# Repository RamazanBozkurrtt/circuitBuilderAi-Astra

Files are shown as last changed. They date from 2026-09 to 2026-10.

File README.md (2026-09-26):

# circuitBuilderAi-Astra

Product V1 is a two-board B2B ANC system: Board A (Controller + Audio AFE)
and Board B (Power + Stereo Class-D), with four microphone inputs and two
secondary speaker outputs.

The [Product V1 architecture](docs/product/ANC_B2B_Custom_PCB_2_Kart_Mimari_Tasarim_Dokumani_v1.0.docx)
is the product-level source. The [Phase R0 rebaseline](docs/rebaseline/phase_r0_b2b_two_board_rebaseline.md)
records its open decisions and the proposed repository migration.

The existing [KiCad project](hardware/kicad/) and earlier phase records are
**legacy four-output design history**, not Product V1 production files. Product
V1 KiCad projects have not been started.

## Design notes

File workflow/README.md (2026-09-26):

# Product V1 workflow

This directory holds process contracts, not electrical design. The controlled
checkpoint is `state/project_state.json`; the shared Board A/B signal-class
contract is `state/board_to_board_interface.json`. Actual findings go under
`validation/findings/`. Phase outputs remain in the normal `docs/`,
`hardware/` and `validation/` trees.

Install once: `python -m pip install -r workflow/requirements.txt`.

Run the current phase's machine checks:

```text
python workflow/gates/run.py
```

Preview a specific phase or a permitted transition without changing state:

```text
python workflow/gates/run.py --phase R6
python workflow/gates/run.py --next-phase R1
```

Exit code 0 means machine `PASS`, 2 means `BLOCKED`, and 1 means `FAIL`.
`PASS` means only that configured machine checks passed; the human/engineering
gate remains `NOT_EVALUATED`. A phase changes only after its human gate is
recorded and `state/project_state.json` is deliberately updated. The runner
does not advance phases or edit files.

The ERC, DRC, interface, pin and BOM hooks currently return
`NOT_AVAILABLE`. When one is required by a phase, the machine result is
`BLOCKED` until a real adapter and scoped verification artifact exist. Do not
replace `NOT_AVAILABLE` with a synthetic PASS.

The finding schema allows `accepted` and `deferred` statuses for review
history. A finding with `blocking: true` stops progression from its
`blocks_from_phase` onward until its status is `resolved`; acceptance or
deferral alone does not clear it. Each unresolved blocker must also appear in
the `open_blockers` state checkpoint with the same phase. This keeps later
blockers visible without blocking earlier verification work. The seven
product OPEN decisions are tracked separately from findings.

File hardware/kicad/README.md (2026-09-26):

# Legacy KiCad project

All KiCad files in this directory belong to the former single-board,
ADAU1978 / ADSP-21569 / TAS6424E-Q1, four-speaker architecture. Preserve
them as engineering history. They are **not** Product V1 production files or
schematic-entry authority.

Product V1 is the two-board design in
[`docs/product/`](../../docs/product/ANC_B2B_Custom_PCB_2_Kart_Mimari_Tasarim_Dokumani_v1.0.docx).
Its future Board A and Board B KiCad projects belong in separate directories
under `hardware/product_v1/` after a separately authorized schematic gate.

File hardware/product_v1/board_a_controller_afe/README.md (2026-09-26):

# Product V1 Board A

Controller + Audio AFE. Reserved for a separately authorized Board A KiCad
project. No Product V1 schematic or PCB exists here at R0.5.

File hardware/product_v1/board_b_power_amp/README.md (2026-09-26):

# Product V1 Board B

Power + Stereo Class-D. Reserved for a separately authorized Board B KiCad
project. No Product V1 schematic or PCB exists here at R0.5.

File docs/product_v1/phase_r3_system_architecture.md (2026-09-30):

# Product V1 Phase R3 system architecture and interface freeze

**Date:** 2026-09-28. **Authority:** the complete [two-board product architecture](../product/ANC_B2B_Custom_PCB_2_Kart_Mimari_Tasarim_Dokumani_v1.0.docx), [R1 requirements](phase_r1_product_requirements.md), [R2 manufacturer verification](phase_r2_component_verification.md), and its [evidence index](component_evidence_index.md). The project owner approved the R2 human gate before R3. This is a **system architecture contract**, not circuit, pin, connector, PCB or final acoustic approval. `CONFIRMED` means manufacturer/product evidence establishes the stated fact; `PROVISIONAL` means the selected architecture awaits R4 implementation proof; `OPEN` and `BLOCKED` identify missing evidence or a gate constraint. All four named ICs retain their R2 **PROVISIONALLY APPROVED** architecture status. Legacy devices and circuits are excluded.

## 1. Functional architecture and board ownership

```text
four external IM73A135V01 analog differential microphones
  -> Board A: four equivalent protected/filterable microphone entries
  -> Board A: four-channel analog AFE (network OPEN, no direct ADC connection assumed)
  -> Board A: TLV320ADC5140 ADC, four analog channels
  -> Board A: 96 kHz / four-slot TDM -> RT1062 SAI1 RX / DMA
  -> Board A: RT1062 ANC/FxLMS prototype, control and safety state machine
  -> Board A: SAI2 TX / DMA, stereo 96 kHz I2S
  -> controlled Board A-to-B interface
  -> Board B: TAS5825M, two BTL channels -> two secondary speakers
```

| Block | Owner | R3 classification and boundary |
| --- | --- | --- |
| Four electrically equivalent microphone channels | A | **CONFIRMED** product count/equality; IM73A135V01 **PROVISIONAL**. No reference/error/monitor role or placement assigned. |
| Differential entries, ESD/EMI/filter provisions and low-noise AFE | A | Provisions **CONFIRMED**; topology **OPEN**. R2 finds a direct mic-to-ADC loading conflict (mic ≥25 kΩ/leg; ADC ≤20 kΩ typical/leg). R4 must solve it without unequal channels. |
| TLV320ADC5140 and four-channel digitization | A | **PROVISIONAL** 96-kHz fixed-gain, AGC/DRE-off configuration supported by E-ADC-RATE Fig. 3-3. HPF, gain, phase and network **OPEN**. |
| RT1062 processing and DMA | A | **PROVISIONAL** resource architecture: separate SAI RX/TX with eDMA, no claimed final FxLMS capacity. Algorithm size and measured latency **OPEN**. |
| Stereo TAS5825M / BTL outputs | B | **PROVISIONAL** 96-kHz I2S architecture capable of a nominal 4-Ω load under the verified device limits. Final speaker impedance/choice and 12-V acoustic power **OPEN**. Speaker negatives never become signal or ground returns. |
| Protected input, 5-V buck, PVDD and local amp logic | B | Ownership **CONFIRMED**. Exact input range, protection/buck devices, current and thermal values **OPEN for R4/EVT**. |
| Bootable NOR, clock reference, USB and debug/programming | A | Ownership **CONFIRMED**; native NXP production route **PROVISIONAL**. Detailed pins/fuses/fixtures **OPEN for R4**. |
| Independent watchdog and cross-board safe request | A | Functional responsibility **CONFIRMED**. Independent monitor gates the enable line; Board B supplies fail-safe pull and local power/fault gating. Device and response timing **OPEN for R4**. |

Board A owns microphone entry and analog protection, ADC control, RT1062, external NOR, 24-MHz reference, both serial-audio masters, system I²C master, USB service, SWD/JTAG/pogo access, watchdog heartbeat/independent monitor and generation of its low-noise rails from Board B's 5 V. Board B owns external low-voltage DC entry, reverse polarity/OVP/OCP/eFuse functions, high-current protection, protected PVDD, 12-to-5-V buck, local 3.3-V amp logic, TAS5825M, output network/decoupling/thermal path, both BTL speaker connections, local hardware inhibit, and protected-power PGOOD/fault reporting. No functional ownership remains ambiguous; physical implementation details remain R4/R7 work.

## 2. Selected digital-audio and clock architecture

| Link | Transmitter / receiver | R3 baseline | Explicit clocks and voltage | Selection limit |
| --- | --- | --- | --- | --- |
| ADC to MCU | TLV320ADC5140 SDOUT slave transmitter → RT1062 **SAI1 RX clock master** | Four analog channels, 96,000 samples/s, 32-bit words in four 32-bit TDM slots; fixed gain, AGC/DRE off | `96,000 × 4 × 32 = 12,288,000 Hz` BCLK; 96,000-Hz FSYNC. ADC slave uses BCLK/FSYNC internal PLL, no ADC MCLK pin required. Both IOVDD/RT1062 SAI bank nominal 3.3 V. | E-ADC p.26 Table 6, E-ADC-RATE p.6 Fig.3-3 and E-MCU p.61 Table 50 establish endpoint rates. Exact SAI1 pin mux, edge polarity, divider, setup/hold, DMA and filter/HPF delay must be proven in R4. |
| MCU to amp | RT1062 **SAI2 TX clock master** → TAS5825M slave SDIN | Two channels, 96,000 samples/s, 32-bit words in two 32-bit I²S slots; amp process flow constrained to an R4 latency-measured profile | `96,000 × 2 × 32 = 6,144,000 Hz` BCLK; 96,000-Hz LRCLK. TAS5825M derives clocks from SCLK; **no Board B MCLK**. Both SAI bank/amp DVDD nominal 3.3 V. | E-AMP p.29 Table 9-1 and E-MCU p.61 Table 50 support rates. Exact SAI2 pin mux, output-clock common-root setup, connector loaded timing and amp DSP delay remain R4 proofs. |

This selects distinct TDM input and stereo I²S output framing; no frame-conversion wire crosses the boards. SAI1 and SAI2 use one RT1062 24-MHz XTALI reference and an audio PLL/common frequency family (PLL4 candidate), then separate integer-related BCLK/frame dividers. The 24-MHz reference is the NXP datasheet's typical XTALI clock for SDK/USB timing (E-MCU p.26 Table 11; [NXP official datasheet](https://www.nxp.com/docs/en/nxp/data-sheets/IMXRT1060CEC.pdf)); oscillator/crystal component values, actual PLL settings and root selection await the accessible reference manual/hardware guide in R4. NXP identifies PLL4 as its audio PLL in [manufacturer clock guidance](https://community.nxp.com/t5/i-MX-RT-Crossover-MCUs-Knowledge/RT-s-System-Clocks/ta-p/1151118). There is **one reference clock owner, Board A**. The ADC and amplifier are clock slaves. No independent audio oscillator or forwarded MCLK is in the baseline. MCLK is **excluded from the required board-to-board inventory** (`required_count: 0`).

Both links operate at the same **frequency**, but precise SAI frame phase/synchronization is **PROVISIONAL**. R4 must show that asynchronous start of two SAI blocks cannot cause sample-slip or unstable buffering, and must measure total microphone-to-speaker delay. Clock edges may toggle only after their receiver rails are valid; amp clock loss sends its output Hi-Z but automatically recovers (E-AMP pp.28–29), so **hardware enable must remain independent of clock presence**. The 48-kHz alternate remains a fallback requiring a formal architecture revision and ANC latency review.

## 3. Controlled Board A ↔ Board B electrical inventory

The [interface JSON](../../state/board_to_board_interface.json) is the normative, versioned R3 signal contract. **Ten active logical signal/return classes** require at least **14 provisional contacts**: two 5-V, four GND returns, three serial-audio, two I²C and three safety/status. The contact minima are architecture allocations, **not** proven current capacity; R4 calculates peak/continuous current, resistance/drop, temperature rise and connector derating and increases counts if needed. No connector series, shell or pin order is frozen. MCLK and spare/revision signals have zero required contacts. A keyed, retained, serviceable paired-board stack is required; the product's 10–15-mm stack is a planning class pending mechanics.

| Net | Source → sink; count | Nominal electrical/safe state | R4 circuit condition |
| --- | --- | --- | --- |
| 5V | B→A; ≥2 parallel contacts | Regulated nominal 5 V after B protection/buck; off/disconnected means no A supply. | Verify tolerance, inrush, current sharing, dropout and no USB/debug backfeed to B. |
| GND_RETURN | common A↔B; ≥4 contacts | Continuous low-impedance reference and power return. | At least one paired return near each power group and digital-audio group; allocate by measured current and connector geometry. |
| BCLK, LRCLK, AUDIO_DATA | A→B; one each | 3.3-V nominal CMOS, 6.144 MHz / 96 kHz / 32-bit stereo I²S. Inactive/undefined during boot is safe because B hardware inhibit is low. | Verify VOH/VIL, edge/termination, connector skew, powered-off injection; buffer only if those tests require it. Place nearby return contacts. |
| I2C_SDA, I2C_SCL | A master ↔ B slave data; A→B clock; one each | Nominal 3.3-V open-drain bus, idle high only while both domains valid; no transaction during B power-off. | Board A owns system pull-up/control; powered-off isolation on B side is **required** unless R4 proves a direct connection has no injection/backfeed. Address resistor, capacitance and speed to be fixed; B clock stretching is not assumed. |
| AMP_MUTE (`AMP_ENABLE` function) | A→B; one | **High = permission to release PDN for configuration/operation; low/open = hardware safe PDN low**. Board B pulls low by default and locally gates with B power-good. | A independent watchdog must remove permission on heartbeat failure; B cannot depend on MCU software to assert safe. Prove off-domain behavior and PDN threshold/response. This line is not synonymous with the amp's I²C soft-mute bit. |
| AMP_FAULT | B→A; one | Configured TAS5825M GPIO FAULTZ, active low; before GPIO configuration it is **invalid**. | Board A treats unavailable status during boot as no permission to Play. Choose open-drain pull-up on powered A side with off-domain protection; B local fault reaction cannot rely on A seeing this GPIO. |
| PGOOD | B→A; one | **High only while B protected PVDD path, B logic and 5-V delivery are valid**; low/open = unsafe. B local power-good also gates PDN. | Board B owns supervisor output; A input has fail-low default and powered-off isolation. Exact UV/OV thresholds and timing are R4 values. |

No level translation is needed **if** the two isolated logic sides meet a common 3.3-V logic specification at all loads and corners (E-MCU pp.25–26; E-AMP pp.6–7). That is an R4 measured/calculated condition, not an approval for bare direct interconnect. All signals must tolerate either board being unpowered without backfeeding or false enable. I²C isolation is required by contract; other buffering is conditional on R4 Ioff/drive/timing proof. `AMP_FAULT` is not a fixed-function hardware pin until the amp GPIO is configured, and PGOOD is external to the amp (E-AMP pp.4–5). No service or spare conductor is included by habit.

**Return/placement intent for R7/R8:** both boards have one coherent ground reference with low-impedance multiple contacts. Do not arbitrarily split AGND/DGND; partition by placement and current paths. Board B Class-D output/PVDD switching loops and speaker returns close on B, never through A or microphone shields. The 5-V feed has adjacent return contacts, and each fast audio group has nearby ground continuity. Board A AFE, mic entry and low-noise analog rails sit away from B's high-current converter and amplifier loops. Shield termination and exact trace/plane geometry await mechanical/EMI work.

## 4. Boot, NOR, power and safety responsibilities

**Boot direction (PROVISIONAL Product V1 selection): native NXP RT1062 Boot ROM → external boot-capable FlexSPI NOR XIP image.** R1's preference and R2's NXP ROM/manufacturing evidence support this without a stated Teensy compatibility requirement. PJRC compatibility would add its preprogrammed MKL02 and version-specific flash/tool dependency; no such requirement has been approved. Board A reserves ROM USB/UART recovery/boot-mode access and SWD/JTAG pogo; factory programming uses a controlled NXP ROM/flashloader image/fixture, and a wired USB service route is reserved for authenticated/controlled field maintenance. No OTA. Exact fuses/security policy, field-update rollback and factory fixture details remain R4/R14 decisions; no irreversible fuse is authorized here. This provisional architecture direction closes the R3 comparison only and needs owner sign-off before detailed boot-circuit release.

External NOR is mandatory. Use RT1062 boot-capable FlexSPI (the EVK boot pad group is the R4 starting route), quad IO0–IO3, CS#, SCK, VCC/GND, and XIP-compatible ROM configuration. A **1.8-V, 64-Mbit/8-MiB ISSI IS25WP064AJBLE-class** flash is the provisional manufacturer EVK baseline (E-EVK/E-FLASH), matched to a 1.8-V NVCC_SD bank; it is **not** a verified final MPN or minimum silicon capacity. R4 must check exact boot pad mux, flash command/SFDP/reset, package and supply/current, oscillator/PLL startup, NXP FlexSPI errata, image size and headroom. Reserve versioned, checksummed and redundant calibration/configuration sectors separate from executable image; factory pair identity belongs in controlled metadata. Final partition sizes and update rollback need firmware image budgeting, not a guessed flash size.

**Power ownership:** external nominal 12-V-class low-voltage DC enters B protection, then feeds TAS5825M PVDD and B's 5-V buck. B produces local nominal 3.3-V DVDD/control and hardware PGOOD. Product V1 keeps **12 V provisional**: protect/regulate against the eventual approved input range, and do not lock a regulator/protection topology to an unverified speaker-power conclusion. A receives 5 V and generates its own 3.3-V digital/IO, quiet 3.3-V ADC analog, ~2.75-V microphone/AFE, and 1.8-V flash/SD-bank domains. RT1062 SNVS/HIGH_IN/DCDC_IN/POR/DCDC_PSWITCH ordering and all powered NVCC banks follow E-MCU pp.25–31; ADC SHDNZ remains low through its rail settle and microphone channels receive their specified settle time. No nominal 3.3 V goes to IM73A135 VDD. B's TAS PVDD is 4.5–26.4 V and DVDD 1.62–3.63 V (E-AMP p.6); the 5-V rail does not directly power its logic. R4 must calculate worst-case startup/inrush, Board A digital/analog loads, simultaneous stereo power, protected-input and converter current, rail ripple/noise and thermal margins. The connector's 5-V path must carry `I_A,peak = Σ(rail output power / rail efficiency) / V_5V,min + service/debug and startup allowance`; return contacts must carry the matching worst-case current. The input/protection path must include simultaneous stereo PVDD input power plus 5-V-buck input power and faults. R3 has no reliable maximum for these terms, so **the 2-power/4-return contact floor is not current approval**.

**Independent safe-state contract:** Board B holds TAS PDN low by a local hardware default when enable wire is open, A or B is off, B PGOOD is false, or local hard fault requires shutdown. Board A's independent hardware watchdog/supervisor gates the enable permission, independently of normal ANC firmware execution. RT1062 internal WDOG/EWM is supplementary. During controlled configuration, the watchdog may permit PDN high while TAS remains in its reset **Deep Sleep**/commanded Hi-Z state: E-AMP p.48 §9.6.1.3 gives DEVICE_CTRL2 reset `00x10` (CTRL_STATE `00`, Deep Sleep); pp.42–43 specify PDN, clocks, Hi-Z/configuration, then Play ordering. A firmware crash after PDN release must time out the independent monitor and pull PDN low; an unconfigured FAULTZ is not the primary safety layer. Release to Play requires B PGOOD, A valid rails/clocks, watchdog heartbeat, ADC/audio initialized, link checks, amp configured in Hi-Z, self-test and READY. Hardware default **wins** over software Play. Normal shutdown commands Hi-Z/soft ramp, then PDN low before PVDD/DVDD removal. Emergency fault asserts PDN low without waiting for I²C. Exact timeouts, local fault latch/rearm, analog gating, and acoustic safe-response target are R4 evidence work.

## 5. Startup, shutdown and dependency audit

```text
external DC -> B protection -> B PVDD/5V/DVDD valid -> B local PGOOD
                                  |
                                  +-> A 5V -> A rails -> 24MHz XTALI -> RT1062 ROM/FlexSPI boot
                                                                      -> watchdog heartbeat
                                                                      -> ADC rail/SHDNZ/init
                                                                      -> SAI1/SAI2 clocks and DMA
                                                                      -> B I2C/amp configuration in Deep Sleep/Hi-Z
                                                                      -> audio/link/self-test -> READY
B local PGOOD AND A watchdog-gated AMP_ENABLE -> TAS PDN permission
READY AND configured Hi-Z AND healthy watchdog -> I2C Play -> ANC_ACTIVE
```

The dependency edges all move from supply and reference clock toward boot, audio configuration and output enable. **ACYCLIC = true.** B power-good does not wait for A, A boot does not wait for B I²C, and the watchdog can be serviced before amplifier configuration. PDN is temporarily released under watchdog supervision for I²C configuration while the TAS reset state is Deep Sleep; Play is a later explicit step. No clock or control is generated by B for A to boot.

| Event | Owner and deterministic reaction |
| --- | --- |
| Normal shutdown | A exits ANC, commands amp Hi-Z/soft mute, lowers enable/PDN, then B may remove rails after device timing. |
| MCU reset, stalled firmware, A power loss or B2B unplug | A independent monitor ceases permission or wire opens; B default pull drives PDN low. B PGOOD does not require A. |
| B PGOOD loss / brownout | B locally forces PDN low before relying on A notification; A stops audio and records fault if powered. |
| Amplifier FAULTZ or critical protection fault | B local amp hardware protection and PDN policy make output safe; A records fault and withholds Play/recovery. FAULTZ alone is not trusted before GPIO configuration. |
| I²C or audio-clock loss | A withholds/withdraws Play permission under a defined timeout; independent monitor covers firmware failure. Amp clock fault auto Hi-Z/recovery is not a latching safety policy. |
| Recovery | Re-enter BOOT_SAFE/SELF_TEST, require stable B PGOOD, fresh watchdog health, reinitialized ADC/amp and explicit READY; latch/rearm timing is R4. |

Dependency audit: power B→A; 24-MHz reference/SAI clocks A→ADC and A→B; ADC data→A; B amp I²C control A→B with slave acknowledgment B→A; amp audio A→B; enable A→B gated independently and locally; fault/PGOOD B→A; native boot A flash/ROM; watchdog A→B enable gate. Every active interface has defined direction and ground return. Powered-off-domain injection and loaded timing are explicit R4 proof obligations. No software-only safety edge or circular startup edge is accepted.

## 6. External decision boundaries and R4 handoff

- **ANC envelope:** 96 kHz, four capture channels and two output channels are the provisional processing schedule. The product's 80–800-Hz sweep is only a prototype investigation band, **not** an attenuation or latency acceptance mask. Controls/acoustic lead and owner must supply a measurable band, attenuation, latency and test method before performance qualification; R4 may design to this bounded prototype schedule while preserving margin. No final FxLMS capacity is claimed.
- **Speakers and 12 V:** retain both candidates and a Board B output path that can be evaluated with nominal 4-Ω loads; no speaker impedance or model is frozen. EVT in the actual crib must measure impedance versus frequency, Vrms/Irms at the minimum protected PVDD, attenuation across the approved band, THD, excursion, thermal behavior, simultaneous stereo loading, supply sag, protection trips and ANC reserve. D3/D4 stay open. If 12 V fails, reopen the B protection/buck/PVDD envelope and R3 interface assumptions; do not silently move to 24 V.
- **Mechanics:** dimensions, connector family, exact pin order and mounting remain open for R7. R4 has a 14-contact minimum planning floor, electrical classes, keying/retention and separation objective; current/EMI calculations can raise contact count. No physical shell is implied.
- **R4 electrical work:** read current RT1060 reference manual and hardware guide, choose exact silicon/flash/package, prove SAI pin mux/PLL/dividers/edges and connector loaded timing, finish mic AFE and four-channel equality, rail/current/protection budget, I²C/off-domain isolation, B PGOOD/local gate/watchdog timing and independent fault behavior. Schematic entry remains gated separately.

**Finding disposition:** All 13 R1 records were reviewed. R3 records provisional native boot and transfers its final production decision to R4; the cross-board electrical and serial-audio records carry the R3 baseline and R4 loaded/implementation proof; the quantitative ANC acceptance record moves to physical-performance qualification because no owner-approved mask exists. Their history remains in structured findings. Analog network, provisional power bound, hardware safe response and all speaker, mechanical and acoustic tests remain open. No blocker due by R3 is silently treated as resolved; the phase changes and reasons are explicit in the finding evidence/resolutions. The [R3 validation](../../validation/r3_system_architecture_validation.md) reports the machine gate and its limits.

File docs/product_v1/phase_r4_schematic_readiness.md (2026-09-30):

# Product V1 R4 schematic readiness and electrical preflight

**Disposition: BLOCKED (2026-09-28).** Board A and Board B remain the controlled two-board product. The owner accepted R3; the R3→R4 machine entry gate passed. This report is an R4 engineering audit, **not** authority to draw schematics. No Product V1 KiCad artifacts were created. R5 must not begin while the seven R4 blockers remain. `validation/r4_schematic_readiness_validation.md` records the reproducible machine result.

Evidence identifiers refer to [the Product V1 evidence index](component_evidence_index.md). `CONFIRMED` below means a manufacturer document supports the stated condition. `PROVISIONAL` identifies an engineering candidate needing the stated proof. `UNKNOWN` is an unfilled schematic value. The current NXP RT1060 reference manual (listed Rev 4, January 2026) and hardware guide Rev 7 (September 2025) are account-restricted from this environment. NXP datasheet Rev 4 and the older, NXP-hosted guide Rev 3 were read. Rev 3 is useful as a checklist but cannot silently replace Rev 7. This is a material limit for boot, supply, pad-default and decoupling freeze.

## 1. Device and package disposition

| Function | R4 production ordering candidate | Package/pin authority | Lifecycle / schematic disposition |
| --- | --- | --- | --- |
| 4× microphone | Infineon `IM73A135V01XTSA1` | PG-LLGA-5-2, five pads; E-MIC p.11 Table 8 and package pp.12–14 | Manufacturer product page active/preferred; exact OPN is **PROVISIONAL** until port/harness and AFE circuit close. |
| ADC | TI `TLV320ADC5140IRTWT` | RTW24 4×4-mm WQFN, exposed pad to AVSS; E-ADC pp.4–5, package pp.115–116 | TI part page active; exact OPN **PROVISIONAL**. |
| MCU | NXP `MIMXRT1062DVJ6B` | 12×12-mm, 196-ball MAPBGA, SOT1968-1; E-MCU-R4 pp.6–7, 103–111 | NXP's orderable table lists DVJ6B **Active** and DVJ6A **NRND** (E-MCU-LIFE). Freeze **B silicon candidate**; full symbol/rail/boot audit pending. |
| amplifier | TI `TAS5825MRHBR` | RHB32 5×5-mm VQFN, exposed PowerPAD to system ground; E-AMP pp.4–5, 92–94 | TI product page active; exact OPN **PROVISIONAL**. |

Each core device is single-source at the architectural level. Component status remains the R2 **PROVISIONALLY APPROVED** category; an exact order code is not schematic approval. The RT1062 B errata (E-MCU-ERR-B) apply: SAI transmit `ERR050144`, FlexSPI DLL wait `ERR011377`, system-reset/HAB condition `ERR050538`, cache/MPU errata and USB VBUS interactions remain implementation checks. Recheck the marking on purchased parts.

## 2. Board A microphone and AFE preflight

**Confirmed endpoint:** E-MIC pp.6–10 specifies normal-mode VDD 2.3–3.0 V, 2.75 V typical, 230 µA maximum per microphone under its stated ≤94-dB-SPL condition, 1.35-V nominal output common mode, 250-Ω typical output impedance, **at least 25 kΩ load on each output** and at most 100 pF load capacitance. Normal-mode start is 30 ms maximum after VDD reaches minimum. E-ADC p.28 Table 9 provides at most **20-kΩ typical** input impedance per leg. Direct mic→ADC loading is therefore contradictory; four identical isolation channels are required. The microphone 20-Hz low-frequency limit and measured acoustic phase must be respected; no reference/error role is assigned.

**Candidate only:** four dual OPA2320 unity-gain buffer packages, one buffer per differential leg, on a quiet 3.3-V analog rail. E-OPA documents rail-to-rail operation and 8.5 nV/√Hz typical voltage-noise density at 1 kHz. This can isolate each microphone from the ADC's input impedance. It is **not yet an approved network**: the exact OPA2320 order code, package, load, input/output swing at the selected temperature, output drive into coupling/ADC capacitance, rail transient, stability, cable/ESD capacitance, ESD clamp leakage, common-mode behavior and shutdown behavior are unverified as a whole. Mic port protection must preserve the ≤100-pF output load and ≥25-kΩ resistance. The manufacturer does not give a universal cable/ESD value.

Sensitivity −38 dBV at 94 dB SPL is `10^(−38/20) = 12.59 mVrms` differential (E-MIC p.6). An *illustrative linear extrapolation* by 41 dB to the published 135-dB-SPL, 10%-THD AOP gives 1.413 Vrms; allowing +1 dB sensitivity gives 1.585 Vrms. This is **not** a guaranteed maximum mic output or product SPL criterion. At unity gain, TI's 2-Vrms differential ADC full scale (AVDD 3.3 V, VREF 2.75 V; E-ADC p.28 Table 10) leaves only `20 log10(2/1.585) = 2.02 dB` illustrative electrical margin before coupling tolerance and PGA. ADC PGA must default 0 dB for a high-level capture mode; any positive gain reduces that margin. With +1 dB sensitivity, a balanced leg's illustrative peak is `1.585 × √2 / 2 = 1.121 V` around mic common mode, but output common-mode limits, clipping at AOP, cable pickup and active-buffer swing still need a guaranteed worst-case audit. No final high-SPL or noise-floor claim follows from this extrapolation.

For an AC-coupled ADC leg, `f_c = 1/(2π R_in C_eff)`. The nominal 20-kΩ setting would give 7.96 Hz at 1 µF and 0.796 Hz at 10 µF; at 80 Hz their single-pole phase shifts are approximately 5.68° and 0.57°. **Neither is frozen** because 20 kΩ is typical rather than a warranted minimum, effective capacitor value versus DC bias and temperature is unknown, and source resistance/filter topology adds poles. The ADC default 12-Hz HPF (E-ADC p.8) would itself shift phase roughly 8.5° at 80 Hz if left enabled; its exact digital response/register setting must be selected. The four channels must use the same analog values and firmware profile. Required R5 values still absent: coupling type/value/voltage/dielectric/tolerance, input bias path, series/filter/ESD components, ADC input impedance setting, PGA and HPF setting, and anti-alias/EMI response. No reproducible full-path simulation exists because these values are not frozen.

Noise sanity check, **typical-only and condition-limited**: mic 73-dB(A) SNR at 94 dB SPL implies `12.59 mV / 10^(73/20) ≈ 2.82 µVrms` A-weighted self-noise. A white 8.5-nV/√Hz OPA320 estimate over an arbitrary 20-kHz rectangular band gives ~1.20 µVrms per leg, ~1.70 µVrms differential, before 1/f noise, resistor/cable noise and bandwidth shaping. TI ADC 107-dB typical SNR at its specified **48-kHz, 0-dB-gain, A-weighted** condition corresponds to ~8.93 µVrms referred to 2-Vrms full scale. These dissimilar conditions cannot form a 96-kHz guaranteed noise budget. For any proposed resistor, use `e_n = √(4kTRB)` and the actual transfer function; a 1-kΩ resistor over 20 kHz contributes ~0.58 µVrms at 300 K before topology gains. A 96-kHz, four-channel, complete-band noise and phase simulation/bench plan is required to close `PV1-R1-001`.

## 3. ADC implementation preflight

E-ADC pp.4–5 fixes pins: 1 AVDD, 2 AREG, 3 VREF, 4 AVSS, 5 MICBIAS, 6–13 IN1± through IN4±, 14 SHDNZ, 15–16 address/SPI selection, 17 SCL, 18 SDA, 19 IOVDD, 20 GPIO1, 21 SDOUT, 22 BCLK, 23 FSYNC, 24 DREG, plus exposed pad. Candidate AVDD/IOVDD is 3.3 V, differential AC-coupled 2-Vrms full-scale mode. VREF needs ≥1 µF to AVSS; AREG/DREG, AVDD/IOVDD and MICBIAS use TI's reference network, with exact values/unused-pin dispositions still to freeze. Address is one of 7-bit 0x4C–0x4F (E-ADC p.57 Table 50); a strap choice and resistor values remain open. SHDNZ stays low through rail settling, then wait ≥2 ms before control traffic (E-ADC p.115). Its 96-kHz four-channel profile must disable AGC/DRE (E-ADC-RATE p.6 Fig.3-3), use slave TDM, four 32-bit slots, 12.288-MHz BCLK and 96-kHz FSYNC; no ADC MCLK. Select TI's low-latency/ultra-low-latency filter and HPF only after an end-to-end phase budget. ADC pin-level passive and register contract is **BLOCKED**.

## 4. RT1062 resource, power, boot and clock preflight

The [machine pin map](../../state/rt1062_pin_resource_map.json) records 23 **provisional mux-verified** package-ball allocations from E-MCU-R4 Table 69 and E-MCU-MUX. SAI1 RX uses AD_B1_10/11/12 for FSYNC/BCLK/data. SAI2 TX uses EMC_05/06/04 for LRCLK/BCLK/data. LPI2C1 uses AD_B1_00/01 for ADC; LPI2C3 uses AD_B1_07/06 for amplifier. FlexSPIA boot candidate uses SD_B1_06–11 on NVCC_SD1 1.8 V; service UART1 uses AD_B0_12/13. Heartbeat, amplifier request, PGOOD sense, FAULT sense and ADC shutdown each have distinct provisional GPIOs. No duplicate pad/ball occurs among these. **This is a partial map**: USB, crystal, POR_B, ONOFF, DCDC_PSWITCH, all rail balls, debug fixture and unused GPIO policy are not fully allocated, and a mux macro does not prove boot-ROM defaults or powered-off safety.

E-MCU-R4 p.85 Table 71 makes AD_B0_04/05 BOOT_MODE0/1 and B0_04–15 BT_CFG0–11 while BT_FUSE_SEL is clear. These pads are reserved from Product V1 functional allocation. AD_B0_06/07 and associated JTAG pads are also reserved for debug. This avoids the pin overlap hidden by otherwise plausible SAI1 and I²C2 mux choices. Exact boot-mode resistor values, BT_FUSE_SEL policy, fuse/image configuration block, flash command compatibility, ROM recovery entry, security/rollback and factory programming sequence require the current RM and manufacturing guide plus a fixture plan. The owner approval of R3 accepts the **provisional native NXP ROM/FlexSPI direction**, not these unfinished details. The ISSI IS25WP064AJBLE, 1.8-V 64-Mbit EVK part (E-EVK/E-FLASH) remains a candidate, not a frozen Product V1 flash MPN/package. USB ROM recovery and SWD/JTAG pogo access must be independently serviceable from application firmware.

E-MCU-R4 pp.25–31 gives DCDC_IN and VDD_HIGH_IN 3.0–3.6 V, VDD_SNVS_IN 2.4–3.6 V, VDDA_ADC_3P3 3.0–3.6 V, and 600-MHz VDD_SOC_IN 1.25–1.30 V; NVCC_GPIO is 3.0–3.6 V and selectable SD/EMC banks require their chosen 1.8/3.3-V range. SNVS must precede or be tied to HIGH_IN; DCDC_PSWITCH follows stable DCDC_IN, POR_B stays asserted until the final rail, and no external pad may be driven when its bank is off. The internal DCDC requires an external inductor/capacitor network. E-MCU-HW-OLD pp.2–7 suggests 4.7–10 µH, >1-A saturation and <0.2-Ω ESR plus distinct pin-local capacitor groups, but the current Rev 7 guide and the exact DVJ6B power/ball map must be checked before a BOM freeze. Table 12 max-current entries are under NXP's stated maximum-power test, not a complete Product V1 rail peak including I/O, USB and flash. No worst-case 5-V→3.3/2.75/1.8-V rail current/thermal proof exists. All regulator MPNs, guaranteed load conditions, capacitor DC-bias derating, ramp and reset margins remain **UNKNOWN**.

R3 audio clock math remains valid: `96,000 × 4 × 32 = 12.288 MHz` SAI1 BCLK and `96,000 × 2 × 32 = 6.144 MHz` SAI2 BCLK; frame clocks are 96 kHz. E-MCU-R4 p.61 Table 50 permits a master-BCLK period ≥40 ns; the two candidate periods are 81.38 ns and 162.76 ns. A 24-MHz RT1062 reference and PLL4 shared family are **PROVISIONAL**. Exact crystal MPN/load, PLL multiplier/dividers, SAI root, phase, pad drive and clock loss state are not frozen. Required sequence is power→reference→PLL/SAI→ADC slave PLL→valid data→amp configuration/PLAY, with independent PDN hold low until valid. There is no known startup cycle, but the exact hardware graph cannot pass while the power/safety circuits are absent. `ACYCLIC = true` applies to the R3 conceptual graph only.

## 5. Board B input, 5 V and amplifier preflight

Board B owns protected external nominal 12-V-class input, amp PVDD, a buck-generated 5-V feed to Board A, local 3.3-V DVDD and local default-off amplifier gate. E-AMP p.6 allows PVDD 4.5–26.4 V and DVDD 1.62–3.63 V; actual speaker headroom remains EVT. `P_in ≈ (P_left + P_right)/η + P_quiescent`; use actual frequency-dependent speaker impedance, simultaneous output, amplifier efficiency, supply drop and protection trip tolerance to size input/protected PVDD. The ideal BTL sine ceiling `V_rms < PVDD/√2` is only an upper bound. **No adapter tolerance/transient envelope, peak Board A current, speaker electrical limit, eFuse trip point, TVS clamp, reverse-protection device, 5-V buck MPN, local 3.3-V regulator or thermal limit is frozen.** Selecting a nominal 12-V-only buck would risk the unresolved headroom adjustment; select only after the allowed future input range is bounded. E-AMP's 7.5-A typical overcurrent and 28-V typical PVDD overvoltage are device protections, not a Board B input protection specification.

The 5-V connector budget must use `V_A,min = V_B,min − I_A,max (R_out + R_contact_power + R_contact_return + R_trace)` and account for contact aging, inrush and ripple. R3's two 5-V and four GND contacts are a **minimum inventory**, not proven current sharing or voltage-drop approval. No maximum Board A current, allowable 5-V receiving range or resistance budget is known. Any selected buck must be checked using **guaranteed** VIN/VOUT/load/temperature conditions, feedback reference and divider tolerance, min/max regulation, inductor saturation, output capacitor effective value, thermal dissipation and PGOOD behavior. None can be calculated to a valid final margin with the absent input/load envelope. The same applies to every Board A regulator. The legacy regulator/supervisor circuits were not reused.

E-AMP pp.4–5 fixes pins 1/24/28/29 BST_A+/BST_B+/BST_B−/BST_A−; 2/30 OUT_A+/OUT_A−; 23/27 OUT_B+/OUT_B−; 3/4/21/22 PVDD; 25/26/31/32 PGND; 5 DGND; 20 AGND; 6 DVDD; 7 VR_DIG, 18 GVDD, 19 AVDD bypass-only; 8 ADR; 9–11 configurable GPIO; 12 LRCLK, 13 SCLK, 14 SDIN; 15/16 SDA/SCL; 17 PDN. Its exposed pad connects to system ground. Outputs are BTL; neither speaker negative returns to GND. TI's bootstrap, rail decoupling, output LC/EMI and thermal reference guidance (pp.82–94) must become exact values/MPNs for R5, with inductor saturation and speaker harness assumptions. `FAULTZ` requires configuring a GPIO, so it is unavailable as a fixed preboot safe input. PVDD/DVDD can rise in either order; keep PDN low until both valid, then respect TI's ≥5-ms supply/PDN/clock/configuration phases (pp.42–43). Final output power is not frozen.

## 6. Board-to-board DC/timing and hardware safety

The [interface contract](../../state/board_to_board_interface.json) retains ten required classes: 2× 5 V, 4× GND, BCLK, LRCLK, audio data, SDA, SCL, AMP_MUTE/ENABLE, AMP_FAULT and PGOOD; MCLK and optional service are excluded. Audio is A→B, I²C SDA bidirectional, SCL A→B, AMP_MUTE A→B, FAULT and PGOOD B→A. A shared low-impedance return with adjacent clock/power GND is required; no arbitrary split in cross-board ground. Board B PVDD and speaker switching loops stay local to B, away from A's mic AFE. Mechanical connector, pin order and current-rated contact family wait for R7, but that does not waive R4 electrical current and timing proof.

At 3.3-V nominal TAS DVDD, E-AMP p.7 requires `VIH ≥0.7×DVDD` and `VIL ≤0.3×DVDD`; across its 1.62–3.63-V allowed range the worst rising threshold can be 2.541 V at 3.63 V. A 3.3-V nominal output is **not** a worst-case VOH guarantee. For each output the required inequalities are `VOH_min(source, I_load) − VIH_max(receiver) > 0` and `VIL_min(receiver) − VOL_max(source, I_sink) > 0`, with receiver absolute maximum and unpowered clamp current checked separately. I²C additionally needs pull-up ownership, R/C rise time, bus capacitance, low-level current and isolation during unequal rail startup. For 6.144-MHz BCLK, period is 162.76 ns; frame is 10.417 µs. The sender's data-valid/clock edge, pad delay, connector flight/skew, receiver setup/hold and loaded rise/fall must fit the appropriate half-cycle. The R2 protocol match does **not** supply these loaded margins. Each active signal now has explicit `null` DC/timing margins in the JSON audit; no fabricated PASS is recorded. Board B MCLK is not required by TAS5825M's three-wire serial port (E-AMP pp.28–29).

Independent safe-state requirement is retained. Functional Boolean contract: `PDN_RELEASE = B_POWER_GOOD ∧ A_PRESENT ∧ WATCHDOG_VALID ∧ MCU_ENABLE_REQUEST ∧ NO_LOCAL_HARD_FAULT`; every unknown/open/low input inhibits PDN. The Board B pull/gate must hold PDN low with A disconnected or unpowered, B logic ramping, watchdog missing, and MCU reset; firmware alone cannot release it. A must send a heartbeat only after self-test, while B must obtain a power-good and fault decision locally. `AMP_FAULT` is advisory to A until TAS GPIO configuration; a B local fault path must inhibit independently. A communication failure policy must have a bounded timeout independent of indefinite I²C polling. **No exact independent watchdog/supervisor/gate MPN, polarity-level proof, timeout, latch/rearm policy, or PDN response time is selected.** Any supervisor must prove `V_valid_min > V_RISE,max` and `V_invalid_max < V_FALL,min`, including reference and divider tolerances, hysteresis, delay, ripple and load; neither margin exists yet. This keeps `PV1-R1-011` open.

The hardware dependency order is DC input→protection→5 V and B local logic→A rails→reference/MCU reset→flash ROM boot→ADC clock/config→B amplifier config in PDN released but DSP safe state→READY/watchdog qualification→controlled PLAY. A fault, PGOOD loss, disconnection or watchdog timeout drives B's local gate to PDN low without firmware execution; recovery returns through boot/self-test rather than automatic clock-fault replay. This is a proposed ordering, **not an implemented verified graph**. With no gate/supervisor components, powered-off clamp/driver behavior and all threshold values remain unproven.

## 7. Connectors, passives, hierarchy and sheet readiness

Mic ports: four identical differential pairs plus mic VDD and return, shield strategy and ESD/load/cable-capacitance budget; no role-specific wiring. Speaker ports: two separately keyed BTL pairs; neither negative lead touches chassis/GND. DC input: keyed power/return sized for simultaneous stereo and buck peak, with protected test access. USB service: USB OTG1 D+/D−/VBUS/GND and ESD/ID policy to freeze from current NXP guide. Debug fixture: SWD/JTAG, reset, power reference and boot/recovery access independent of application boot. B2B: at least 14 provisional contacts before current/ground/timing proof, keyed and separable, with high-current and Class-D fields separated from clock and mic paths. R7 freezes exact connector shells/geometry.

Passive BOM is **not deterministic**. Mic 100-nF local VDD bypass is confirmed (E-MIC p.10), ADC VREF ≥1 µF is confirmed, and NXP older guide provides pin-local/bulk groups; all rail capacitance must be rated at actual bias, temperature and voltage. TAS bootstrap and PVDD/logic decoupling follow E-AMP reference, but their values, dielectric, tolerance, ESR and placement class have not been transcribed into a verified R4 bill. Flash pull-ups/write-protect/reset, boot straps, I²C pull-ups, series clock damping, amplifier ADR resistor, external watchdog RC, DC TVS/eFuse current resistor, regulator divider/inductor and output EMI filter remain unfrozen. Layout placement and geometry belong to R7/R8, while schematic values belong to R4.

The [Board A contract](../../state/board_a_schematic_contract.json) names seven sheets A1–A7; the [Board B contract](../../state/board_b_schematic_contract.json) names five B1–B5. Each sheet lists its specific blocking reason and is **BLOCKED**. This is an explicit R5 hierarchy plan, not a claim of readiness. No sheet qualifies as READY or READY WITH DOCUMENTED PROVISION while its major circuit topology/value/part or pin map is missing.

## 8. Findings, closure work and R5 boundary

All 13 original R1 findings were reviewed; no history was deleted. Seven due by R4 remain blocking: `PV1-R1-001` AFE, `002` exact native boot, `004` provisional electrical/power envelope, `009` cross-board loaded contract, `011` hardware safe state, `012` power/protection, and `013` SAI/serial timing. They now carry this audit as additional evidence. The other six remain scheduled to their physical, acoustic or mechanical phases; datasheet analysis does not close them. The R3 owner approval is evidence for the *provisional* boot direction, not an assumed field-update/security decision.

Before R4 can be rerun for PASS, obtain the controlled NXP RM/Rev 7 guide and close the full RT1062 power/boot/debug pin map; freeze and calculate the complete mic buffer/coupling/filter/ESD network and 96-kHz ADC profile; bound the adapter, 5-V and audio power loads; choose and worst-case-verify every regulator/protection/supervisor/watchdog and critical passive; prove B2B DC/timing/off-domain behavior; and produce a hardware gate truth table and timed startup/fault recovery. Each sheet must then be promoted individually on evidence. These are R4 tasks, not choices delegated to R5. The current machine gate must remain **BLOCKED**. ERC/DRC are `NOT_AVAILABLE` until authorized KiCad work; neither has been simulated or claimed.
## 9. R4 closure pass (2026-09-28) - original BLOCKED history retained

The owner could not supply authorized copies of NXP `IMXRT1060RM` Rev 4 (January 2026) or `MIMXRT105060HDUG` Rev 7 (September 2025). Both are marked account-required on NXP's current RT1060 product page. Earlier public NXP documentation was used only for the limits it states. Exact boot, SAI clock configuration, and current hardware recommendations remain **MISSING_AUTHORITATIVE_EVIDENCE**. The required sections are identified below; exact page numbers cannot be supplied without the restricted copies. No finding was deleted or downgraded to make the gate pass.

### Exact seven R4 blockers and closure proof

| Finding | Board/block | Technical reason and exact closure | Authoritative evidence still required |
| --- | --- | --- | --- |
| `PV1-R1-001` | A, four mic/AFE/ADC channels | Direct mic loading contradicts the microphone's 25-kohm-per-leg minimum; exact buffer, coupling, filter, ESD, gain, phase and noise values are missing. Close with four identical, worst-case verified circuits and targeted reference/bench proof. | Infineon IM73A135 v1.20 pp.6-11; TI TLV320ADC5140 SBAS892A pp.7-9, 28-29, 108-116; TI OPA2320 SBOS513F pp.6-9; selected ESD and capacitor manufacturer curves. |
| `PV1-R1-002` | A, RT1062 native boot/flash | Boot strap and FCB/fuse values, exact flash order code and programming/recovery path are not proven; the pin map is partial. Close with a verified ROM boot and fixture contract without conflicts. | NXP `IMXRT1060RM` Rev 4 **System Boot**, **Fuse Map**, **FlexSPI**, **IOMUXC** and **CCM** sections; NXP `MIMXRT105060HDUG` Rev 7 **boot, reset, crystal, power, decoupling and debug** sections; ISSI exact flash datasheet. These two current NXP documents are access-restricted. |
| `PV1-R1-004` | B, input/PVDD/speakers | The 12-V-class adapter min/max/current and stereo load envelope are not product-bounded. Close a provisional electrical envelope and worst-case protection/thermal budget while leaving EVT headroom open. | TI TAS5825M SLASEH7H pp.6-10 and amplifier/output-filter sections; manufacturer's selected buck/eFuse/TVS/FET data; owner adapter envelope and speaker electrical range. |
| `PV1-R1-009` | Interface, power/audio/control | Contact current/drop, loaded serial timing, I2C/off-state and mute/fault/PGOOD margins are incomplete. Close every required cross-board signal with source/receiver, DC, timing, load and unpowered proof. | NXP RT1060 CEC Rev 4 Tables 22, 50; TI TAS5825M SLASEH7H pp.6-10; TI SN74LVC1G125 SCES223U pp.4-7; TI TCA9800 SCPS264B pp.4-7; exact selected rail/contact data. |
| `PV1-R1-011` | A/B, hardware safe state | Watchdog, supply supervision and fail-low gate have no exact circuit or approved response-time bound. Close with a threshold/hysteresis and fault truth-table proof independent of firmware. | TI TPS3431 SNVSB66A pp.3-7, TPS3760 SBVS420A pp.3-9 and selected logic datasheet; TI TAS5825M PDN requirements; owner safety response-time target. |
| `PV1-R1-012` | A/B, rails/protection | Peak current, regulator feedback/guarantee conditions, output caps, eFuse thresholds and B2B drop are not frozen. Close full guaranteed rail/protection budgets, including supervisor release margins. | NXP RT1060 CEC Rev 4 pp.25-31; current NXP HW Guide Rev 7 power/decoupling sections (**restricted**); TI TPS62135 SLVSBH3B pp.4-7; TPS54334 SLUSC26A pp.4-6; TPS2663 SLVSE94G; selected passives and owner adapter/current envelope. |
| `PV1-R1-013` | System, SAI/clock/audio | 96-kHz framing is feasible, but exact SAI divider/phase/DMA profile, loaded timing and full latency are not frozen. Close the programmed clock roots, synchrony, setup/hold, DMA and end-to-end latency envelope. | NXP `IMXRT1060RM` Rev 4 **CCM/Audio PLL**, **SAI**, **eDMA** and **IOMUXC** sections (**restricted**); NXP RT1060 CEC Rev 4 Table 50; TI ADC SBAS892A and amp SLASEH7H serial timing sections. |

### Public-evidence calculations that narrow, but do not close, the blockers

`validation/r4_closure_calculations.py` reproduces these **conditional** figures. NXP CEC Rev 4 Table 22 gives 3.0-V-bank GPIO `VOH >= 2.85 V` and `VOL <= 0.15 V` at the stated <=1-mA drive. A Board B `SN74LVC1G125` at 3.0-3.6 V needs `VIH >= 2.0 V`, `VIL <= 0.8 V`, yielding 0.85-V HIGH and 0.65-V LOW input margins. With its output loaded <=100 microA, `VOH >= VCC-0.1 V` and `VOL <=0.1 V`. The buffer and TAS must use the **same** local Board B 3.0-3.6-V rail: at the common 3.0-V lower corner, TAS `VIH =0.7 DVDD` and `VIL =0.3 DVDD` give 0.8-V HIGH and LOW margins. Separate 3.0-V buffer and 1.62-V TAS supplies could violate the TAS `DVDD+0.5-V` digital-input absolute maximum. **Caveat:** TI labels TAS electrical characteristics as 25-C free-air values, not a guaranteed full-temperature logic threshold. These are conditional operating-point calculations, not a temperature-corner proof. Direct A-to-unpowered-B connection is invalid. The LVC buffer has `Ioff <=10 microA` with VCC=0 and a 5.5-V input/output; use is a candidate isolation approach, with OE/power-ramp state and board-level clamp path still to prove.

For the amp link, `96,000 x 2 x 32 = 6.144 MHz`, period `162.760 ns`. NXP Table 50 permits a 40/60-percent master BCLK and 15-ns maximum clock-to-TXD-valid, with 0-ns minimum clock-to-TXD-invalid. TAS p.10 requires 8-ns data setup and hold and 8-ns LRCLK/SCLK separation. The 125-C `SN74LVC1G125` 30/50-pF propagation range is 1.0-4.7 ns. If total differential interconnect/receiver edge uncertainty is **bounded to 5 ns**, the shortest 40-percent phase is 65.104 ns, giving conditional data setup `65.104-15-(4.7-1)-5-8 = 33.404 ns` and hold `65.104-(4.7-1)-5-8 = 48.404 ns`. A complete proof still needs NXP's exact configured launch edge, LRCLK phase, source output timing at the real capacitive load, mechanical interconnect bound, buffer OE sequencing and TAS temperature characterization. The analogous ADC link is `96,000 x 4 x 32 = 12.288 MHz`; exact SAI1 framing/PLL remains open.

The TI `TCA9800` is a possible I2C isolation device, but its specified maximum SCL is **100 kHz** (SCPS264B p.7), so a future 400-kHz assumption would be false. Its B-side internal current source forbids external B-side pull-ups; A-side ownership, receiver leakage and full off-state proof remain unresolved. The TI `TPS54334` has a feedback reference of 0.788-0.812 V across the stated VIN 4.2-28 V and TJ -40..150 C (SLUSC26A p.5); this makes it a stronger 5-V buck *candidate* than a reference whose accuracy is specified only at VIN=12 V, but no divider, inductor or current/thermal proof was completed. `TPS7A2028PDQNR` is a possible 2.8-V microphone LDO: TI's +/-1.5-percent condition gives 2.758-2.842 V, within the mic's 2.3-3.0-V range, **only if** VIN remains at least the nominal 2.8 V plus 0.3 V (3.1 V), IOUT stays 1-300 mA, and TI's capacitor/temperature conditions hold. A generic 3.0-V-min 3V3 rail cannot meet that guaranteed VIN. This candidate is therefore not a frozen rail circuit.

No R5 sheet was promoted to READY. The boot/power/safety/clock choices above are candidates, not authority for Astra to fill unproven circuits. Product V1 KiCad artifacts remain NOT_AVAILABLE.

## 10. Owner-input and authorized-manual closure audit (2026-09-30)

**Result: BLOCKED; prior results in sections 1–9 are historical.** The owner supplied authorized NXP `IMXRT1060RM` Rev. 4 and `MIMXRT105060HDUG` Rev. 7 PDFs and clarified Product V1 input power and safety. The two NXP documents are indexed as E-MCU-RM4 and E-MCU-HW7. References below use physical PDF pages. Their previous access restriction is resolved; no R4 finding remains blocked *because those PDFs are unavailable*. This access change does not prove unfinished circuits.

### 10.1 Owner requirements and provisional engineering boundary

The PoC 12 V/10 A adapter is **not** a Product V1 requirement. Retain 12 V nominal only as an engineering baseline. The final adapter voltage and model remain TBD after protected rail, thermal, speaker and acoustic validation. Reverse polarity, OVP, OCP and short-circuit protection remain required. For screening the power design, use an **8–18 V candidate operating range at the external input**, subject to protection drop and regulation; this is a proposed engineering envelope, not a production rating. The endpoint limits themselves are TAS5825M PVDD 4.5–26.4 V and DVDD 1.62–3.63 V (E-AMP p.6); the chosen buck, eFuse, TVS and reverse-polarity circuit must keep their respective pins and PVDD inside guarantee and fault limits over input tolerances and transients. The candidate 8–18 V range is not yet validated by a complete selected power circuit.

For an **electrical sizing screen only**, two ideal full-scale BTL sine channels at 3.2-ohm minimum permitted load give `P_out,ideal <= V_PVDD^2 / 3.2`: 20 W at 8 V, 45 W at 12 V and 101.25 W at 18 V. This ignores amplifier loss, voltage drop, thermal limits, gain setting and output limiting; it is neither attainable production power nor an acoustic permission. With an *unverified conservative efficiency assumption* of 70%, an illustrative 10-W Board A budget, an assumed 85%-efficient 5-V buck and 25% current allowance, the screening formula is `I_adapter >= 1.25 × [V_PVDD/(3.2 × 0.70) + 10 W/(0.85 × V_input)]`; at 12 V it gives approximately **7.9 A**, at 18 V approximately **10.9 A**. The assumed Board A load and efficiencies are not guaranteed; neither figure approves an adapter or the eFuse rating. A valid R4 power budget requires per-device worst-case current, amplifier continuous/transient/limiter operating point, protection and buck losses, and thermal testing. The PoC 10-A label is not used as evidence.

The production safety document requires independent output limiting, watchdog, hardware mute, fault-default silence and controlled release. The owner supplied `<=10 ms` as a **provisional circuit-engineering mute target only**. It is not a certified response limit, acoustic acceptance limit, or compliance claim. The final production response criterion and numeric baby SPL acceptance remain open for later independent safety/acoustic evaluation (exposure duration, geometry, peak/transient, clinical input). E-AMP p.7 lists a 10-ms turn-off figure **excluding volume ramp** at its stated test condition; it cannot establish a worst-case fault-to-silence bound under all rails, temperatures, firmware states and speaker loads. The previously considered TPS3431 has a fastest *specified recommended-capacitor typical* timeout of 62.74 ms (E-WATCHDOG p.4), so it cannot itself detect a crashed heartbeat within 10 ms. A screened faster family, E-WATCHDOG-FAST-SCREEN p.3 Table 2, offers a W-option watchdog range of 4.3–9.3 ms, but its 9.3-ms maximum leaves at most 0.7 ms for logic and output decay and does not establish the whole response. A selected hardware gate, supervisor and watchdog need combined worst-case detection + propagation + amplifier/output decay below the provisional target, or a separately proven speaker disconnect strategy. Acoustic finding `PV1-R1-008` remains open for R14 and does not itself bar R5.

### 10.2 NXP ROM, resources and clocks now verified

E-MCU-RM4 pp.193–200 establishes BOOT_MODE[1:0] `00` Boot From Fuses, `01` Serial Downloader, `10` Internal Boot, `11` reserved; `00` with BT_FUSE_SEL=0 enters downloader, and `10` with BT_FUSE_SEL=0 uses GPIO boot configuration. Production fuse boot is recommended by NXP, but its one-time provisioning and security policy must be controlled. ROM boot from FlexSPI A uses SD_B1_06/07/08–11 for CS/CLK/IO[0:3]; FlexSPI B cannot directly supply the first ROM image. E-MCU-RM4 pp.210–214 gives a 512-byte FCB at flash offset zero and 30-MHz initial read. E-MCU-HW7 pp.9 and 14–15 requires valid BOOT_CFG[0:11] levels until fuses supersede them and documents USB1/LPUART1 downloader. The exact flash manufacturer order code, FCB command/LUT, strap resistor matrix, fuse provisioning and recovery test remain absent. These now are **implementation gaps**, not missing NXP-source gaps. The partial but collision-free pad map is in `state/rt1062_pin_resource_map.json`.

E-MCU-HW7 pp.2–6 supplies the current power/decoupling and DCDC requirements: SNVS power must precede or tie to VDD_HIGH_IN; DCDC_PSWITCH uses a 5–15-ms RC and must reach 1.5 V at least 1 ms after DCDC input stability; POR_B stays asserted until all rails are valid. The internal DCDC needs a 4.7–10-uH external inductor with saturation >1 A and ESR <0.2 ohm and 33 uF total output capacitance. Its Table 2 lists pin-domain capacitor quantities and values. E-MCU-HW7 p.7 requires a 24-MHz fundamental crystal (ESR <80 ohm, CL <=12 pF) for the SDK clock plan, with 2.2-Mohm XTALI-to-ground bias. Its pp.7–10 specify SWD default, JTAG_MOD/TRSTB 4.7-kohm low terminations, LPUART1 10-kohm pullups, boot-strap bias and POR_B supervision guidance. Exact production crystal, effective capacitors, reset circuit and the whole rail-load budget are still missing.

An exact *frequency* plan follows E-MCU-RM4 pp.1028, 1052, 1056–1058, 2000 and 2016: 24-MHz reference; PLL4 `DIV_SELECT=32, NUM=96, DENOM=125` gives 786.432-MHz VCO; post-divide 4 gives 196.608 MHz. SAI1/SAI2 root selection PLL4 with PRED=2, PODF=4 gives 24.576 MHz to each; SAI1 RX bit-clock DIV=0 yields 12.288 MHz for four 32-bit slots at 96 kHz; SAI2 TX DIV=1 yields 6.144 MHz for two 32-bit slots at 96 kHz. `validation/r4_closure_calculations.py` asserts this arithmetic. The RM p.1977 says synchronous mode across **different SAI peripherals is unsupported**. A shared PLL locks average rates but does not define relative frame phase; DMA buffering, start alignment, drift/fault handling and total latency must be specified and tested. The audio plan is frequency-coherent, not yet a complete registered/DMA implementation contract.

### 10.3 Seven-finding closure check

| Finding | New evidence or owner input applied | Remaining exact R5-blocking work |
| --- | --- | --- |
| `PV1-R1-001` mic/AFE | Four identical channels and Infineon/TI endpoint limits remain valid; new NXP documents do not determine the analog network. | Select and prove buffer supply/input-output swing, impedance, coupling, bias, protection capacitance/leakage, anti-alias/EMI values, worst-case low-frequency phase and ADC headroom/noise at 96 kHz. An illustrative AOP extrapolation is not a guaranteed maximum. |
| `PV1-R1-002` boot | E-MCU-RM4 and E-MCU-HW7 close the previous manual access gap, boot mode meanings and default FlexSPI A pads. | Freeze exact flash order code and voltage/package, boot resistor matrix, FCB, factory fuse/security policy, fixture/recovery and complete reset/crystal/debug circuits; verify at bench. |
| `PV1-R1-004` input/headroom | Owner explicitly permits engineering derivation and leaves adapter/model/headroom open; the 8–18-V candidate and sizing equation above bound component selection work. | Select protected input and 5-V circuitry, calculate guaranteed current/thermal/voltage range and budget from real Board A and amplifier limits; later EVT still decides production 12-V/headroom and speakers. |
| `PV1-R1-009` board interface | NXP pin and clock resources are now mapped; amp-link conditional 25-C DC and timing estimates in section 9 remain useful. | Freeze actual 5-V/return contact rating and drop, isolation/buffer/I2C/PGOOD circuits and prove every loaded DC, timing and off-domain corner. |
| `PV1-R1-011` safe state | Owner authorizes <=10-ms provisional design target and confirms default hardware mute requirement. | Select watchdog/supervisor/gate, calculate threshold/release hysteresis and total worst-case fault-to-mute response, verify amplifier PDN/output response without firmware, define recovery. |
| `PV1-R1-012` power | E-MCU-HW7 resolves NXP sequencing and DCDC network guidance; owner removes the arbitrary 10-A adapter assumption. | Select all Board A/B regulators and protection, calculate guaranteed rail ranges, current/thermal/cap derating, B2B drop, supervisor thresholds and cyclicity; no generic typical-current sizing. |
| `PV1-R1-013` audio timing | E-MCU-RM4 resolves PLL4/SAI divider frequencies and confirms no cross-SAI hardware synchrony. | Freeze exact SAI framing/control/DMA, full ADC and amplifier setup/hold over temperature and load, link skew bound, measured or bounded total latency. |

TI E-ADC p.12 specifies SDOUT delay up to 18 ns at **25 °C and 20-pF load**. E-MCU-R4 SAI receive setup is 15 ns. At 12.288 MHz, a nominal half-cycle is 40.69 ns, leaving `40.69−18−15=7.69 ns` **before** clock/data skew, or 2.69 ns with a proposed 5-ns skew. This is not a full-temperature or loaded guarantee. The ADC input timing, interconnect and any buffer propagation must be proven or the framing/edge plan amended explicitly before R5. The amplified link's conditional calculations in section 9 similarly do not prove every operating corner.

One concrete timing mitigation remains available without changing the 96-kHz sample rate: TI E-ADC pp.20–22 permits 24-bit output words and matching 24-bit TDM slots. Four slots would use 9.216-MHz BCLK. E-MCU-RM4's PLL/divider equations permit 24 MHz × (36 + 108/125) = 884.736 MHz PLL4 VCO, `/4 = 221.184 MHz`; SAI1 root `/3/4 = 18.432 MHz` and RX BCLK `/2 = 9.216 MHz`, while SAI2 root `/3/3 = 24.576 MHz` and TX BCLK `/4 = 6.144 MHz`. Under the same *25 °C, 20-pF and assumed 5-ns skew* conditions, ADC setup room would grow to `54.25−18−15−5 = 16.25 ns`. This is a **candidate R3 framing amendment, not a frozen R4 contract**: full-temperature timing, clock/data edge and DMA/word-packing tests remain necessary. It cannot be substituted silently for the present four-by-32-bit baseline.

The seven findings therefore remain OPEN and blocking. They were not downgraded to make the gate pass. The machine contracts retain `BLOCKED` / `r5_ready=false`; the newly verified NXP and owner facts are incorporated for the next closure work. No KiCad artifact was created or changed, and R5 is not authorized.

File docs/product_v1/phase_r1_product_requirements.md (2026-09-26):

# Product V1 — Phase R1 requirements and open-decision control

**Authority:** [Product two-board architecture v1.0](../product/ANC_B2B_Custom_PCB_2_Kart_Mimari_Tasarim_Dokumani_v1.0.docx), draft 26 September 2026, SHA-256 `df537a98c9bbfdef1dd5bf8447441946985fb8e6b438e1ae9e7990510d5c6f44`. [R0 rebaseline](../rebaseline/phase_r0_b2b_two_board_rebaseline.md) and [R0.5 workflow](../rebaseline/phase_r0_5_workflow_infrastructure.md) were reviewed. The unchanged product document was previously read in full and its relevant sections/tables were reinspected for R1. The source's other named PoC, speaker, certification and market documents were not available here. Legacy IC architecture supplies no Product V1 evidence.

**Classification:** `CONFIRMED` means an explicit product-level requirement in the architecture source, **not** verified electrical feasibility. `PROVISIONAL` means a stated target or starting choice requiring later verification/approval. `OPEN` means a missing decision or quantitative contract. `CONFLICTING` is reserved for real disagreement; none was established in the product source during R1. Requirements are not silently relaxed to retain a target component.

## 1. Product V1 acceptance matrix

The matrix is the controlled R1 baseline. “Due” is the earliest phase gate requiring closure or a formally bounded disposition; later physical/production proof can remain open as separately identified. Product owner, controls/acoustic lead, mechanical partner and safety lab are **resolution sources**, not assigned named people.

| ID | Requirement / decision | Status | Board | Owner / evidence source | Due | Closure criterion |
| --- | --- | --- | --- | --- | --- | --- |
| SYS-01 | One product, Board A Controller + Audio AFE and Board B Power + Stereo Class-D | **CONFIRMED** | System | Product doc §1.1 | R0 | Two-board boundary retained. |
| SYS-02 | Four simultaneous analog microphone inputs and two secondary speaker outputs | **CONFIRMED** | A+B | Product doc §§1.1, 2.2 | R0 | Preserve counts; no old four-output path. |
| SYS-03 | Real-time, low-latency ANC/FxLMS processing | **CONFIRMED** intent | System | Product doc §2.2 | R3/R12 | Define measurable target and later prove feasibility; see SYS-04. |
| SYS-04 | Quantitative ANC band, attenuation and latency acceptance | **OPEN** | System | Product owner + controls/acoustic lead; §2.2 and figure 1 | R3 | Approve measurable target or bounded prototype envelope; [finding 010](../../validation/findings/PV1-R1-010.json). |
| SYS-05 | External low-voltage DC; no mains routed into crib | **CONFIRMED** | B | Product doc §2.2 and figure 1 | R3 | Maintain protected external-DC architecture. |
| SYS-06 | No Wi-Fi/Bluetooth or OTA requirement in v1 | **CONFIRMED** | System | Product doc §§1.1, 7.2 | R1 | Do not add wireless as a default requirement. |
| SYS-07 | Hardware-safe mute during power-off, boot, reset and critical fault; software is not sole safety layer | **CONFIRMED** | A+B | Product doc §§2.2, 6, 7.1 | R4 | Define default states and response target; see SYS-08. |
| SYS-08 | Quantified mute/fault timing and cross-board safe-state contract | **OPEN** | Interface | Product/safety input + §9 EOL | R4 | Approved default/polarity/dependency/response contract; [finding 011](../../validation/findings/PV1-R1-011.json). |
| SYS-09 | B2B embedded integration, factory/service access and paired-board traceability/EOL | **CONFIRMED** | System | Product doc §§1, 8–9 | R14 | Production records link Board A/B pair, firmware and calibration. |
| SYS-10 | POWER_OFF, BOOT_SAFE, SELF_TEST, READY, ANC_ACTIVE and FAULT_MUTE behavior | **CONFIRMED** product behavior; timing **OPEN** | System | Product doc §7.1 | R4/R12 | Preserve silent boot/self-test/fault states; define timing and validate fault response. |
| SYS-11 | Remove PoC-only microSD, headphone, potentiometers, extra codec/DAC, primary and spare outputs | **CONFIRMED** | System | Product doc §§1–2, 11 | R1 | Do not reintroduce without a new product decision. |
| SYS-12 | EVT→DVT→PVT and fixture-based EOL with channel, boot, fault/mute and paired-board records | **CONFIRMED** process; sample counts **PROVISIONAL** | System | Product doc §§8–10 | R14 | Retain physical evidence and factory test limits before release. |
| SYS-13 | Cost reduction must retain protection, watchdog, mute, ESD/EMI and EOL test | **CONFIRMED** constraint | System | Product doc §11 | R13 | Cost-down review cannot remove these functions. |
| SYS-14 | 400 units/year and four 100-unit releases are planning assumptions, not supplier commitments | **PROVISIONAL** | System | Product doc §§8, 11 | R13 | Confirm demand, RFQ and manufacturing plan before commercial release. |
| A-01 | Four electrically equivalent IM73A135 microphone interface channels | **PROVISIONAL** target IC; **CONFIRMED** equality | A | Product doc §§1.1, 2.1, 3.1 | R2/R4 | Verify exact device/interface; do not preassign acoustic roles. |
| A-02 | TLV320ADC5140 for four-channel acquisition | **PROVISIONAL** | A | Product doc §§1.1, 3.1 | R2 | Verify exact variant, mode, latency and analog/digital limits. |
| A-03 | i.MX RT1062 as production ANC controller | **PROVISIONAL** | A | Product doc §§1.1, 3.1 | R2 | Verify capability, boot, memory/compute and interfaces. |
| A-04 | External QSPI NOR for boot/application; calibration storage as needed | **CONFIRMED** function; MPN/capacity **OPEN** | A | Product doc §3.1, Appendix A | R3 | Choose supported flash/partition strategy after boot decision. |
| A-05 | Clock, reset/boot straps and recovery path | **CONFIRMED** function; implementation **OPEN** | A | Product doc §3.1 | R3/R4 | Verify clock ownership, startup and recoverable boot. |
| A-06 | Independent hardware watchdog can force amplifier safe state | **CONFIRMED** | A | Product doc §§3.1, 6 | R4 | Demonstrate hardware path independent of normal ANC firmware. |
| A-07 | USB service/programming and SWD/JTAG/pogo production access | **CONFIRMED** access requirement; exact routing **OPEN** | A | Product doc §§2.2, 3.1, 7.2 | R3/R4 | Approve factory/recovery workflow and accessible test interface. |
| A-08 | Low-noise analog rails and separate digital regulation/filtering | **CONFIRMED** function; values **OPEN** | A | Product doc §3.1 | R4 | Verify full rail tree, noise/load and sequencing against device limits; [finding 012](../../validation/findings/PV1-R1-012.json). |
| A-09 | Differential mic cable entry, ESD/EMI provisions and exact ADC input network | **OPEN** circuit; provisions **CONFIRMED** | A | Product doc §3.1 and AFE note | R4 | Evidence-backed network and bench check; [finding 001](../../validation/findings/PV1-R1-001.json). |
| A-10 | ADC→RT1062 serial audio and Board A→B audio/control | **PROVISIONAL** formats | A/interface | Product doc §§2.1, 3.1, 5.1 | R3 | Validate end-to-end modes, timing and levels; [finding 013](../../validation/findings/PV1-R1-013.json). |
| A-11 | Quiet AFE placement/continuous returns, test access and an initial six-layer planning target | **CONFIRMED** placement/test intent; layer count **PROVISIONAL** | A | Product doc §3.2 | R7/R12 | Approve stackup/DFM/EMC constraints; four layers only after EVT evidence. |
| B-01 | Protected nominal 12 V input as initial product target | **PROVISIONAL** | B | Product doc §§4.1–4.2 | R4 | Bound electrical envelope; final adequacy stays open. |
| B-02 | Reverse-polarity, OVP, OCP/short and eFuse/electronic-fuse strategy | **CONFIRMED** functions; topology **OPEN** | B | Product doc §§4.1, 6 | R4 | Select/verify protected power path and fault behavior; [finding 012](../../validation/findings/PV1-R1-012.json). |
| B-03 | Efficient 12 V→5 V conversion feeding Board A | **CONFIRMED** product rail class; parts/limits **OPEN** | B/interface | Product doc §§4.1, 5.1 | R3/R4 | Contract source/load/current/returns and verify converter; [finding 012](../../validation/findings/PV1-R1-012.json). |
| B-04 | TAS5825M stereo digital-input Class-D target | **PROVISIONAL** | B | Product doc §§1.1, 4.1 | R2 | Verify exact mode, supplies, audio, load, protection and thermal limits. |
| B-05 | Two BTL speaker outputs; neither negative terminal is ground | **CONFIRMED** | B | Product doc §§2.2, 4.1 | R5 | Preserve BTL marking and connection contract. |
| B-06 | Hardware MUTE/ENABLE defaults to mute on MCU failure | **CONFIRMED** | B/interface | Product doc §§4.1, 6–7 | R4 | Close SYS-08 and verify unpowered/brownout behavior. |
| B-07 | AMP_FAULT/thermal and PGOOD feedback to Board A | **CONFIRMED** function; levels/polarity **OPEN** | B/interface | Product doc §§4.1, 5.1 | R3 | Close shared status contract. |
| B-08 | EMI/output network and bulk-decoupling provisions | **CONFIRMED** provisions; values **OPEN** | B | Product doc §§4.1–4.2 | R5/R12 | Device-backed design, then physical EMI/output validation. |
| B-09 | High-current loops, connector capacity and thermal path handled on Board B | **CONFIRMED** design constraint; limits **OPEN** | B | Product doc §§4.1–4.2, 6 | R7/R12 | Worst-case current/thermal/return analysis, then measurement. |
| B-10 | Initial four-layer planning target, compact switching loops and accessible power/fault test points | **CONFIRMED** layout/test intent; layer count **PROVISIONAL** | B | Product doc §4.2 | R7/R12 | Fabricator stackup, DRC and physical thermal/EMI checks. |
| IF-01/02 | Board B→A 5 V and multiple low-impedance GND/return contacts | **CONFIRMED** classes; counts/tolerance **OPEN** | Interface | Product doc §§5.1, 6 | R3 | Verified current, drop and return-contact allocation. |
| IF-03/05 | BCLK, LRCLK/FSYNC and audio data from A→B | **PROVISIONAL** serial contract | Interface | Product doc §5.1 | R3 | Exact mastership, format, levels, edges and timing. |
| IF-06 | Forwarded MCLK only if required | **OPEN/optional** | Interface | Product doc §5.1 | R3 | R2 endpoint/clock evidence establishes inclusion or omission. |
| IF-07 | I²C SDA/SCL for amplifier control/status | **PROVISIONAL** electrical bus | Interface | Product doc §5.1 | R3 | Voltage, pullups, addressing and unpowered behavior. |
| IF-08/10 | AMP_MUTE, AMP_FAULT and PGOOD cross-board safety/status | **CONFIRMED** classes; electrical behavior **OPEN** | Interface | Product doc §§4.1, 5.1 | R3/R4 | Direction, polarity, fault defaults and sequencing. |
| IF-11 | Revision detect/spare service contacts only if justified | **OPEN/optional** | Interface | Product doc §5.1 | R3 | Document need or omit; no reserved pinout by habit. |
| IF-12 | Keyed mezzanine and initial 10–15 mm stack class; exact connector/outline open | **PROVISIONAL** concept; mechanics **OPEN** | Interface | Product doc §5.2 | R7 | Obtain crib volume/routes and verify part, stack, mounting and contacts. |
| D1 | IM73A135→ADC analog network | **OPEN** | A | Engineering + bench; product doc §12.1 | R4 | See [finding 001](../../validation/findings/PV1-R1-001.json). |
| D2 | Native RT1062 versus Teensy-compatible boot/update | **OPEN** | A | Product owner + R2 engineering; §12.2 | R3 | See [finding 002](../../validation/findings/PV1-R1-002.json). |
| D3 | CE70PR-4 versus SLS-65 final speaker | **OPEN** | B/external | Real-crib A/B; §12.3 | R13 | See [finding 003](../../validation/findings/PV1-R1-003.json). |
| D4 | Final 12 V amplifier headroom | **OPEN**; 12 V starting target **PROVISIONAL** | B | Electrical bound + EVT; §12.4 | R4 bound; R13 final | See [provisional bound](../../validation/findings/PV1-R1-004.json) and [physical proof](../../validation/findings/PV1-R1-005.json). |
| D5 | Board dimensions and connector mechanics | **OPEN** | Interface | Crib maker + engineering; §12.5 | R7 | See [finding 006](../../validation/findings/PV1-R1-006.json). |
| D6 | Microphone roles/placement | **OPEN** | A/external | Acoustic geometry/testing; §12.6 | R13 | See [finding 007](../../validation/findings/PV1-R1-007.json). |
| D7 | Acoustic safety/SPL acceptance criteria | **OPEN** | System | Independent expert/lab; §12.7 | R14 | See [finding 008](../../validation/findings/PV1-R1-008.json). |

The table’s mixed-status rows distinguish a confirmed **function** from an unverified **implementation**; no target IC, frequency, tolerance, connector series or SPL number is approved here. The product document's preliminary cost and board-layer figures are planning targets, not supplier quotations or frozen stackups.

## 2. Seven open decisions — controlled disposition

| Decision | R1 disposition | What the next evidence must establish |
| --- | --- | --- |
| D1 analog network | **REQUIRES R2 ENGINEERING VERIFICATION**, then targeted bench/reference-circuit check by R4; stays OPEN. | Source/output and ADC input topology, differential/single-ended mode, coupling, common mode, bias, gain, clipping/headroom, anti-alias filtering, noise and low-frequency amplitude/phase for the approved ANC band. R1 defines no component values or circuit. |
| D2 boot/programming | **Product decision + R2 engineering verification**; stays OPEN. | Product owner chooses native RT1062 production flow or an explicit Teensy-compatibility requirement by R3, with flash, recovery, factory programming, field service, licensing/dependency and BOM consequences documented. |
| D3 speakers | **REQUIRES BENCH / ACOUSTIC TEST**; stays OPEN. | In the real crib, compare CE70PR-4 and SLS-65 under recorded mounting/microphone geometry and controlled stereo stimuli at **80/100/125/160/250/500/800 Hz**; record impedance versus frequency, attenuation, Vrms/Irms, THD, excursion, thermal/fault observations and repeatability. Selection needs a separately approved acoustic target, not a new number from R1. |
| D4 headroom | **PROVISIONALLY BOUNDED** as a 12 V starting architecture, with final adequacy **REQUIRING BENCH / ACOUSTIC TEST**. | Before R4, establish a worst-case provisional electrical envelope. In EVT-1 with chosen speakers, measure required Vrms and Irms, attenuation, impedance, THD, excursion, simultaneous stereo loading and ANC reserve at minimum supply. If 12 V fails, formally reopen R3/R4 and affected hardware; do not silently adopt 24 V. |
| D5 dimensions/connector | **REQUIRES MECHANICAL INPUT**; stays OPEN. | Crib maker supplies allowable volume, mounting datum, stack height, cable routes, access and retention constraints before R7. Independently, R3 can freeze signal classes, levels, current/return needs and fault defaults without choosing a connector series or pin numbers. |
| D6 mic roles/placement | **REQUIRES BENCH / ACOUSTIC TEST**; stays OPEN. | Keep **four electrically equivalent input channels**. Assign reference/error/monitoring only after real geometry, harness and algorithm tests; record channel map before final validation. |
| D7 safety SPL | **REQUIRES EXTERNAL SAFETY / COMPLIANCE INPUT**; stays OPEN. | Independent acoustic expert/lab supplies written limit, peak/duration and fault/instability test method before sales release (R14). No SPL limit is inferred from the diagram’s preliminary 100–500 Hz label. Safe mute/fault handling must be defined earlier at R4. |

No D1–D7 final decision is **CLOSED NOW**. The product document already closes the two-board architecture, I/O counts and exclusion of v1 wireless; those confirmed requirements do not close the seven listed decisions.

### D2 product-level boot comparison

This is a direction-setting comparison, **not RT1062 pin/boot-circuit verification**. NXP documents a BootROM plus factory flashloader route for external flash programming; PJRC documents a preprogrammed MKL02 bootloader chip for a DIY Teensy 4.x-compatible RT1062 board. [NXP manufacturing guide](https://docs.mcuxpresso.nxp.com/mcuxsdk/latest/html/middleware/mcu_bootloader/docs/iMXRT1060_Manufacturing_User_Guide/topics/introduction.html), [NXP programming flow](https://docs.mcuxpresso.nxp.com/mcuxsdk/latest/html/middleware/mcu_bootloader/docs/iMXRT1060_Manufacturing_User_Guide/topics/program_bootable_image.html), [PJRC bootloader-chip documentation](https://www.pjrc.com/store/ic_mkl02_t4.html).

| Consequence | A. Native production RT1062 flow | B. Preserve Teensy compatibility |
| --- | --- | --- |
| Hardware / flash | Custom RT1062/QSPI design and validated recovery access; flash choice follows NXP boot support. | Additional PJRC bootloader-chip dependency and its supported RT1062/flash combinations; verify exact board compatibility. |
| Bootloader / programming | Project owns image, factory flashing, recovery and any field-update procedure; NXP provides documented ROM/manufacturing path. | Teensy loader behavior is tied to PJRC bootloader ecosystem; verify production fixture and image workflow. |
| Licensing / dependency | Review NXP tools/SDK and project firmware terms; project maintains its own flow. | Obtain written commercial-use/support/licensing terms for the PJRC path and any reused firmware/libraries; R1 makes no legal claim. |
| BOM / maintainability | Avoids a Teensy-specific bootloader IC **if** native flow is approved, but adds project-owned software/test maintenance. | Adds a sourced preprogrammed IC and vendor dependency; may reduce migration work if exact Teensy behavior is a product requirement. |
| Field service | Define authorized USB/pogo recovery and rollback policy; exact implementation remains open. | Define how the PJRC loader fits B2B service, firmware versioning and recovery; compatibility alone does not define the policy. |

**Recommendation, not approval:** prefer **A, a native RT1062 production flow**, because the product document already prefers its own flow and removes PoC-specific hardware; this reduces dependence on Teensy compatibility while retaining a documented NXP manufacturing route. That benefit is an inference from the two primary sources. The product owner must approve this direction before R3; R2 must verify the exact RT1062/flash/boot/recovery implementation and software/licensing implications. If Teensy tool or binary compatibility is a real product requirement, reopen the comparison explicitly.

## 3. Board-to-board requirement contract

The updated [machine-readable interface](../../state/board_to_board_interface.json) carries stable IDs `IF-01`–`IF-11` for 5 V, multiple GND returns, BCLK, LRCLK/FSYNC, A→B audio data, optional MCLK, I²C SDA/SCL, AMP_MUTE, AMP_FAULT, PGOOD and optional revision/service. `SDOUT` is retained only as the product document's alias; the actual endpoint pin naming is unverified. Board B is the intended 5 V source and status source; Board A is the intended audio/mute controller. I²C is shared. These are product-level roles, not verified pin mappings.

Exact connector pin numbers, part/stack, contact allocation, rail tolerances, logic levels, pullups, audio format/mastership, MCLK need, fault polarity, startup/shutdown and unplugged-board behavior remain explicitly open. `required_count` and `voltage_domain` remain `null` in the JSON; multiple return contacts are nonetheless an explicit requirement. The electrical contract can close at R3 before the mechanical connector choice at R7, provided current/contact/return constraints are defined so a later connector can be checked against them. [Finding 009](../../validation/findings/PV1-R1-009.json) blocks R3 until that contract is evidenced.

## 4. Human decision register

| Decision class | Who/what closes it | Examples and boundary |
| --- | --- | --- |
| Engineering-verifiable | R2/R3/R4 manufacturer evidence, calculations and reference circuits; bench where source-only proof is insufficient | D1 electrical compatibility; clock/audio, flash/boot feasibility, cross-board levels and provisional power envelope. |
| Physical-test | Controlled prototype/real-crib measurement | D3 speaker A/B, D4 final headroom, D6 microphone-role/geometry proof, noise/latency and fault response. |
| Product choice | Explicit project-owner approval | D2 native versus Teensy flow; quantitative ANC target and service policy; whether a provisional envelope is acceptable for prototype work. |
| External input | Crib/mechanical partner, independent acoustic expert/lab, relevant compliance assessor | D5 dimensions/harness/connector mechanics; D7 written safety SPL and test method. |

An engineering calculation does not authorize a product choice; a recommended option is not a decision. Physical-test and external-input items cannot be closed by plausible datasheet numbers or AI inference.

## 5. Schematic-entry and release blocker map

The structured [findings](../../validation/findings/) use `blocks_from_phase`. R1 extended the finding schema and gate runner to check the phase being entered and require exact synchronization with `state.open_blockers`; otherwise future blockers would incorrectly fail R1. All 13 current blockers start **after R2**. Their closure criteria are in their JSON records. A later PASS does not remove the duty to run the stated physical test.

| Gate / milestone | Blocking items due there | What remains legitimately open |
| --- | --- | --- |
| **R2 component verification** | None from R1. R2 may begin with the documented targets and open questions. | All seven product decisions; R2 must report unsuitable devices or new blockers if found. |
| **R3 architecture/interface freeze** | [002](../../validation/findings/PV1-R1-002.json) boot choice; [009](../../validation/findings/PV1-R1-009.json) cross-board electrical contract; [010](../../validation/findings/PV1-R1-010.json) measurable ANC target/bounded envelope; [013](../../validation/findings/PV1-R1-013.json) end-to-end audio/clock contract. | Final speaker, 12 V physical proof, board dimensions and SPL sales criteria. |
| **R4 schematic readiness** | [001](../../validation/findings/PV1-R1-001.json) analog network; [004](../../validation/findings/PV1-R1-004.json) provisional power/headroom envelope; [011](../../validation/findings/PV1-R1-011.json) safe-mute response contract; [012](../../validation/findings/PV1-R1-012.json) power/protection/rail contract. | Final crib measurements and connector series if interfaces retain a manufacturable envelope. |
| **R5 schematic implementation** | No new R1 finding if R4 passed; any failed R4 closure blocks R5 too. | Physical A/B and final safety tests. |
| **R7 PCB constraints/stackup; R8–R12 layout/verification** | [006](../../validation/findings/PV1-R1-006.json) mechanical board/connector envelope from R7 onward; earlier unresolved findings remain blocking. | EVT speaker choice and final acoustic claims, with controlled rework risk. |
| **EVT-0 / EVT-1 physical work** | Test plan must measure D1 implementation, boot/recovery, audio latency, safe mute, D3 speaker A/B, D4 headroom and D6 role/geometry. | No acoustic/12 V compliance claim before data; failures reopen affected earlier gates. |
| **R13 DFM/DFA** | [003](../../validation/findings/PV1-R1-003.json) final speaker; [005](../../validation/findings/PV1-R1-005.json) measured 12 V headroom; [007](../../validation/findings/PV1-R1-007.json) mic roles/placement. | Written sales-release SPL criterion still due at R14. |
| **R14 manufacturing/production release** | [008](../../validation/findings/PV1-R1-008.json) independent acoustic safety/SPL criteria and proof; all earlier findings must also be resolved. | None of these open decisions may remain unapproved for release. |

The phase roadmap is not an EVT authorization. If physical evidence invalidates an earlier architecture choice, return to its gate and update dependent contracts rather than recording a convenient waiver.

## 6. R1 disposition and next phase

R1 classifies the product baseline and records 13 future-gate findings with exact closure criteria. There is **no unresolved blocker due before R2** in the current source record. The [R1 validation](../../validation/r1_product_requirements_validation.md) checks JSON/schema integrity, state/findings synchronization, Board A/B and interface scope, phase-scoped gate behavior and unchanged KiCad scope. The R1 engineering review confirmed the statuses and phase dependencies; the runner's human field remains `NOT_EVALUATED` because it never records review approval automatically. R1 does not approve target ICs, boot circuits, speaker performance, electrical values or SPL limits.

**Recommended next phase:** separately authorize R2 component verification. R2 should use official manufacturer evidence to test the target parts and the questions above, report conflicts, and leave physical/product/external decisions open.

PHASE R1: PASS

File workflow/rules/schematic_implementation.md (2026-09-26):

# Schematic implementation

Follow [AGENTS.md](../../AGENTS.md) and the approved Board A/B interface
contract. Start only after the schematic-entry gate. Verify each symbol pin
against official package evidence, name interface nets explicitly, show
power/reset/mute intent, and document intentional no-connects. Run ERC on
both Product V1 projects and retain the reports. ERC PASS does not prove
electrical correctness, interface compatibility or ANC performance.

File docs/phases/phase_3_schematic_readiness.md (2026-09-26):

# Phase 3 - Schematic Readiness and Detailed Electrical Architecture

Date: 2026-09-09 (Europe/Istanbul)

Scope: documentary verification, calculations, component-level electrical architecture, and a contract for a later schematic phase. No KiCad, schematic, PCB placement, routing, firmware, or Phase 4 work was created.

Evidence notation such as `DSP p.53` refers to the source IDs and local manufacturer documents in the [component evidence index](../evidence/component_evidence_index.md). `CONFIRMED` means device evidence or an already approved project decision; `PROVISIONAL` is a bounded Phase 3 engineering decision; `UNKNOWN` and `CONFLICTING` retain their Phase 0 meanings.

**Phase 3B amendment (2026-09-13):** the former TPS386000 rail-supervision and watchdog contract was invalid because its guaranteed rising hysteresis was omitted. [Phase 3B](phase_3b_power_supervisor_correction.md) replaces only that contract; the rail voltages, regulators, Phase 3A `PGOOD_12V`, and all unrelated Phase 3 decisions remain unchanged.

**Phase 3C amendment (2026-09-13):** the former `3V8_PRE -> TPS62135 -> 3V3_SYS` contract did not satisfy the input-headroom condition attached to the converter's accuracy guarantee. [Phase 3C](phase_3c_3v3_regulator_correction.md) retains TPS62135 but powers only the `3V3_SYS` instance from `12V_PROTECTED`, uses a lower-impedance 0.1% divider, and supersedes the 3.3 V realized range and associated margin calculations below. All unrelated Phase 3/3A/3B decisions remain unchanged.

**Phase 3D amendment (2026-09-13):** the remaining buck dividers omitted external-divider and FB-leakage corners, and the LDO ranges omitted divider/FB-current and guaranteed-minimum-load conditions. The [final Sheet 2 audit](phase_3d_final_power_contract_audit.md) supersedes the pre/core dividers and realized ranges, approves a 3.700-3.900 V intermediate pre operating band, supersedes the 1.8 V/DMC dividers and ranges and the 5 V realized range, and adds deterministic LDO preloads. Phase 3A, Phase 3C `3V3_SYS`, and the Phase 3B supervisor thresholds remain unchanged.

**Phase 3E amendment (2026-09-13):** the direct shared `OUT1` fanout could not turn microphone/AFE power off before DSP core/DMC and could not retain the commanded sequence after DSP reset. The [shutdown/safe-state correction](phase_3e_shutdown_safe_state_correction.md) supersedes the affected enable, shutdown, safe-state, and powered-off analog-interface text below. It adds a pre-powered retained downstream-run latch, a guaranteed post-reset delay, an independently qualified microphone/AFE enable, a non-auto-rearming hardware-safe latch, and TMUX2821 powered-off analog isolation. Phase 3D rail sources, dividers, preloads, thresholds, allocations, and voltage/margin calculations remain unchanged.

**Phase 3F amendment (2026-09-13):** the Phase 3E combined post-arm audio/MCLK OE requirement prevented the ADAU1978 PLL from locking before the arm edge. The [clock startup correction](phase_3f_clock_startup_correction.md) supersedes the affected clock-OE, ADC-reset, arming, startup, shutdown, and clock-fault text below. It adds a pre-arm `CLOCK_STARTUP_EN`, separates clock and data buffer banks, and preserves all rail and Phase 3E functional safe-state decisions.

**Phase 3G amendment (2026-09-14):** Phase 4C proved that the four differential microphones require eight, not four, independently isolated legs and that the former OPA165x 0.8 V headroom claim was not guaranteed at the actual 5 V operating point. The [remaining-sheet preflight](phase_3g_remaining_schematic_preflight.md) supersedes the microphone-isolation device/count, VREF-buffer, signal-amplifier, gain/headroom/noise, Sheet 3 ownership, and Sheets 3-7 implementation-inventory text below. Unrelated Phase 3 through Phase 3F decisions remain unchanged.

## 1. Executive summary

The four Phase 2 hard schematic-entry blockers have been resolved or bounded without weakening them. The resulting prototype design point is:

- four nominal 4-ohm BTL speakers, 6 W continuous per channel with all four channels active, and 7.03 W sine-equivalent full-scale/short-peak power per channel;
- a regulated 12 V nominal input, 10.8 V to 13.2 V normal operating range, 4 A continuous and 5 A short-peak source capability;
- input cutoff, reverse-polarity, overcurrent, inrush, brownout, and hardware-safe mute behavior based on TPS26630;
- a deterministic `3V8_PRE` intermediate rail and sequenced 1.0 V, 1.35 V, 1.8 V, 2.8 V, 3.3 V, and 5.0 V rails;
- ADSP-21569 `VDD_REF/VDD_ANA` before `VDD_EXT`, all five DSP domains monitored, all DSP rails and the 24.576 MHz clock valid before reset release, and explicit power-down behavior;
- one 24.576 MHz, 1.8 V oscillator, a 1:3 low-skew clock fanout, and two 1.8-to-3.3 V MCLK translators;
- separate buffered 3.3 V serial-audio paths instead of the Phase 2 conditional direct-drive assumption;
- a two-op-amp-per-microphone AC-coupled differential AFE using OPA4192, gain 1.453571 V/V, a worst-case coupling corner below 0.73 Hz, and ADC HPFs plus amplifier HPF disabled;
- SPI2 boot from a selected 64 MB serial flash, fixed boot straps, JTAG, logic-level UART, and a hardware-dominant safe-state path.

The architecture deliberately does not claim automotive transient compliance, final acoustic performance, final thermal compliance, EMC compliance, or a completed ANC compute budget. Those remain product/validation work. They do not require a different basic schematic architecture under the bounded prototype assumptions below.

## 2. Phase 2 blocker resolution

### 2.1 Exact blockers extracted before new work

The following are faithful summaries of the four items in Phase 2 section 13; none has been downgraded:

| # | Phase 2 hard blocker | Why it blocked schematic entry | Needed evidence or decision | Origin | Phase 3 disposition |
| --- | --- | --- | --- | --- | --- |
| 1 | **AFE contract closure:** approve the ANC passband/phase mask, microphone SPL/crest envelope, ADC utilization/clipping margin, noise target, gain range, coupling/DC policy, powered-off behavior, and exact AFE part/rails. | Gain, topology, coupling capacitors, op amp, rail, and protection could not be selected safely without a bounded signal and low-frequency envelope. | Product-level signal/passband bounds plus device-backed AFE calculations and component selection. | Mixed product- and device-derived. | **ACCEPTED PROVISIONALLY.** A safe prototype passband/SPL/noise contract and a deterministic circuit architecture are frozen in section 9. |
| 2 | **Clock implementation closure:** select the exact 24.576 MHz oscillator/fanout, mixed-voltage outputs, jitter/accuracy/startup/loading/skew/duty/edge budget, SPORT/SRU route, and loaded-PVT timing; close the ADC minimum data-hold evidence gap by clarification or a formally approved verification method. | Clock pins, rails, output enables, SPORT pins, timing polarity, and series elements were otherwise undefined; an unsafe sampling edge could corrupt all channels. | Exact clock parts and domains, arithmetic, pin route, timing budget, and a controlled validation method for the missing ADC minimum hold number. | Device/implementation-derived. | **RESOLVED for schematic entry.** Exact parts, routes, margins, loading limits, and the mandatory PVT/bench method are in sections 7 and 15. |
| 3 | **Power and sequencing closure:** define the nominal-12-V envelope, worst-case rail loads/margins, no-DDR `VDD_DMC`, supervisor thresholds, discharge behavior, and a power-up/down/back-drive matrix satisfying DSP delta limits. | Regulators, enable topology, protection ratings, bulk capacitance, reset, and even whether every DSP supply pin was powered were not deterministic. | Product input/output decisions and manufacturer-backed regulator/supervisor architecture with explicit state sequencing. | Mixed product- and device-derived. | **ACCEPTED PROVISIONALLY.** The product envelope is bounded and the hardware architecture is deterministic; rail-ramp measurements remain a mandatory validation, not an architectural choice. See sections 4-6 and 10. |
| 4 | **Conditional direct-I/O closure:** prove every Phase 2 bounded-rail condition or select qualified buffers/translators with safe output-enable behavior. | The direct DSP high-level margin was too small to approve over PVT and unpowered-device states could back-drive endpoints. | Worst-case DC margins or concrete translators/buffers and safe OE control. | Device-derived. | **RESOLVED.** Strategy B is selected: SN74LVC244A buffering for audio, SN74AXC2T245 for MCLK translation, and a common 3.3 V control domain. See section 8. |

### 2.2 Gate interpretation

`ACCEPTED PROVISIONALLY` is used only for product choices whose bounds are safe for the prototype and whose later adjustment changes passive values, gain settings, connector series, or thermal hardware rather than the basic signal/power architecture. Device absolute limits, DSP supply sequencing, amplifier BTL handling, and powered-off I/O isolation are not provisionally waived.

## 3. Speaker/output design point

### 3.1 Frozen prototype requirement

| Item | Phase 3 value | Classification |
| --- | --- | --- |
| Channel count | Four independent BTL channels; all four may operate simultaneously | **CONFIRMED** architecture |
| Speaker nominal impedance | 4 ohms | **PROVISIONAL** product decision |
| Speaker minimum impedance | Target at least 3.2 ohms throughout the driven band; the amplifier's 2-ohm device capability is not the product load target | **PROVISIONAL** |
| Continuous output target | 6 W/channel, four channels simultaneous, sine-equivalent electrical test | **PROVISIONAL** |
| Short peak target | 7.03 W/channel, four channels, less than 1 s; limited by selected gain rather than the datasheet headline maximum | **PROVISIONAL** |
| Amplifier supply in normal operation | 10.4-13.2 V at `12V_PROTECTED`; the input path is allocated at most 0.4 V drop at 4 A from the 10.8 V connector minimum | **PROVISIONAL** |
| Amplifier gain | TAS6424E-Q1 gain level 1, register 0x01 `GAIN=00`, 7.5 V peak at 0 dBFS | **PROVISIONAL**, device-defined setting |
| Clipping policy | Firmware limiter must keep normal program/ANC output at or below 6 W/channel; clipping is not a normal operating mode | **PROVISIONAL** |
| Low-frequency policy | Digital HPF bypassed (`0x01[7]=1`); 2.2 uF bootstrap capacitors fitted; final acoustic excursion limit remains speaker-specific | **PROVISIONAL** |

The exact production speaker remains `UNKNOWN`. A Phase 4 schematic may use this load contract without knowing its mechanical model. Before a speaker is connected, its datasheet must confirm nominal 4 ohms, the minimum-impedance target, at least 10 W thermal rating, excursion suitability for the intended low-frequency content, and BTL isolation from chassis/ground.

### 3.2 Power, voltage, and current calculations

The chosen amplifier setting limits a full-scale sine to 7.5 V peak. For a 4-ohm resistive load:

`PFS = Vpk^2 / (2R) = 7.5^2 / (2 x 4) = 7.03125 W/channel`.

At the 6 W continuous target:

- `Vrms = sqrt(PR) = 4.899 V`, `Vpk = 6.928 V`;
- `Irms = sqrt(P/R) = 1.225 A`, `Ipk = 1.732 A` per channel;
- four-channel acoustic-output-stage electrical power is 24 W.

At the selected full-scale short peak:

- `Vrms = 5.303 V`, `I rms = 1.326 A`, `Ipk = 1.875 A` per channel;
- simultaneous four-channel output is 28.125 W.

The ideal single-supply BTL ceiling at 12 V and 4 ohms is `12^2/(2x4)=18 W/channel`, but output-stage losses and distortion make that an upper geometric ceiling, not a target. At the 10.4 V minimum protected amplifier rail, 7.5 V peak retains 2.9 V of ideal rail headroom. TI only guarantees the published 4-ohm power points at 14.4 V and 25 V; those headline values are not transposed to this 12 V product [AMPE pp.8-10, 63-69].
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

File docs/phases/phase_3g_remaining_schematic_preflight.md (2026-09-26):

# PHASE 3G — Remaining schematic preflight

Date: 2026-09-14

Scope: documentary correction of the microphone/AFE/isolation contract and a focused implementation-readiness audit of Sheets 3 through 7. No KiCad file was created or modified. Phase 4C was not resumed.
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

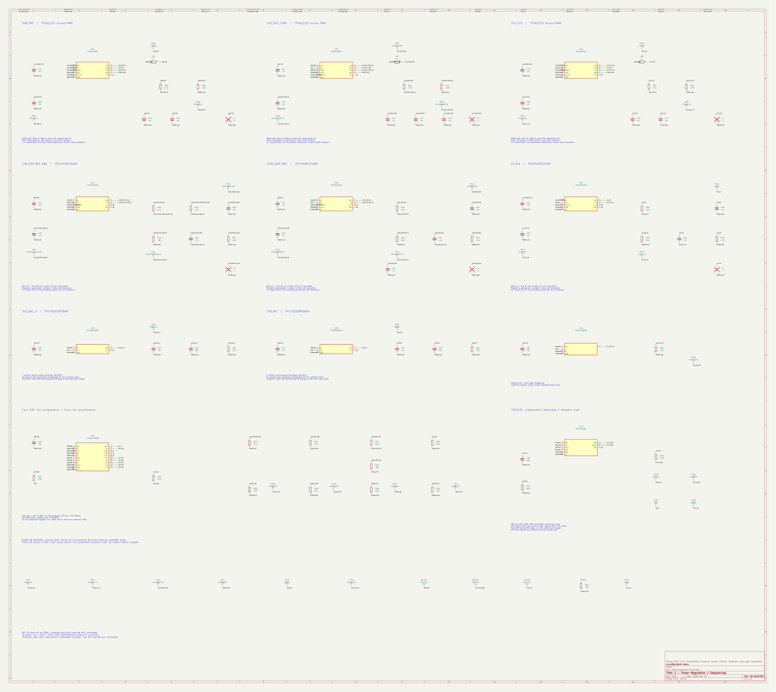
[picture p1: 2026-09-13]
validation/phase_4b/sheet2_overview.png

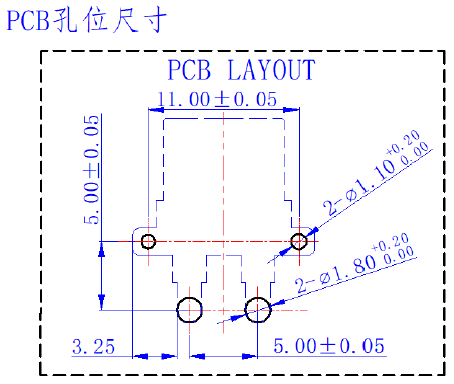
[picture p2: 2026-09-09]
datasheets/power/amass_xt30pw_spec_1.png

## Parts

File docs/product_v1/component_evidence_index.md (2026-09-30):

# Product V1 component evidence index — R2

Verified 2026-09-28. PDF page references in the R2 report use the printed page number, which matches the PDF page for the TI and Infineon datasheets. NXP web PDF references use the printed page where stated. The legacy ADAU1978, ADSP-21569 and TAS6424E-Q1 files are excluded.

| ID | Manufacturer, controlled document | Revision/date | Repository copy or official URL | Use |
| --- | --- | --- | --- | --- |
| E-MIC | Infineon, IM73A135V01 datasheet | V1.20, 2021-07-07 | [local PDF](../../datasheets/microphone/im73a135_datasheet_v1_20.pdf), [official PDF](https://www.infineon.com/assets/row/public/documents/24/49/infineon-im73a135-datasheet-en.pdf) | Acoustic/electrical limits, package and PCB port. |
| E-ADC | TI, TLV320ADC5140, SBAS892A | Rev A, 2019-10 | [local PDF](../../datasheets/product_v1/tlv320adc5140_sbas892a.pdf), [official PDF](https://www.ti.com/lit/ds/symlink/tlv320adc5140.pdf) | Analog inputs, ASI, timing, power, reset, package. |
| E-ADC-RATE | TI, TLV320ADCx140/PCMx140-Q1 sampling rates and processing blocks, SBAA381B | Rev B, 2024-05 | [local PDF](../../datasheets/product_v1/tlv320adcx140_sample_rate_sbaa381b.pdf), [official PDF](https://www.ti.com/lit/an/sbaa381b/sbaa381b.pdf) | Four analog channels at 96 kHz, DRE/AGC restrictions. |
| E-MCU | NXP, i.MX RT1060 consumer datasheet, IMXRT1060CEC | Rev 4, 2024-04 | [local PDF](../../datasheets/product_v1/nxp_imxrt1060cec_rev4.pdf), [official PDF](https://cache.nxp.com/docs/en/nxp/data-sheets/IMXRT1060CEC.pdf) | RT1062 ordering, supplies, SAI electrical timing, pin/power restrictions. The NXP cache endpoint supplied the repository copy during R4. |
| E-MCU-I | NXP, i.MX RT1060 industrial datasheet, IMXRT1060IEC | Rev 4, 2024-04 | [official PDF](https://www.nxp.com/docs/en/nxp/data-sheets/IMXRT1060IEC.pdf) | Industrial variant candidate and package/pin comparison for R3. |
| E-MCU-ERR-A | NXP, i.MX RT1060_A chip errata, IMXRT1060CE_A | Rev 1.3, 2021-12 | [official PDF](https://www.nxp.com/docs/en/errata/IMXRT1060CE_A.pdf) | Silicon A constraints. |
| E-MCU-ERR-B | NXP, i.MX RT1060_B chip errata, IMXRT1060CE_B | Rev 1.1, 2021-12 | [official PDF](https://www.nxp.com/docs/en/errata/IMXRT1060CE_B.pdf) | Silicon B constraints. |
| E-MCU-MFG | NXP, i.MX RT1060 Manufacturing User Guide | Online MCUXpresso SDK, accessed 2026-09-28 | [guide](https://docs.mcuxpresso.nxp.com/mcuxsdk/latest/html/middleware/mcu_bootloader/docs/iMXRT1060_Manufacturing_User_Guide/index.html) | ROM downloader, flashloader, boot image and FlexSPI NOR factory flow. |
| E-MCU-SAI | NXP, Using Multi-Channel Feature of SAI, AN12090 | Rev 0, 2017-11 | [official PDF](https://www.nxp.com/docs/en/application-note/AN12090.pdf) | SAI multichannel implementation method; exact Product V1 mux remains open. |
| E-MCU-SDK | NXP, SAI eDMA multi-channel transfer example | Online SDK, accessed 2026-09-28 | [example](https://mcuxpresso.nxp.com/mcuxsdk/latest/html/examples/driver_examples/sai/edma_multi_channel_transfer/readme.html) | Evidence of SAI/eDMA path on RT1060 EVKB; not a measured ANC workload. |
| E-MCU-HW | NXP, MIMXRT1050/MIMXRT1060 Hardware Design Guide, MIMXRT105060HDUG | Rev 7.0, 2025-09 | [NXP document listing](https://www.nxp.com/products/i.MX-RT1060) | Required R4 checklist for power, clock, reset, BGA, FlexSPI layout; full PDF access pending. |
| E-AMP | TI, TAS5825M, SLASEH7H | Rev H, 2023-01 | [local PDF](../../datasheets/product_v1/tas5825m_slaseh7h.pdf), [official PDF](https://www.ti.com/lit/ds/symlink/tas5825m.pdf) | Supplies, I2S/TDM, BTL, protection, startup and thermal. |
| E-PJRC | PJRC, Bootloader Chip for DIY Teensy 4.0 & 4.1 Projects | Web page, accessed 2026-09-28 | [primary vendor page](https://www.pjrc.com/store/ic_mkl02_t4.html) | Third-party Teensy-compatible hardware dependency and flash combinations; not NXP evidence. |
| E-EVK | NXP, MIMXRT1060-EVK schematic, A2 | NXP-hosted design file | [official hosted schematic](https://community.nxp.com/pwmxy87654/attachments/pwmxy87654/imxrt/1874/1/i-MX%20RT1060%20EVK%20Schematic.pdf) | IS25WP064AJBLE 64-Mbit example candidate, not Product V1 approval. |
| E-FLASH | ISSI, IS25WP064A/032A serial flash datasheet | Rev 00D, 2016-03 | [manufacturer PDF](https://www.issi.com/WW/pdf/IS25WP064A_032A.pdf) | EVK flash family has 1.65–1.95-V VCC; R3 must match MCU SD-bank voltage. |
| E-FLASH-3V | ISSI, IS25LP064A serial flash datasheet | Manufacturer PDF | [manufacturer PDF](https://www.issi.com/WW/pdf/25LP064A.pdf) | 3-V family example only; RT1062 ROM boot support not established for exact MPN. |
| E-MCU-R4 | NXP, i.MX RT1060 consumer datasheet, IMXRT1060CEC | Rev 4, 2024-04 | [local PDF](../../datasheets/product_v1/nxp_imxrt1060cec_rev4.pdf), [NXP source](https://cache.nxp.com/docs/en/nxp/data-sheets/IMXRT1060CEC.pdf) | R4 ball map, boot-strap pads, rail bounds and SAI electrical limits. |
| E-MCU-HW-OLD | NXP, MIMXRT1050/MIMXRT1060 Hardware Design Guide | Rev 3, 2019 | [local PDF](../../datasheets/product_v1/nxp_mimxrt105060hdug_rev3_2019.pdf), [NXP community source](https://community.nxp.com/pwmxy87654/attachments/pwmxy87654/imxrt/3999/1/MIMXRT105060HDUG.pdf) | Historical manufacturer decoupling and DCDC guidance; superseded by listed Rev 7 and insufficient alone for R4 freeze. |
| E-MCU-MUX | NXP MCUXpresso device header, `fsl_iomuxc.h` | [commit 5aca9ad](https://github.com/nxp-mcuxpresso/mcux-devices-rt/blob/5aca9adfa3dd9be25fb31144dc52a5a845fd95aa/RT1060/MIMXRT1062/drivers/fsl_iomuxc.h) | [manufacturer source](https://github.com/nxp-mcuxpresso/mcux-devices-rt/blob/5aca9adfa3dd9be25fb31144dc52a5a845fd95aa/RT1060/MIMXRT1062/drivers/fsl_iomuxc.h) | Candidate SAI, I2C, UART and FlexSPI muxes. Pin defaults/ROM use still require current RM. |
| E-MCU-LIFE | NXP RT1060 orderable-product listing and package information | Accessed 2026-09-28 | [official product page](https://www.nxp.com/products/i.MX-RT1060?tab=Package_Quality_Tab), [SOT1968-1 package](https://www.nxp.com/packages/SOT1968-1) | DVJ6A NRND versus DVJ6B Active, 12-mm 196-ball choice. |
| E-OPA | TI, OPA320/OPA2320 datasheet SBOS513F | Rev F | [local PDF](../../datasheets/afe/opa320_datasheet.pdf), [official PDF](https://www.ti.com/lit/ds/symlink/opa320.pdf) | Unity-buffer feasibility candidate only; exact AFE circuit not approved. |

Manufacturer product pages used for lifecycle: [Infineon IM73A135](https://www.infineon.com/part/IM73A135), [TI TLV320ADC5140](https://www.ti.com/product/TLV320ADC5140), [NXP RT1060](https://www.nxp.com/products/i.MX-RT1060), [TI TAS5825M](https://www.ti.com/product/TAS5825M). Manufacturer sites did not expose standalone TI/Infineon silicon errata in the documents reviewed; that absence is not proof that no advisory exists. Recheck at exact MPN release.
 
## R4 closure-pass manufacturer evidence (2026-09-28)

These newly retained PDFs support conditional calculations and candidate screening only. Their presence does not close a schematic finding.

| ID | Manufacturer document | Revision/date | Repository copy and official source | Applied limit |
| --- | --- | --- | --- | --- |
| E-LVC-ISO | TI SN74LVC1G125, SCES223U | Rev U, 2026-08 | [local PDF](../../datasheets/product_v1/sn74lvc1g125_datasheet.pdf), [TI PDF](https://www.ti.com/lit/ds/symlink/sn74lvc1g125.pdf) | pp.4-7 input levels, output VOH/VOL at stated load, Ioff, 125-C propagation for conditional Board B audio isolation. |
| E-I2C-ISO | TI TCA9800, SCPS264B | Rev B, 2020-02 | [local PDF](../../datasheets/product_v1/tca9800_datasheet.pdf), [TI PDF](https://www.ti.com/lit/ds/symlink/tca9800.pdf) | pp.4-7 100-kHz limit, B-side current source, powered-off candidate; not a frozen interface. |
| E-BUCK-B | TI TPS54334, SLUSC26A | Rev A, 2016-02 | [local PDF](../../datasheets/product_v1/tps54334_datasheet.pdf), [TI PDF](https://www.ti.com/lit/ds/symlink/tps54334.pdf) | pp.4-6 4.2-28-V operation and 0.788-0.812-V reference across stated full temperature/VIN. |
| E-BUCK-EXCLUDED | TI TPS54302, SLVSDG6C | Rev C, 2026-03 | [local PDF](../../datasheets/product_v1/tps54302_datasheet.pdf), [TI PDF](https://www.ti.com/lit/ds/symlink/tps54302.pdf) | The cited feedback reference accuracy is specified at VIN=12 V; it was not reused as a guarantee over an unbounded input range. |
| E-QSPI-AN | NXP AN12108, How to Enable Boot from QSPI Flash | Rev 4, 2019 | [local PDF](../../datasheets/product_v1/nxp_an12108_flexspi_boot.pdf), [NXP PDF](https://www.nxp.com/docs/en/application-note/AN12108.pdf) | RT1050/EVK example only; cannot establish Product V1 RT1062 boot straps or FCB. |
| E-LDO-A | TI TPS7A20, SBVS338H | Rev H, 2024-07 | [local PDF](../../datasheets/power/tps7a20_datasheet_rev_h.pdf), [TI PDF](https://www.ti.com/lit/ds/symlink/tps7a20.pdf) | p.6 DQN fixed 2.8-V tolerance only at VIN >=3.1 V, IOUT 1-300 mA, specified CIN/COUT and junction temperature. |
| E-BUCK-A | TI TPS62135, SLVSBH3B | Rev B, 2017-04 | [local PDF](../../datasheets/power/tps62135_datasheet_rev_b.pdf), [TI PDF](https://www.ti.com/lit/ds/symlink/tps62135.pdf) | pp.4-7 candidate 5-V to 3.3-V buck constraints; no Product V1 rail approval. |
| E-EFUSE-B | TI TPS2663, SLVSE94G | Rev G | [local PDF](../../datasheets/power/tps2663_datasheet_rev_g.pdf), [TI PDF](https://www.ti.com/lit/ds/symlink/tps2663.pdf) | Board B eFuse/reverse FET candidate; trip/thermal circuit not frozen. |
| E-WATCHDOG | TI TPS3431, SNVSB66A | Rev A, 2021-10 | [local PDF](../../datasheets/power/tps3431_datasheet_rev_a.pdf), [TI PDF](https://www.ti.com/lit/ds/symlink/tps3431.pdf) | pp.3-7 independent watchdog candidate; timeout and gate unresolved. |
| E-SUPERVISOR | TI TPS3760, SBVS420A | Rev A, 2023-09 | [local PDF](../../datasheets/power/tps3760_datasheet_rev_a.pdf), [TI PDF](https://www.ti.com/lit/ds/symlink/tps3760.pdf) | pp.3-9 supervisor candidate; no threshold/hysteresis circuit approved. |

Current NXP [RT1060 documentation listing](https://www.nxp.com/products/i.MX-RT1060) marks `IMXRT1060RM` Rev 4 (2026-01-15) and `MIMXRT105060HDUG` Rev 7 (2025-09-25) **Account Required**. The exact current System Boot/Fuse Map/FlexSPI/CCM/SAI/eDMA/IOMUXC and hardware-guide power/reset/clock/decoupling sections needed for R4 were not available; older public revisions are not substitutes.

## Authorized NXP documents added for R4 owner closure (2026-09-30)

The preceding access note is historical. The project owner has now supplied authorized repository copies. The findings below supersede the earlier `MISSING_AUTHORITATIVE_EVIDENCE` designation for these two documents.

| ID | Manufacturer document | Revision/date | Repository copy | Applied sections |
| --- | --- | --- | --- | --- |
| E-MCU-RM4 | NXP, i.MX RT1060 Processor Reference Manual, `IMXRT1060RM` | Rev. 4, 01/2026 | [authorized PDF](../evidence/nxp/IMXRT1060RM.pdf) | System Boot pp.193–214; Fuse Map pp.1287–1288; Audio PLL/CCM pp.1028, 1052, 1056–1058; SAI pp.1977–2020. Physical PDF page numbers; confirm printed chapter pagination when transferring values. |
| E-MCU-HW7 | NXP, MIMXRT1050/MIMXRT1060 Hardware Design Guide, `MIMXRT105060HDUG` | Rev. 7.0, 2025-09-25 | [authorized PDF](../evidence/nxp/MIMXRT105060HDUG.pdf) | Power and decoupling pp.2–6; reference clock/debug/ROM downloader/boot pp.7–11; FlexSPI boot/layout pp.14–19. |
| E-WATCHDOG-FAST-SCREEN | Analog Devices, ADM6316/17/18/20/21 watchdog and supervisor family | Rev. I, 2018-03 | [manufacturer PDF](https://www.analog.com/media/en/technical-documentation/data-sheets/ADM6316_6317_6318_6319_6320_6321_6322.pdf) | p.3 Table 2: fastest W option has 4.3–9.3-ms timeout over specified range; candidate screening only, not a selected safety circuit. |

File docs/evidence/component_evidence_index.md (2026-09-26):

# Component evidence index - Phase 1 through Phase 3G

Review: 2026-09-06 to 2026-09-14 (Europe/Istanbul). Electrical findings and their conditions are in the [Phase 1 report](../phases/phase_1_component_datasheet_verification.md), [Phase 1B report](../phases/phase_1b_blocker_resolution.md), [Phase 1C report](../phases/phase_1c_amplifier_substitution.md), [Phase 3 report](../phases/phase_3_schematic_readiness.md), [Phase 3B correction](../phases/phase_3b_power_supervisor_correction.md), [Phase 3C correction](../phases/phase_3c_3v3_regulator_correction.md), [Phase 3D final power audit](../phases/phase_3d_final_power_contract_audit.md), [Phase 3E shutdown/safe-state correction](../phases/phase_3e_shutdown_safe_state_correction.md), [Phase 3F clock/startup correction](../phases/phase_3f_clock_startup_correction.md), and [Phase 3G implementation preflight](../phases/phase_3g_remaining_schematic_preflight.md). IDs below are the reports' source keys. Page numbers are printed pages unless explicitly marked physical PDF pages.

Sixteen Phase 1 authoritative PDFs are recorded in the [source manifest](../../validation/phase_1/source_manifest.json), including official requested/final URLs, acquisition UTC timestamps, byte counts, page counts, SHA-256 hashes, document identity excerpts and review scope. Phase 1C adds the two official TI PDFs identified below. No unofficial mirrors were used. Manufacturer evaluation schematics remain external references, not production hardware.

| ID | Local authoritative copy / official source | Revision/date in document | Inspected region / boundary |
| --- | --- | --- | --- |
| AMPE | [TAS6424E-Q1 datasheet, SLOSE73A](../../datasheets/amplifier/tas6424e-q1_datasheet_rev_a.pdf) · [Manufacturer PDF](https://www.ti.com/lit/ds/symlink/tas6424e-q1.pdf) | Rev.A; November 2021; current download includes later package addenda/notice | pp.1-11: identity, package, pins, limits, power and serial timing; pp.22-25: formats/TDM/clocks; pp.42-43 and 58-59: required configuration fields; pp.63-69: application, power and thermal constraints. SHA-256 `02BEC5D057629B765D616D68F65201957719744464FEE7BA033657C538C3AEDB`. |
| AMPEEVAL | [SLOU553: TAS6424E-Q1 Evaluation Module](../../references/tas6424e-q1/tas6424e-q1_evm_user_guide.pdf) · [Manufacturer PDF](https://www.ti.com/lit/ug/slou553/slou553.pdf) | May 2021 | pp.1-11: identity, block diagram and 14.4-V evaluation setup; pp.22-25: exact-device schematics; pp.30-31: BOM including TAS6424EQDKQRQ1 and 12.288-MHz oscillator. Implementation reference only. SHA-256 `8E9012973C970E5AD7BC0AD607D510B69979F249BFD3CF8DEA26EA0FA0C04535`. |
| MIC | [IM73A135V01 datasheet](../../datasheets/microphone/im73a135_datasheet_v1_20.pdf) · [Manufacturer PDF](https://www.infineon.com/assets/row/public/documents/24/49/infineon-im73a135-datasheet-en.pdf) | V1.20; 2021-07-07 | pp.1-15: identity, acoustic/electrical tables, load network, pin/package and handling; revision history. |
| ADC | [ADAU1978 datasheet](../../datasheets/adc/adau1978_datasheet_rev_b.pdf) · [Manufacturer PDF](https://www.analog.com/media/en/technical-documentation/data-sheets/ADAU1978.pdf) | Rev.B; August 2024 | pp.1-9: electrical/timing/pins; pp.12-23: reset, PLL, analog, filtering and serial interfaces; pp.26-42: relevant register fields; p.43 Fig.44; p.44 package/orderables. |
| DSP | [ADSP-21562/3/5/6/7/9 datasheet](../../datasheets/dsp/adsp-2156x_datasheet_rev_d.pdf) · [Manufacturer PDF](https://www.analog.com/media/en/technical-documentation/data-sheets/adsp-21562-21563-21565-21566-21567-21569.pdf) | Rev.D; June 2023 | pp.1-25: architecture, clocks, peripherals and boot; pp.26-43: signals; pp.44-58: rails, power, sequencing and SPORT timing; p.87 loading; pp.89-94: both 400-ball lists; pp.99-102: package/orderables. |
| AMP | [TAS6424-Q1 datasheet, SLOS870B](../../datasheets/amplifier/tas6424-q1_datasheet_rev_b.pdf) · [Manufacturer PDF](https://www.ti.com/lit/ds/symlink/tas6424-q1.pdf) | Rev.B; October 2017; newer ordering addenda in current download | pp.1-10: identity, pins, limits, currents and timing; pp.18-26: formats/clocks/operating modes; pp.27-49: relevant control fields; pp.50-57: application, filters, power, thermal and layout; package addenda. |
| ANOM | [ADSP-2156x Silicon Anomaly List, NR004735J](../../datasheets/dsp/adsp-2156x_anomalies.pdf) · [Manufacturer PDF](https://www.analog.com/media/en/dsp-documentation/integrated-circuit-anomalies/adsp-21562-21563-21565-21566-21567-21569-anomalies.pdf) | Rev.J; 2026-01-29 | All 21 anomalies, pp.2-12; applicability to silicon 0.0/0.2, workarounds and revised DMC calibration. |
| POWER | [EE-470: ADSP-2156x Power Sequencing Requirements](../../datasheets/dsp/ee-470.pdf) · [Manufacturer PDF](https://www.analog.com/media/en/technical-documentation/application-notes/ee-470.pdf) | Rev.1; 2025-02-17 | pp.1-14: rail differential restrictions, sequencing, ramp I/O behavior and example mitigation. No example power circuit adopted. |
| BOOT | [EE-447: ADSP-2156x Processor Boot ROM](../../datasheets/dsp/ee447v01.pdf) · [Manufacturer PDF](https://www.analog.com/media/en/technical-documentation/application-notes/ee447v01.pdf) | V01; 2023-05-11 | Boot modes/streams, init code, boot customization and recovery implications; cross-checked against current silicon anomalies. No boot image implemented. |
| DSPPOWER | [EE-414: Estimating Power for ADSP-2156x Processors](../../datasheets/dsp/ee414.pdf) · [Manufacturer PDF](https://www.analog.com/media/en/technical-documentation/application-notes/ee414.pdf) | Rev.2; 2021-03-15 | Core static/dynamic, activity factor, clock/DMA/accelerator and peripheral power models; especially pp.3-9. No selected full-system workload. |
| SOM | [EV-21569-SOM Evaluation Board Manual](../../datasheets/dsp/ev-21569-som-manual.pdf) · [Manufacturer PDF](https://www.analog.com/media/en/evaluation-boards-kits/evaluation-board/ev-21569-som-manual.pdf) | Rev.1.0; September 2020; 82-EV-21569-SOM-01 | Functional blocks, power, boot/flash, clocks, reset, UART/JTAG and connectors; development example only. |
| SOMSCH | [EV-21569-SOM schematic](../../references/ev-21569-som/ev-21569-som-schematic.pdf) · [Manufacturer PDF](https://www.analog.com/media/en/technical-documentation/eval-board-schematic/ev-21569-som-schematic.pdf) | Rev.A; title sheet 2020-01-29 | Sheets 2-6: DSP/RAM/rails/decoupling; 7: clocks/boot; 8: SPI2 flash; 9: UART/JTAG; 10: reset; 11: power sequence. Targeted visual review of sheets 7,9,11. |
| ADCEVAL | [UG-600: Evaluating ADAU1977/ADAU1978/ADAU1979](../../datasheets/adc/ug-600.pdf) · [Manufacturer PDF](https://www.analog.com/media/en/technical-documentation/user-guides/EVAL-ADAU1977_1978_1979_UG-600.pdf) | Rev.0; August 2014 | pp.3-7: supply, jumpers and variant-specific analog coupling; pp.10-15: schematics (drawings identify ADAU1977). Do not transfer ADAU1977 boost/bias or 10 Vrms capabilities. |
| AMPEVAL | [SLOU453A: TAS6424-Q1 Evaluation Module](../../datasheets/amplifier/slou453a.pdf) · [Manufacturer PDF](https://www.ti.com/lit/ug/slou453a/slou453a.pdf) | Rev.A; October 2017 | pp.1-3: operation/block diagram; pp.20-26: board layouts, schematics (22-23) and BOM. Exact TAS6424-Q1, not TAS6424L-Q1. |
| INDUCTOR | [SLOA242A: Inductor Selection Guide for 2.1-MHz Class-D Amplifiers](../../datasheets/amplifier/sloa242a.pdf) · [Manufacturer PDF](https://www.ti.com/lit/pdf/SLOA242) | Rev.A; September 2019 | pp.1-8: saturation/current/inductance, losses and thermal selection considerations. No part/filter selected. |
| HRM | [ADSP-2156x SHARC+ Processor Hardware Reference](../../datasheets/dsp/adsp-2156x_hwr.pdf) · [Manufacturer PDF](https://www.analog.com/media/en/dsp-documentation/processor-manuals/adsp-2156x_hwr.pdf) | Rev.1.1; October 2022; 82-100137-01 | Targeted chapters: clock/reset, SRU/DAI, SPORT Ch.23 (especially 23-33 to 23-35; PDF1122-1124), PCG Ch.24 (24-1 to 24-9; PDF1189-1197), DMA Ch.27 (especially 27-1 to 27-4; PDF1296-1299) and boot Ch.40. Not a cover-to-cover review of 2453 pages. |
| JTAG | [EE-68: Analog Devices JTAG Emulation Technical Reference](../../datasheets/dsp/ee-68.pdf) · [Manufacturer PDF](https://www.analog.com/media/en/technical-documentation/application-notes/ee-68.pdf) | Rev.10; 2008-04-15 | p.6 target TRST pulldown and routing practice. The exact Phase 3 10-pin mapping comes from the same-device SOM schematic (SOMSCH sheet 9), not from EE-68's older 14-pin example. |
| REF733 | [TIDA-00733: TIDUCZ2 design guide](../../references/tas6424-q1/tida-00733_design_guide.pdf) · [Manufacturer PDF](https://www.ti.com/lit/ug/tiducz2/tiducz2.pdf) | December 2017 | Targeted architecture and clock/audio implementation, sections 2.3.3-2.3.4, pp.18-23; power, thermal/EMI and test context. 96 kHz TDM8 reference, not this project circuit. |

| PWRIN | [TPS2663x datasheet, SLVSE94G](../../datasheets/power/tps2663_datasheet_rev_g.pdf) · [Manufacturer PDF](https://www.ti.com/lit/ds/symlink/tps2663.pdf) | Rev.G; June 2024 | pp.1-9 and 15-34: 4.5-60 V operation, 6 A/current-limit accuracy, UVLO/OVP, inrush, reverse-input FET, PGOOD and application equations. SHA-256 `BB61314ACE65ED37684BD07F541FC676081D7CF81CB24020E7C5C2065BFE16B2`. |
| BUCK | [TPS62135 datasheet, SLVSBH3B](../../datasheets/power/tps62135_datasheet_rev_b.pdf) · [Manufacturer PDF](https://www.ti.com/lit/ds/symlink/tps62135.pdf) | Rev.B; April 2017 | pp.1-16: 3-17 V input, 4 A output, PWM/PFM guarantee conditions, feedback current, L/C ranges, PGOOD, adjustable soft start, active discharge and sequencing. SHA-256 `9B718325C5216C529EAA19730D0DEBA8DD72518ECB837C90DD6E839D2B8B811D`. |
| LDO | [TPS7A20 datasheet, SBVS338H](../../datasheets/power/tps7a20_datasheet_rev_h.pdf) · [Manufacturer PDF](https://www.ti.com/lit/ds/symlink/tps7a20.pdf) | Rev.H; July 2024 | pp.1, 6-7, 27-33: voltage/current limits, tolerance, 1.15-ms maximum startup, active discharge and order-code construction. SHA-256 `324FD723C0EE64D7746F6A885AFBFCF10D3B5A26B5CB451931B10F3395E49757`. |
| HVLDO | [TPS7A49 datasheet, SBVS121E](../../datasheets/power/tps7a49_datasheet_rev_e.pdf) · [Manufacturer PDF](https://www.ti.com/lit/ds/symlink/tps7a49.pdf) | Rev.E; May 2015 | pp.1, 6, 12-17: 3-35 V input, 150 mA adjustable output, accuracy, thermal, capacitor and programmable soft-start requirements. SHA-256 `0A5E198966AB05EBB39F4512355352C0946AF5F52E1FBD2E9EC554041123A126`. |
| PGSUP | [TPS3760 datasheet, SBVS420A](../../datasheets/power/tps3760_datasheet_rev_a.pdf) · [Manufacturer PDF](https://www.ti.com/lit/ds/symlink/tps3760.pdf) | Rev.A; April 2023 | pp.3-9 and 17-28: exact DYY pin map, adjustable 0.8 V threshold, threshold/hysteresis accuracy, sense current, open-drain reset, delay-pin states and power behavior. SHA-256 `EB7D626587F369ADE98D55B60823ED28E4B4D955B41181C4443763CF0EEF5E7D`. |
| SUPV | [TPS386000/TPS386040 datasheet, SBVS105F](../../datasheets/power/tps386000_datasheet_rev_f.pdf) · [Manufacturer PDF](https://www.ti.com/lit/ds/symlink/tps386000.pdf) | Rev.F; October 2018 | pp.1, 4, 6-8 and 19-30: four adjustable 0.4-V supervisors, open-drain reset outputs, watchdog and 20-ms/programmable release delay. SHA-256 `02E788626E1D8D546ADA465DC63703635834E41EE109D6C9FC6970A26FB62E98`. |
| SUPV4 | [LTC2962/LTC2963/LTC2964 manufacturer PDF](https://www.analog.com/media/en/technical-documentation/data-sheets/LTC2962-2963-2964.pdf) | Rev.0; August 2018 | pp.1-5 and 8-16: H-grade orderable/package and pins, four +/-0.5% configurable channels, +ADJ threshold/input current, individual outputs, common reset, fixed delay, configuration, power-up/down, and no-hysteresis glitch filtering. Official PDF endpoint was reviewed; direct local acquisition timed out on 2026-09-13. |
| WDT | [TPS3431 datasheet, SNVSB66A](../../datasheets/power/tps3431_datasheet_rev_a.pdf) · [Manufacturer PDF](https://www.ti.com/lit/ds/symlink/tps3431.pdf) | Rev.A; October 2021 | pp.1-3 and 9-18: VSON-8 pin map, enable/SET behavior, open-drain WDO, programmable timeout equation and guaranteed factors. SHA-256 `99BF5DBFFFE06E8F85D9A86CFB777A0151E85B4A103033BC025F4897A0BDC6F3`. |
| ENLOGIC | [SN74LV1T08 manufacturer PDF](https://www.ti.com/lit/ds/symlink/sn74lv1t08.pdf) | SCLS739F Rev.F; October 2025 | pp.4-7 and 10-14: DBV pin map, 1.6-5.5 V VCC, 5.5 V-tolerant inputs, thresholds/output levels, transition-rate rule, and 0.1 uF bypass recommendation. Official PDF SHA-256 `CB0644CAEF3B0DEDEC65C793A2C19707208E377CAF39A12098263FE237A49A94`; reviewed directly from TI, not persisted locally. |
| SEQLATCH | [SN74LVC1G74 datasheet, SCES794G](../../datasheets/logic/sn74lvc1g74_datasheet_rev_g.pdf) · [Manufacturer PDF](https://www.ti.com/lit/ds/symlink/sn74lvc1g74.pdf) | Rev.G; September 2021; current download includes later package addendum | pp.1, 3-8, 10 and orderable addendum: DCU VSSOP-8 pin map, asynchronous preset/clear truth table, 1.65-5.5 V operation, 5.5-V inputs, DC thresholds, `Ioff`, and exact `SN74LVC1G74DCUR` orderable. SHA-256 `E46A5A867FEC742290000DCA5ED3B291535F3C4418EF2AE267ACC4AB51B26D8A`. |
| RSTBUF | [SN74LVC2G07 datasheet, SCES308L](../../datasheets/logic/sn74lvc2g07_datasheet_rev_l.pdf) · [Manufacturer PDF](https://www.ti.com/lit/ds/symlink/sn74lvc2g07.pdf) | Rev.L; May 2015; current download includes later package addendum | pp.1, 3-10 and orderable addendum: DBV SOT-23-6 pin map, dual noninverting open-drain behavior, 1.65-5.5 V operation, overvoltage-tolerant inputs, `Ioff`, output limits, and exact `SN74LVC2G07DBVR` orderable. SHA-256 `71BBB2FC452E2949B332C030B004B094BA679AC8CCE27123F806A0A6B1FDE660`. |
| SCHMITT | [SN74LVC2G17 datasheet, SCES381N](../../datasheets/logic/sn74lvc2g17_datasheet_rev_n.pdf) · [Manufacturer PDF](https://www.ti.com/lit/ds/symlink/sn74lvc2g17.pdf) | Rev.N; January 2015; current download includes later package addendum | pp.1, 3-10 and orderable addendum: DBV SOT-23-6 pin map, dual Schmitt-trigger thresholds/hysteresis, 1.65-5.5 V operation, overvoltage-tolerant inputs, `Ioff`, and exact `SN74LVC2G17DBVR` orderable. SHA-256 `624DBE55679D2FED4123B0D7708CD0D295EFCC78DE395E71A0CAF5CD13CBC216`. |
| AMPGATE | [SN74LVC2G08 datasheet, SCES198N](../../datasheets/logic/sn74lvc2g08_datasheet_rev_n.pdf) · [Manufacturer PDF](https://www.ti.com/lit/ds/symlink/sn74lvc2g08.pdf) | Rev.N; December 2015; current download includes later package addendum | pp.1, 3-10 and orderable addendum: DCU VSSOP-8 pin map, dual positive-AND truth table, 1.65-5.5 V operation, overvoltage-tolerant inputs, `Ioff`, output levels, and exact `SN74LVC2G08DCUR` orderable. SHA-256 `75DFF6A7B9BA988865B776E0F7C5DD2855F13F64F05BFCDA3B1BAEC886007199`. |
| CMDXLAT | [SN74LXC8T245 datasheet, SCES916A](../../datasheets/logic/sn74lxc8t245_datasheet_rev_a.pdf) · [Manufacturer PDF](https://www.ti.com/lit/ds/symlink/sn74lxc8t245.pdf) | Rev.A; March 2023; current download includes later package addendum | pp.1-12, 17-24 and orderable addendum: PW TSSOP-24 pin map, 1.08-5.5 V independent A/B supplies, direction/OE control, integrated I/O pulldowns, `Ioff`, VCC-disconnect/isolation, -40 C to +125 C operation, and exact `SN74LXC8T245PWR` orderable. SHA-256 `814FCE99965A6D693B49708C97D7C2499E91070A9F929E4685F7E7852C5BD32C`. |
| ANISO | [TMUX2821 datasheet, SCDS488](../../datasheets/logic/tmux2821_datasheet_dec_2025.pdf) · [Manufacturer PDF](https://www.ti.com/lit/ds/symlink/tmux2821.pdf) | December 2025; current download includes January 2026 package addendum | pp.1-7, 18-23, 25 and orderable addendum: exact `TMUX2821DSGR`, WSON-8 pin map, 1.8-5.5 V supply, -5.5 to +5.5 V signal range independent of supply, fail-safe SEL with pulldown, powered-off high impedance, leakage, and application requirements. SHA-256 `493E5C0D4EB5CA55DEA82DBCCE59B1BE9C353577E256C161821662C38BB9AC55`. |
| MICISO3G | [TMUX1574 datasheet, SCDS391C](../../datasheets/logic/tmux1574_datasheet.pdf) · [Manufacturer PDF](https://www.ti.com/lit/ds/symlink/tmux1574.pdf) | Rev.C; December 2019; current download includes 2025-10-31 package addendum | pp.1, 3-8 and 22-26 plus orderable addendum: exact active `TMUX1574PWR`, quad SPDT TSSOP pin map/truth table, 1.5-5.5 V supply, beyond-supply signal range, 3.6 V powered-off protection, fail-safe controls, RON/leakage/capacitance and decoupling. SHA-256 `E728F7DBB2A05665C98752FE113662B859ECF6988DC8C58E02A9B49265839867`. |
| SUPV_ALT4 | [TPS3704 datasheet, SNVSF92E](../../datasheets/power/tps3704_datasheet_rev_e.pdf) · [Manufacturer PDF](https://www.ti.com/lit/ds/symlink/tps3704.pdf) | Rev.E; December 2023 | Targeted Phase 3B alternative review: quad/triple/dual monitor organization, accuracy, hysteresis, outputs, delay, package, and orderables. SHA-256 `2C191E129FACF23A1F57FA351C47F4B8857ABA1C04BC110166B64A5CD231B9CC`. |
| SUPV_ALT1 | [TPS3890 datasheet, SLVSD65A](../../datasheets/power/tps3890_datasheet_rev_a.pdf) · [Manufacturer PDF](https://www.ti.com/lit/ds/symlink/tps3890.pdf) | Rev.A; May 2016 | Targeted Phase 3B alternative review: single-channel threshold accuracy/hysteresis, delay, open-drain reset, package, and application limits. SHA-256 `EE79599730E7606BA9718D9820B411020E3DCD9FF7D44572F8EE63FEAD15B9D0`. |
| LVBUF | [SN74LVC244A datasheet, SCAS414AG](../../datasheets/logic/sn74lvc244a_datasheet_rev_ag.pdf) · [Manufacturer PDF](https://www.ti.com/lit/ds/symlink/sn74lvc244a.pdf) | Rev.AG; June 2026 | pp.1, 5-12: 1.65-3.6 V operation, thresholds, output levels, Ioff, 7.2-ns worst-case propagation at 3.3 V and output skew. SHA-256 `CF69EC01F6FC30DF207A3CBCF645FC07DCDA060A0C5AB5A0B77638CF149888F1`. |
| CLKXLAT | [SN74AXC2T245 datasheet, SCES879A](../../datasheets/logic/sn74axc2t245_datasheet_rev_a.pdf) · [Manufacturer PDF](https://www.ti.com/lit/ds/symlink/sn74axc2t245.pdf) | Rev.A; February 2024 | pp.1, 3-18 and 23: 0.65-3.6 V dual rails, DC levels, loading, Ioff/VCC isolation, direction/OE control and clock-rate capability. SHA-256 `FD6CF4A6E830E80E76A2CBCA4351F067DAE9F8E3915D5086104A70E2D72E5D4F`. |
| CLKOSC | [Abracon ASDLJ datasheet](../../datasheets/clock/asdlj_datasheet_rev_a.pdf) · [Manufacturer PDF](https://abracon.com/datasheets/ASDLJ.pdf) | Rev.A; 2025-10-31 | pp.1-4: 24.576-MHz order-code construction, 1.8-V CMOS levels, ±25-ppm option, 1-ms startup, 45-55% duty, 15-pF load and jitter. SHA-256 `2438ABF53B77C249BE7644D5B1E82CF93095B3897CE383794AD4FE07B6A687F4`. |
| CLKBUF | [LMK1C110x datasheet, SNAS791D](../../datasheets/clock/lmk1c1103_datasheet_rev_d.pdf) · [Manufacturer PDF](https://www.ti.com/lit/ds/symlink/lmk1c1103.pdf) | Rev.D; February 2022 | pp.1-12 and 19-22: 1:3 LVCMOS fanout, 1.8-V levels, 50-ps maximum output skew, 50-fs maximum additive jitter, 3-ms startup and synchronous output enable. SHA-256 `4403CE872CF979483288C8194B5036DD0369A55ED9B8A40614FC22C29467B0FD`. |
| AFE | [OPA1652/OPA1654 datasheet, SBOS477B](../../datasheets/afe/opa1654_datasheet_rev_b.pdf) · [Manufacturer PDF](https://www.ti.com/lit/ds/symlink/opa1654.pdf) | Rev.B; December 2016 | pp.1, 5-7, 14-24: 4.5-36 V operation, input/output range, noise, bandwidth, supply bypass and input-overdrive behavior. SHA-256 `819AE541297CDCBD60444B477B8229DE6F863359DA8EF118060A9A2013E4FF8D`. |
| AFE3G | [OPA192/OPA2192/OPA4192 datasheet, SBOS620E](../../datasheets/afe/opa192_datasheet_rev_e.pdf) · [Manufacturer PDF](https://www.ti.com/lit/ds/symlink/opa192.pdf) | Rev.E; November 2015; current download includes 2026-08-10 package addendum | pp.4-11 and orderable addendum: exact `OPA2192IDR`/`OPA4192IPWR`, pins, 4.5-8 V electrical table, common-mode/noise/offset and guaranteed 2-kohm/10-kohm output regions through -40 C to +125 C. SHA-256 `3C01472F1A6A157C7503F5A07083D19359BD7641BC0971F60AAFD572141A87F0`. |
| VREFBUF3G | [OPA320/OPA2320 datasheet, SBOS513F](../../datasheets/afe/opa320_datasheet.pdf) · [Manufacturer PDF](https://www.ti.com/lit/ds/symlink/opa320.pdf) | Rev.F; December 2016; current download includes 2026-07-15 package addendum | pp.4 and 6-9 plus orderable addendum: exact active `OPA320AIDBVR`, SOT-23 pin map, 1.8-5.5 V operation, RRIO limits, offset/drift, input bias, output/load limits and decoupling. SHA-256 `1D13D91BC220D3F37E814E29599CE23E086BD661227618104DCAE5482C8144FC`. |
| FLASH | [IS25LP512M/IS25WP512M datasheet](../../datasheets/memory/is25lp-wp512m_datasheet_rev_a8.pdf) · [Manufacturer PDF](https://www.issi.com/WW/pdf/25LP-WP512M.pdf) | Rev.A8; 2025-04-08 | pp.2, 7-9, 170-177 and 183-185: 512-Mbit capacity, 3.3-V SPI/QSPI operation, currents, power-up rules and valid SOIC order codes. SHA-256 `3BD2BE0CD2F051EBA2634208596851D6D1ED85FE06AF235A9639D2BF8383C281`. |

## Official indexes and references located

These web indexes were checked on 2026-09-06. Lifecycle is a dated manufacturer statement, not an availability or procurement guarantee. Webpage summaries were not substituted for electrical tables.

| Index | Finding / limitation |
| --- | --- |
| [TI TAS6424E-Q1](https://www.ti.com/product/TAS6424E-Q1) | Active; linked SLOSE73A acquired. TI identifies it as an upgraded drop-in replacement for TAS6424-Q1. Exact TAS6424E-Q1 EVM guide SLOU553 was also acquired. |
| [Infineon IM73A135](https://www.infineon.com/part/IM73A135) | Active/preferred; OPN IM73A135V01XTSA1, PG-LLGA-5-2. Official linked PDF is V1.20. |
| [Infineon microphone evaluation kit](https://www.infineon.com/evaluation-board/KIT-IM73A135V01-FLEX) | Five single-microphone flex boards and adapter. Separate electrical schematic/design package not acquired; product registration/access restrictions were not bypassed. |
| [ADI ADAU1978](https://www.analog.com/en/products/adau1978.html) | Production; Rev.B datasheet and UG-600 located. No separate official silicon errata found in reviewed index/search. |
| [ADI ADSP-21569](https://www.analog.com/en/products/adsp-21569.html) | Recommended for new designs; current family datasheet Rev.D, HRM, anomaly list and application notes located. Phase 3 selects `ADSP-21569BBCZ10` for the prototype. Older ADZS-21569-EZKIT is obsolete; EV-21569-SOM is the development reference reviewed. |
| [TI TAS6424-Q1](https://www.ti.com/product/TAS6424-Q1) | Active; linked SLOS870B acquired. TAS6424L-Q1 evaluation links are a different device and were not used to establish exact-variant limits. Exact TAS6424-Q1 EVM guide acquired separately. |
| [TI TIDA-00733](https://www.ti.com/tool/TIDA-00733) | Official design guide acquired and targeted sections reviewed. Demonstrates 96 kHz TDM8; does not repair the datasheet clock wording conflict. |
| [TI TIDA-00743](https://www.ti.com/tool/TIDA-00743) | Additional official reference located only. Its electrical design is not claimed as inspected or used to approve a device. |

## Revision and access limitations

- The DSP product index labels the anomaly document November 26, 2025, whereas the retrieved PDF is NR004735J dated January 29, 2026. PDF identity/revision controls this review.
- Product-index metadata for EE-414 is February 2020, while the PDF is Rev.2, March 15, 2021; EE-447 index metadata is June 28, 2023, while the PDF states May 11, 2023. SOM schematic index metadata is December 18, 2020; its title sheet states January 29, 2020. These discrepancies are retained rather than silently normalized.
- No standalone official IM73A135, ADAU1978 or TAS6424-Q1 silicon errata was located through the respective product indexes and targeted manufacturer-domain searches. This does not certify absence of errata. The current downloaded datasheet revision histories and relevant operating cautions were reviewed.
- No standalone official TAS6424E-Q1 silicon errata was located through its product index and a targeted TI-domain search on 2026-09-08. This does not certify absence of errata. SLOSE73A's mandatory `PHASE_SEL=1` initialization and other operating cautions remain controlling.
- ADC Table 4 versus p.14 HPF values, and TAS6424-Q1 sections 9.3.1.4 versus 9.3.1.5 clock instructions, remain **CONFLICTING**. Neither an evaluation board nor a forum reply overrides these statements.
- Critical PDF tables, pin maps, waveforms and selected reference diagrams were rendered and visually inspected with PyMuPDF. DSP numerical/alphabetical ball lists also underwent an automated 400-entry comparison. This is documentary consistency checking, not future KiCad symbol/footprint validation.
- DSP Tables 36-37 footnotes refer to four SPORTs, while the feature description and HRM DMA list establish eight. Timing-guarantee scope for additional SPORTs remains unresolved; the report uses SPORT0.
- No manufacturer was contacted, no private support result was invented, and no exhaustive review of the entire DSP manual is claimed.

## Reproduce the local audit

Requires Python with PyMuPDF (`fitz`). From repository root:

```powershell
python validation/phase_1/verify_evidence.py
```

The script checks local PDF hashes/page counts/identity, compares both DSP ball lists, calculates the stated interface/latency/workload/power examples, checks Phase 0 coverage and verifies report links and scope. Results are in [verification_results.json](../../validation/phase_1/verification_results.json). A passing evidence-integrity check does not change the engineering gate or establish hardware compatibility. The Phase 1 report is the gate authority for this task.

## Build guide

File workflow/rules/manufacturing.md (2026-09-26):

# Manufacturing

Follow [AGENTS.md](../../AGENTS.md) and the product document's DFM/DFA
and EOL sections. Control exact MPN/alternates, DNP options, assembly
orientation, board-pair traceability, fixture access and release artifacts.
Keep calculated/datasheet-backed validation separate from physical EVT,
DVT, PVT and factory EOL evidence. Do not treat a clean ERC/DRC or an
unmeasured protection concept as a production release.

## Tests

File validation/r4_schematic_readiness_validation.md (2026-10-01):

# R4 schematic-readiness validation

Date: 2026-09-28. R3 human gate: **APPROVED** by the project owner's R4 instruction; recorded in `state/project_state.json` and `validation/r3_system_architecture_validation.md`. R3→R4 entry machine gate: **PASS** with `python workflow/gates/run.py --phase R3 --next-phase R4`. The runner was corrected so findings due during R4 block R4 completion, not R4 entry.

R4 was evaluated with `python workflow/gates/run.py --phase R4 --next-phase R5`. The machine result is **BLOCKED**. Its detailed result and the no-KiCad check are recorded below. The report and all three R4 machine contracts parse; the R4 engineering proof is incomplete. A parseable file is not evidence of an electrically ready sheet.

| R4 gate | Result | Meaning |
| --- | --- | --- |
| Documentation contract | **PASS** | All 19 required references exist. |
| Blocking findings | **BLOCKED** | `PV1-R1-001`, `002`, `004`, `009`, `011`, `012`, `013` are due by R4. All 13 records and state agree. |
| Product architecture | **PASS** | Board A/B and the controlled B2B signal inventory remain coherent. |
| Strict R4 schematic gate | **BLOCKED** | All 12 planned sheets are BLOCKED; full MCU pin map and loaded B2B DC/timing/off-domain proof are incomplete. Listed provisional MCU pads/balls are unique and avoid reserved boot/debug pads. |
| R4→R5 transition | **PASS as allowed route only** | The phase definition permits R5 after completed R4 and human approval; the runner made no transition. |

No KiCad file was created or modified. Product V1 ERC, DRC, hierarchical interface, pin and BOM adapters remain `NOT_AVAILABLE`; no electrical simulation, physical measurement or acoustic test is claimed. The R3 conceptual dependency graph is acyclic, but the actual circuit graph, threshold/hysteresis margins, loaded B2B timing and powered-off drive are not proven. R5 is not authorized.

Additional consistency check: all six machine JSON files parse; 23 provisional RT1062 allocations have 23 unique pads and balls; the unresolved finding set exactly matches `state/project_state.json`; `hardware/product_v1` contains no KiCad artifact and the Git diff lists no modified `*.kicad_*` file. The runner JSON reports `machine_result: BLOCKED` and returned a nonzero shell status. The R3→R4 gate was also rerun from the present R4 state and remained **PASS**.
 
## R4 closure-pass rerun, 2026-09-28

The original BLOCKED result above is preserved. This pass added official-document screening and `validation/r4_closure_calculations.py` for conditional audio-buffer DC/timing and rail calculations. The script ran successfully; its results are conditional on stated load, rail and interconnect bounds and do **not** establish R5 readiness. The seven original R4 findings received appended evidence entries without deletion or status downgrades. Board A/B contracts and the B2B interface retain `BLOCKED` / `r5_ready=false` for unproven circuits.

`python workflow/gates/run.py --phase R4 --next-phase R5` returned exit code **1** and `machine_result: BLOCKED`. Documentation contract **PASS** (19 references), product architecture **PASS**, blocking findings **BLOCKED** (PV1-R1-001, 002, 004, 009, 011, 012, 013), strict R4 schematic-readiness **BLOCKED** (all 12 R5 sheets, RT1062 fixed resources, Board A/B guaranteed circuits, B2B DC/timing/off-state). The route definition allows R5 only after a completed R4 and human approval; the runner made `phase_state_changed: false`. No ERC claim was made.

The current NXP RT1060 Reference Manual Rev 4 and Hardware Design Guide Rev 7 are account-required; the owner has no authorized copies. Exact missing chapters/sections and all seven closure criteria are listed in the R4 report section 9. Adapter range/current and safety response target were requested from the owner but were not presumed. No Product V1 KiCad file was created or modified; `hardware/product_v1` has no `*.kicad_*` artifact and `git diff --name-only -- '*.kicad_*'` is empty. Product V1 KiCad hooks remain `NOT_AVAILABLE`. R5 was not started.

## Owner-input and authorized-NXP-manual rerun, 2026-09-30

The two preceding R4 BLOCKED results remain historical. The owner supplied authorized local NXP `IMXRT1060RM` Rev. 4 and `MIMXRT105060HDUG` Rev. 7 copies; they are now indexed in `docs/product_v1/component_evidence_index.md`. The earlier **access-based** `MISSING_AUTHORITATIVE_EVIDENCE` reason is retired. The owner also classified 12 V nominal as provisional, removed the PoC 10-A assumption, supplied a provisional engineering mute target of <=10 ms, and explicitly kept production response/SPL acceptance open for later safety testing. Section 10 of the R4 report records the bounded calculations and per-finding gap.

`python validation/r4_closure_calculations.py` passed. It calculated PLL4 VCO 786.432 MHz, post-divider 196.608 MHz, SAI1/SAI2 roots 24.576 MHz, ADC BCLK 12.288 MHz and amplifier BCLK 6.144 MHz from the current NXP RM. Its ADC receive setup margin is **7.69 ns before skew** at TI's 25 °C/20-pF condition, **2.69 ns at the proposed 5-ns skew**. Those figures are conditional, not loaded or full-temperature signoff. The provisional 8–18-V input screen yields assumed-load currents of 7.922 A at 12 V and 10.862 A at 18 V; these are not adapter ratings because Board A load and power efficiency were assumed. A fastest screened watchdog timeout up to 9.3 ms leaves only 0.7 ms against the owner's provisional fault-to-mute target, with no proved output-decay time.

The calculation script also checks a **non-frozen** 24-bit TDM mitigation at 9.216-MHz ADC BCLK. It raises conditional 25 °C/20-pF setup room to about 16.25 ns after the proposed 5-ns skew while preserving a 6.144-MHz amplifier BCLK with a different PLL divider profile. The current machine contracts retain the R3 four-by-32-bit baseline until the entire framing and loaded timing proof is complete.

After correcting an initially added finding metadata field that the repository schema disallows, `python workflow/gates/run.py --phase R4 --next-phase R5` returned exit code **1** and `machine_result: BLOCKED`: documentation **PASS**, findings **BLOCKED** (the same seven original IDs), architecture **PASS**, strict schematic gate **BLOCKED**, and allowed-route definition **PASS** without a transition (`phase_state_changed: false`). All seven findings have appended evidence and unchanged blocking statuses. No R5 sheet was promoted because its exact analog, boot, power, safety or interface circuit is still incomplete. The current phase and machine result in `state/project_state.json` remain R4/BLOCKED; R5 remains unauthorized.

No Product V1 KiCad artifact was created or modified: recursive `hardware/product_v1` `*.kicad_*` search returned no file and `git diff --name-only -- '*.kicad_*'` was empty. Product V1 KiCad hooks remain `NOT_AVAILABLE`; ERC was neither run nor claimed.

## Focused R4-A Board A closure, 2026-09-30

`validation/r4a_board_a_closure.md` records selected Board A AFE, native FlexSPI boot and power circuits for findings 001, 002 and the Board A portion of 012. Manufacturer-backed values include the OPA2320 dual buffer and 2.8-V microphone rail, the NXP EVKB 1.8-V 64-Mbit flash, explicit boot straps and fixture resistors, a 24-MHz crystal candidate, a 4.7-uH RT1062 DCDC inductor, MCU_3V3 supervisor threshold and exact regulator order codes. `validation/r4a_closure_calculations.py` checks adverse feedback-divider/FB-leakage rail limits, LDO output tolerances, supervisor thresholds, DCDC RC tolerance, and conditional AFE/thermal screens. The assumptions and unbounded parameters are named in the focused report.

`python validation/r4a_gate.py` returned **R4-A: BLOCKED** and wrote `validation/r4a_gate_result.json`. All focused structural and arithmetic checks passed. The electrical closure criteria remain unmet: 001 lacks guaranteed 96-kHz ADC impedance/noise/phase and targeted four-channel bench proof; 002 lacks a tested FCB, production fuse/security/update policy and reset/recovery circuit; Board A 012 lacks guaranteed current, capacitor/thermal, ramp and POR proof. The full 012 finding additionally includes Board B/interface work outside this focused task. The R4 result remains BLOCKED, all three finding blockers remain in project state, and R5 is not authorized.

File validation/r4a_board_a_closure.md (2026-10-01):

# R4-A Board A circuit closure, updated 2026-10-01

**Focused result: BLOCKED.** Scope is PV1-R1-001, PV1-R1-002, and the Board A portion of PV1-R1-012. The choices below are the Board A design baseline where manufacturer evidence and arithmetic permit one. R4-A still requires deterministic schematic-ready hardware and manufacturer-backed worst-case electrical proof. Physical bench and tested firmware obligations are retained for R14; Board B/interface closure remains in global R4. No KiCad or Board B implementation was changed.

## 1. Four microphone channels: selected circuit and limiting corners

Use four electrically identical IM73A135 ports. Each differential leg enters a 100-ohm series resistor and one channel of an `OPA2320AIDGKR` dual op amp in unity feedback (four dual packages total). Put `TPD2E2U06DRLR` dual ESD protection at each connector, ahead of the buffer. Each buffer output passes a 47-ohm series resistor, with 1 nF to analog ground on the ADC side, then a separate 10-uF, 5% film AC-coupling capacitor into its TLV320ADC5140 differential input. `MKS2B051001N00JSSD` is a procurement candidate for each film capacitor; its current WIMA manufacturer availability and full temperature capacitance are not established, so it is not a released BOM item. ADC profile: AVDD/IOVDD 3.3 V; VREF 2.75 V; all four channel input impedances set to 20 kohm *typical* (P0_R60/65/70/75 bits 3:2 = `10`); PGA 0 dB; DRE/AGC disabled for four channels at 96 kHz. Set P0_R107 bits 1:0 to `00` with the default all-pass coefficients at P4_R72-83: the default HPF selection would otherwise cut at 24 Hz at 96 kHz. Set the coupling quick-charge register P0_R5 bits 5:4 to `11` for 50 ms *typical* duration and measure 10-uF settling before samples are trusted (TI SBAS892A pp.33,64,94). Confirm the complete register image/readback. The ADC's internal antialias filter is the audio-band antialias stage; the external 47-ohm/1-nF network is for RF/EMI.

Infineon v1.20 Table 6 (p.8) requires at least 25 kohm resistance on each mic output and at most 100 pF per output. The unity-buffer CMOS input avoids the ADC's 20-kohm *typical* direct load. TI OPA2320 SBOS513F pp.7-9 bounds input bias at 400 pA per channel at -40 to 125 C, while TI TPD2E2U06 SLLSEG9C specifies at most 10 nA leakage and 1.5 pF *typical* capacitance. Even taking the ESD leakage as a DC shunt at 1.35 V gives about 130 Mohm; the mic sees no intentional resistive load. A 75-pF harness/connector allocation plus the 4-pF typical op-amp common-mode input and 1.5-pF typical ESD capacitance sums to 80.5 pF before PCB parasitics. This **does not** prove 100 pF at the corner because the protection device publishes no maximum line capacitance, the mic's 250-ohm output impedance is typical, and the cable is not selected. The hardware port acceptance limit is 100 pF including all parasitics, measured on the actual harness.

With 20 kohm *typical* ADC input and 10 uF nominal coupling, the first-order high-pass corner is 0.796 Hz. At 5% low capacitance it is 0.838 Hz, giving 2.40 degrees of phase lead at 20 Hz. This is **not a worst-case low-frequency bound**: TI SBAS892A p.28 calls the ADC impedance typical and does not give a minimum. The 47-ohm/1-nF pole is 3.39 MHz nominal, above audio; the ADC internal antialias behavior still requires the chosen 96-kHz register profile. The mic's own typical 20-Hz acoustic cutoff and phase response (Infineon pp.6-7) are separate from the electrical high-pass calculation.

For an upper-level *linearity screen only*, Infineon's highest specified 94-dB SPL sensitivity of -37 dBV extrapolated to its **typical** 135-dB SPL overload point gives 1.585 Vrms differential. The ADC's 2-Vrms full scale at 3.3-V AVDD (TI SBAS892A pp.7,28) leaves 2.02 dB. A balanced leg would swing about 1.12 V peak about the mic's 1.35-V **typical** output DC, or roughly 0.23 to 2.47 V, inside a 3.25-V OPA supply even allowing its 45-mV worst output swing from rails at 2-kohm load (TI SBOS513F p.8). Infineon's AOP and output DC are typical, and sensitivity is specified at 94 dB SPL; this extrapolation cannot certify overload clipping or common-mode at all temperatures. Similarly, the 73-dB(A) mic SNR, 8.5-nV/âˆšHz OPA noise and 107-dB ADC SNR are at differing specified conditions, with ADC 48-kHz rather than 96-kHz data. Manufacturer-backed worst-case 96-kHz noise, response, clipping and phase bounds are required for R4-A closure of 001. The four-channel sweep over operating temperature and selected harness remains open as physical validation required by R14.

## 2. Native RT1062 boot: selected hardware baseline

Select `IS25WP064AJBLE`, 64 Mbit, 1.8 V, from the NXP MIMXRT1060-EVKB reference (user manual Table 17 p.20), on `NVCC_SD1=1.8 V`. Connect FlexSPI A CS/SCLK/IO0-3 to GPIO_SD_B1_06/07/08-11 as already allocated. NXP IMXRT1060RM Rev 4 pp.194,210-213 confirms this ROM pinout, 512-byte FCB at flash offset 0 and an initial 30-MHz read. Section 5 records the selected ISSI command and FCB field profile. LUT binary encoding and timing remain R4-A proof; the generated production image and hardware read/boot test remain firmware bring-up validation required by R14.

For unfused internal boot, set BOOT_MODE[1:0] to `10`: 4.7-kohm 1% pullup on MODE1 (GPIO_AD_B0_05) to NVCC_GPIO and 4.7-kohm 1% pulldown on MODE0 (GPIO_AD_B0_04). Reserve all BT_CFG0-11 pins and pull each down with 10 kohm for the zero FlexSPI NOR/3-byte initial read setting. The fixture enters ROM Serial Downloader mode `01` by pulling MODE1 to ground and MODE0 to the sensed powered NVCC_GPIO through 1-kohm 1% resistors before POR_B release. Section 5 proves static levels at adverse rail/resistor/internal-pull corners; transient capture and fixture drive still require schematic proof. Provide SWDIO E14, SWCLK F12, POR_B, ground and powered 3.3-V reference; fixture outputs must be high impedance whenever NVCC_GPIO is absent. UART1 TX/RX K14/L14 are the ROM recovery connection with 10-kohm pullups per NXP HW7 p.9. USB1 is outside the V1 recovery dependency. NXP RM pp.197-200 and HW7 pp.9-11 support the mode and pull strategy.

Use the `ECS-240-8-33B2-CKM-TR3` 24-MHz, 8-pF, 40-ohm maximum ESR crystal candidate between XTALI P11 and XTALO N11, with NXP's 2.2-Mohm XTALI-to-ground bias. A 12-pF capacitor at each crystal pin corresponds to 8-pF load only if pin/trace stray is 2 pF per side: `CL = 12/2 + 2 = 8 pF`. Release of the two capacitor values still requires a bounded stray-capacitance allocation and manufacturer-backed oscillator start, drive and USB-clock calculations. Physical clock startup and USB testing are due R14. Keep SWD as the default debug mode, JTAG_MOD and TRST_B at 4.7-kohm pulldown per HW7 pp.7-8.

R4-A2 freezes V1 at unfused internal boot: BT_FUSE_SEL and BOOT_CFG OTP fields remain factory-default, HAB remains open, and no production or field fuse burn is part of this circuit contract. Factory programming and field recovery use a powered service fixture that forces BOOT_MODE `01` before POR_B release, then communicates over ROM LPUART1; there is no V1 OTA or application update route and no dependence on USB recovery. SWD remains available for enclosed service/debug. This avoids a programmed-fuse recovery path that could disable the physical strap override. The complete FCB field layout, clock and other-rail reset circuits still need schematic proof. A tested boot image, measured POR waveform and dead-flash recovery run remain due R14. Finding 002 stays blocking for its remaining hardware requirements.

## 3. Board A portion of the power contract

Selected rail topology from a **required receiving envelope** of 4.5-5.5 V at Board A: `TPS62135RGXR` forced-PWM buck makes MCU_3V3 with 255-kohm top and 68.1-kohm bottom 1% feedback resistors; `TPS7A2033PDQNR` from received 5 V makes ADC/AFE_3V3; `TPS7A2028PDQNR` from MCU_3V3 makes MIC_2V8; `TPS7A2018PDQNR` from MCU_3V3 makes FLASH_SD1_1V8. The TPS7A20 parts use at least 1-uF *effective* input and output capacitance, EN tied to their parent rail unless a sequencing gate is proven necessary. The 2.8-V mic selection replaces the earlier nominal 2.75-V target and stays inside the Infineon 2.3-3.0-V operating range. TI TPS7A20 SBVS338H pp.5-7 gives the guaranteed output tolerance only at its VIN, load, capacitor and TJ conditions; this is why the calculation uses the buck's minimum voltage. All GPIO/EMC and HIGH/DCDC/ADC supply balls must be connected to their assigned powered domain; *_CAP outputs are decoupled and never used as external supplies (NXP CEC Rev 4 pp.26,30-31).

For the buck, TI TPS62135 SLVSBH3B pp.4-6 requires 3-17 V VIN, `VIN >= VOUT+1 V` for the +/-1% PWM feedback specification, 0.6-2.9 uH effective inductance, 6-200 uF effective output and at least 3 uF effective input capacitance. Select `XAL4020-102MEC`, 1 uH +/-20%, with [Coilcraft](https://www.coilcraft.com/en-us/products/power/high-voltage-inductors/xal/xal40xx/xal4020-102/) 14.6-mohm maximum DCR and 8.7-A 10%-drop Isat at 25 C. Specify 10-uF nominal X7R input (>=3-uF effective) and 2 x 22-uF nominal X7R local output (22-200-uF effective). Exact capacitor order codes/bias curves and hot inductor derating remain open. Adverse 1% divider, +/-1% FB voltage and 70-nA FB leakage yield **3.2185-3.4259 V**, within NXP's 3.0-3.6-V bank range. The maximum requires at least 4.426 V at the buck VIN for the documented PWM accuracy, so a 4.5-V Board A receiving minimum has only 74 mV margin before trace/ripple. This receiving requirement is **not yet guaranteed by Board B or the connector**. The LDO conditional ranges are MIC 2.758-2.842 V, flash 1.770-1.830 V and ADC/AFE 3.2505-3.3495 V. The TPS7A20 MIC 2.8-V accuracy needs VIN >=3.1 V, met by the calculated buck minimum; the 1.8-V part needs VIN >=2.3 V. ADC/AFE 3.3 V needs VIN >=3.6 V, met by the proposed 4.5-V receiving minimum. These DC bounds exclude ripple and transient excursions.

Tie VDD_SNVS_IN directly to VDD_HIGH_IN; there is no backup battery. For the RT1062 internal DCDC, select a 30-kohm 1% / 0.22-uF 10% DCDC_PSWITCH RC (5.881-7.333 ms component product) and `XFL4020-472MEC` 4.7-uH inductor. Coilcraft quotes 57.4-mohm maximum DCR and 2.0-A 10%-drop saturation current at 25 C; NXP HW7 pp.5-6 requires 4.7-10 uH, Isat >1 A and ESR <0.2 ohm. Specify **at least 33 uF effective** total on DCDC_OUT/VDD_SOC_IN in addition to every HW7 Table 2 pin-local capacitor group. Exact capacitor order codes/bias curves, hot inductor derating and the DCDC_IN ramp must be proven. NXP HW7 pp.4-5 also requires DCDC_IN reach 3.0 V within 0.3 RC, DCDC_PSWITCH reach 1.5 V at least 1 ms after DCDC_IN is stable, and POR_B remain low until all rails stabilize. An RC product alone cannot prove those relative edges.

Select `TPS389030DSER` to monitor MCU_3V3 and pull POR_B low with its open-drain RESET output. A 10-kohm pullup to the tied SNVS/HIGH_IN rail and a 10-nF 10% CT capacitor set the initial circuit. TI TPS3890 SLVSD65A pp.3-5 gives nominal falling/rising thresholds 2.890/2.907 V with +/-1% accuracy; adverse falling minimum is **2.861 V**, 261 mV above NXP's 2.6-V internal DCDC low-detect level, and adverse rising maximum is **2.936 V**, 282 mV below the calculated MCU_3V3 minimum. CT threshold/current limits imply roughly 7.8-15.8 ms release delay for the selected capacitance, before any other gate delay. The supervisor's MR input is reserved for an all-other-rails-valid gate; without that circuit and worst-case ramp/timing calculations, this is **only a verified MCU_3V3 threshold**, not a complete POR_B release proof. Measured waveforms remain due R14. The supervisor also needs powered-off RESET and pullup behavior checked against the RT1062 SNVS domain.

### 3.1 Connected consumers and sizing limits

The calculation in `validation/r4a_closure_calculations.py` uses one simultaneously active 96-kHz four-channel capture/XIP case, plus the separate flash program/erase peak. ADC BCLK/FSYNC is **128**, whereas TI SBAA379 Table 1's 25.68-mA AVDD datum uses **96**; that datum and TI SBAS892A p.10's 21.3-mA 48-kHz datum are **typical context only**. Current allocations below are design ceilings that firmware, attached loads and R14 measurement must respect. They are not semiconductor guarantees.

| Rail / selected regulator | Every connected consumer and source of current | Calculated allocation / limit |
| --- | --- | ---: |
| `MCU_3V3`, TPS62135RGXR | RT1062 DCDC_IN 110, HIGH_IN 50, VDDA_ADC_3P3 40, SNVS_IN 0.25 mA: NXP CEC Table 12 specified maxima. NVCC_GPIO/EMC 20, ADC IOVDD 5, boot/debug pulls 5, supervisor 1, mic LDO output 7 plus ground 2, flash/SD1 LDO output 60 plus ground 2, output transient 20 mA: design allocations. | 322.25 mA itemized; **350 mA ceiling**, 27.75 mA unallocated. |
| `ADC_AVDD_3V3`, TPS7A2033PDQNR | TLV320ADC5140 AVDD 50 mA **design**; eight OPA2320 channels 13.6 mA guaranteed *no-load* IQ maximum per TI SBOS513F p.9; their eight output/filter legs 4 mA design; bleeder/other analog 2 mA; unallocated 5.4 mA. ESD leakage and passive bias paths are within the analog allocation. | **75 mA ceiling**; TI TPS7A20 rated 300 mA, thermal is limiting. |
| `MIC_2V8`, TPS7A2028PDQNR | Four IM73A135 at 1 mA design each, 2.2-kohm 1% minimum-load bleeder at most 1.31 mA, unallocated 1.69 mA. Infineon Table 7's 230-uA maximum per mic applies at 2.75 V, 25 C and input <=94 dBSPL, not at all supply, temperature and acoustic corners. | **7 mA ceiling**. |
| `FLASH_SD1_1V8`, TPS7A2018PDQNR | IS25WP064A core 30 mA maximum during program/status-write/erase at 125 C (ISSI Rev A11 section 9.3); RT1062 NVCC_SD1 and six FlexSPI pads 15 mA design; 1.5-kohm 1% bleeder, other flash I/O and transient inside 15 mA reserve. The 12-mA 50-MHz normal-read core maximum excludes flash output switching. | **60 mA ceiling**. |
| Board A received 5 V | Buck input at 4.5 V and assumed >=70% efficiency, ADC LDO 75 mA plus 2-mA ground allocation, one active USB VBUS port 25 mA per NXP CEC Table 12, 10 mA input misc, separate 200-mA input startup/step reserve. | 492.66 mA continuous design, 692.66 mA with startup; **750 mA receiving ceiling**, 57.34 mA remaining under the assumed efficiency. |

NXP CEC Table 12 gives `I = N C V (0.5 F)` for switching banks. At 25 active GPIO/EMC pads, 30-pF load, 3.4259 V and 12.288 MHz, the screen is 15.79 mA within the 20-mA allocation. Six SD1 pads at 30 pF, 1.83 V and 30 MHz screen at 4.94 mA within 15 mA. Pad count, 30-pF load, clock toggle fraction and simultaneously driven currents are **design assumptions**; revise the ceiling if the final mux, connector or fixture exceeds them. No USB bus-powered external load is authorized inside this budget. The 20-mA buck-output and 200-mA input-step reserves are independent of the listed steady-state loads; switching events above them require load control or a revised contract.

### 3.2 Regulator, dissipation and thermal screen

Set each TPS7A20 input and output to 4.7-uF nominal X7R with **>=1 uF effective** after voltage bias, tolerance and -40..85-C temperature. TI SBVS338H pp.5-7 specifies output accuracy for 1-300 mA, so add 2.7-kohm 1% to ground at ADC 3.3 V, 2.2-kohm 1% at MIC 2.8 V, and 1.5-kohm 1% at FLASH 1.8 V. At worst low output and high resistance these sink 1.192, 1.241 and 1.168 mA respectively. The three LDOs therefore meet the accuracy table's minimum-load condition even when devices sleep. Input/output cap order codes and effective-value curves still require selection. The RT1062 DCDC output target is 2 x 47-uF nominal X7R for >=33-uF effective total, plus each NXP HW7 Table 2 local capacitor; exact codes/derating remain open.

At 85-C **local** ambient and TI's JEDEC reference-board thermal resistances, ADC LDO dissipation is `(5.5-3.2505)*0.075 + 5.5*0.002 = 0.1797 W`, hence `TJ=114.85 C`, 10.15 C below 125 C. The 2-mA ground current is an imposed ceiling: TI's 2-mA figure is **typical** at 300-mA load, not a maximum. Mic and flash LDO screens are 0.0115/0.1062 W and 86.91/102.64 C respectively. With 350 mA and 3.4259 V, buck output is 1.1991 W. An **assumed**, acceptance-tested 70% minimum efficiency implies 0.5139-W converter loss, `TJ=104.73 C` on TI's 38.4-C/W RGX reference board and 20.27-C margin. TI does **not** guarantee a 70% floor or whole-converter loss at this corner. Reference thermal resistances are not guaranteed product-board values. Conservative package screens using NXP 12-mm RT1062 39.1-C/W, TI ADC RTW 32.6-C/W and OPA2320 DGK 174.8-C/W give 114.50, 91.01 and 87.58 C respectively; these assume the same reference-board heat path and the allocated package input powers. The ADC and OPA screens also depend on the imposed current ceilings.

TI TPS62135 SLVSBH3B pp.5-6 specifies 4.8-A minimum/6.5-A maximum high-side current limit and hiccup protection; its thermal shutdown is protection, not continuous operation. TI TPS7A20 SBVS338H p.7 gives 360-730-mA output-current limit under its stated test and a **typical-only** 160-mA hard-short current. At 5.5-V input, the ADC LDO's 730-mA fault-current upper value at 90% output could dissipate about `(5.5-2.97)*0.73 = 1.85 W` before shutdown, far above the continuous 0.1797-W screen; rail shorts must be handled by input-source current limiting/trace coordination and thermal shutdown without claiming a continuous safe junction. Size the buck inductor for the 6.5-A switch-limit corner: the selected XAL4020-102MEC has 8.7-A 10%-drop Isat at **25 C**, but its hot derating remains to be checked. Board A's 750-mA input ceiling and fault-energy limit must be enforced by the upstream Board B/interface design, outside this subtask.

**Exact remaining proof inputs for `012_a_load_power`:** (1) TI guaranteed four-channel 96-kHz, BCLK/FSYNC=128 ADC AVDD/IOVDD maxima, or formal acceptance of the 50/5-mA allocated ceilings with enforced load modes; (2) a TPS62135 guaranteed minimum efficiency/maximum loss at 4.5-5.5 V, 350 mA forced PWM, or an accepted 70% floor backed by product thermal tests; (3) exact capacitor MPN/bias/temperature curves proving all stated *effective* minima/maxima and hot Isat/DCR for both inductors; (4) product-board effective thermal resistances and local ambient demonstrating <=125-C junction for the regulator/MCU/ADC/OPA cases, plus maximum LDO ground-current bounds; (5) enforceable upstream current/fault-energy limit for the 750-mA receiving envelope. These prevent unconditional R4-A load/thermal closure today. R14 still requires measured 96-kHz/flash currents, transient, startup and enclosed-board thermal behavior; it cannot retroactively make a typical value a guaranteed maximum.

## 4. Focused disposition

Section 3 now records the focused Board A engineering load and thermal envelope. Section 5 retains the preceding 2026-10-01 evidence audit; where it mentions the former 100-mA ADC LDO screen, the selected 75-mA envelope and its assumptions in section 3 supersede it.

The finding files retain `blocks_from_phase=R4` because each still has a genuine schematic-entry obligation. The later obligations are preserved as open atomic requirements with `required_by_phase=R14` in `state/project_state.json`; changing the due phase of a whole mixed finding would hide its R4 electrical blocker. Finding 012's Board B/interface obligation stays due for **global** R4 but is excluded from focused R4-A.

| Remaining obligation | Classification | Required by | R4-A effect |
| --- | --- | --- | --- |
| 001: bounded microphone loading, ADC impedance and calculated 96-kHz performance | `SCHEMATIC_ENTRY_BLOCKER` | R4 | Blocks |
| 001: selected-harness four-channel 96-kHz sweep | `PHYSICAL_BENCH_VALIDATION` | R14 | Excluded |
| 002: flash/FCB configuration, straps, clock, recovery circuit and reset | `SCHEMATIC_ENTRY_BLOCKER` | R4 | Blocks |
| 002: recovery, fuse/security and update policy that determines hardware | `SCHEMATIC_ENTRY_BLOCKER` | R4 | Closed in R4-A2 |
| 002: built and tested RT1062 production boot image | `FIRMWARE_BRINGUP_VALIDATION` | R14 | Excluded |
| 002: executed dead-flash recovery and update/security tests | `FIRMWARE_BRINGUP_VALIDATION` | R14 | Excluded |
| 002: measured clock startup, USB tolerance and fixture levels | `PHYSICAL_BENCH_VALIDATION` | R14 | Excluded |
| 012: guaranteed Board A loads, derated parts, rail margins and calculated thermal proof | `SCHEMATIC_ENTRY_BLOCKER` | R4 | Blocks |
| 012: exact all-rail startup/POR circuit and worst-case timing | `SCHEMATIC_ENTRY_BLOCKER` | R4 | Blocks |
| 012: measured ramp/transient and populated-board thermal proof | `PHYSICAL_BENCH_VALIDATION` | R14 | Excluded |
| 012: Board B input, 5-V delivery and interface protection | `LATER_BOARD_B_OR_INTERFACE_WORK` | global R4 | Excluded |

PV1-R1-001 is **open** for bounded ADC impedance/capacitance and 96-kHz electrical proof. PV1-R1-002 remains **accepted, blocking** for complete FCB, clock, reset and recovery electrical details; the service/security policy and static boot-strap levels are now frozen. PV1-R1-012 is **open** for Board A guaranteed loads, derated parts, thermal and startup calculations; the flash core current segment is bounded. Its Board B/interface portion blocks global R4 only. Physical AFE, power and recovery measurements and a tested boot image remain open for R14. Board A contract and pin map remain blocked on schematic electrical issues; R5 remains unauthorized.

Reproduce the arithmetic with `python validation/r4a_closure_calculations.py` and run the focused machine gate with `python validation/r4a_gate.py`. The focused gate rejects a PASS when these known evidence gaps remain.
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

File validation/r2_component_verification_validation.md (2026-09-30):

# R2 component-verification validation

Date: 2026-09-28. Scope: Product V1 manufacturer evidence, architecture candidates, controlled findings/state, and the R2 documentation gate. No KiCad, schematic, PCB, ERC, DRC, acoustic measurement, or physical electrical test was performed.

Reproduce from the repository root:

```text
python workflow/gates/run.py --phase R2
```

| Machine check | Result |
| --- | --- |
| Documentation contract | **PASS** — nine R2 required file references exist. |
| Blocking findings | **PASS** — no blocker is due by R2; all 13 later blockers remain tracked. |
| Product architecture | **PASS** — both boards and the controlled interface remain represented; no Product V1 KiCad project is claimed. |
| R2 component verification | **PASS** — report/decision matrix, four component fact records, primary-source evidence references, preserved findings, and future KiCad hooks marked `NOT_AVAILABLE`. |

The runner returned `machine_result: PASS`, `human_gate: NOT_EVALUATED`, and `phase_state_changed: false`. The gate checks documentation and structural coherence. Technical conclusions and limits are in the [R2 report](../docs/product_v1/phase_r2_component_verification.md), with official manufacturer sources in the [evidence index](../docs/product_v1/component_evidence_index.md). All four core components are provisionally approved for architecture; the microphone-to-ADC network, exact controller boot variant and clock/pin map, independent safe-state hardware, power and speaker headroom remain open at their assigned later gates.

R2 PASS does not constitute schematic readiness or authorization to begin R3.

**Human gate approval (2026-09-28): APPROVED.** The project owner explicitly accepted the R2 result and authorized Phase R3 in the subsequent repository instruction. This approval accepts the provisional component architecture and its recorded open R3/R4 dependencies; it does not approve component circuits or schematic entry.

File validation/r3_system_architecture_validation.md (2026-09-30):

# R3 system-architecture validation

Date: 2026-09-28. The project owner approved the R2 human gate before R3 work; the approval is recorded in [R2 validation](r2_component_verification_validation.md) and `state/project_state.json`. Scope: architecture ownership, digital-audio/clock calculations, board-interface signal inventory, dependency graph, structured findings and phase-state coherence. No KiCad, schematic, PCB, ERC, DRC, loaded electrical test or acoustic test was performed.

Reproduce from repository root:

```text
python workflow/gates/run.py --phase R3
```

| Check | Result |
| --- | --- |
| Documentation contract | **PASS** — R3 report, architecture contract, interface and validation record exist. |
| Blocking findings | **PASS** — no unresolved blocker is due by R3; all 13 findings remain tracked with explicit later-phase closure. |
| Product architecture | **PASS** — both product boards and one controlled B2B contract remain represented; no Product V1 KiCad project is claimed. |
| R3 system architecture | **PASS** — ownership, audio-clock math, ten active logical B2B classes, 14-contact provisional floor, safe/default/power-off behavior, and independently computed acyclic startup graph parse consistently. Future KiCad hooks remain `NOT_AVAILABLE`. |

The machine runner result is **PASS**, its human gate is `NOT_EVALUATED`, and it makes no phase-state change. The machine result confirms structural and evidence traceability, **not** measured signal integrity, microphone network, speaker headroom, ANC performance or schematic readiness. R4 must calculate/verify exact loaded timing, off-domain isolation, rails/current and hardware fault response; acoustic/mechanical decisions retain their later gates. R3 does not authorize R4 automatically.

**Human gate approval (2026-09-28): APPROVED.** The project owner explicitly accepted the R3 architecture result and authorized Phase R4 in the subsequent repository instruction. The approval preserves R4 circuit and electrical blockers; it does not approve schematic entry.

**R3→R4 entry machine gate (2026-09-28): PASS.** Reproduced with `python workflow/gates/run.py --phase R3 --next-phase R4` after recording approval. The gate runner was corrected to evaluate blockers due by the phase being exited; R4 work items remain blockers for **R4 completion**, not entry. The runner itself made no state change.

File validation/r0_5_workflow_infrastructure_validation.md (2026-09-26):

# R0.5 workflow infrastructure validation

Date: 2026-09-26. Scope: repository process artifacts only; no electrical, component, ERC, DRC or KiCad verification.

Reproduce:

```text
python -m pip install -r workflow/requirements.txt
python validation/r0_5/verify_workflow.py
python workflow/gates/run.py
```

| Check | Result |
| --- | --- |
| JSON parsing and Draft 2020-12 finding-schema validation | **PASS** — five JSON artifacts parsed at R0.5; the R1 compatibility rerun parsed 18 including new findings. Schema and finding template validate. |
| R0-derived state and interface | **PASS** — two boards, seven open decisions, no Product V1 KiCad projects; connector/pin/voltage/count values remain unset. |
| Phase and repository paths | **PASS** — 16 phase contracts (R0, R0.5, R1–R14) have repository-contained paths; planned KiCad outputs point only into `hardware/product_v1/`. |
| Current R0.5 machine gate | **PASS** — documentation/contract, finding and architecture checks pass; human gate remains separately `NOT_EVALUATED` by the runner. |
| Unresolved blocking finding fixture | **PASS** — `blocking=true` with open, accepted or deferred status returns `BLOCKED` when due; a resolved fixture returns `PASS`. Fixtures were created only in a temporary directory. |
| Phase-scoped future blocker | **PASS** in R1 compatibility rerun — an R4 blocker is tracked without blocking the R0.5 fixture. |
| Invalid finding fixture | **PASS** — a schema-invalid severity returns `FAIL`. |
| Future KiCad checks | **PASS** — R6 returns `BLOCKED`; ERC, interface, pin and BOM hooks report `NOT_AVAILABLE`. No false ERC/DRC PASS is possible with current adapters. |
| Transition contract | **PASS** — R0.5 → R1 is allowed by machine configuration; R0.5 → R5 fails. No state mutation occurs. |

Machine-readable results: [verification_results.json](r0_5/verification_results.json). Validation script: [verify_workflow.py](r0_5/verify_workflow.py). The current gate's command output is reproducible and does not represent approval of electrical design or authorization for R1.

**Limit:** Future KiCad hooks are intentionally unavailable. Documentation checks confirm required artifacts exist; engineering review must still assess their content and evidence. The seven product OPEN decisions remain open and are not falsely encoded as current R0.5 failures.

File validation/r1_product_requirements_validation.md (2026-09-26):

# R1 product-requirements validation

Date: 2026-09-26. Scope: product-document extraction, requirements control and workflow gates only. No component-level verification, schematic, PCB, ERC, DRC or physical test was performed.

Reproduce:

```text
python -m pip install -r workflow/requirements.txt
python validation/r1/verify_product_requirements.py
python workflow/gates/run.py --next-phase R2
```

| Check | Result |
| --- | --- |
| Product source | **PASS** — DOCX hash matches the complete source read at R0; relevant R1 sections/tables were reinspected. Graphify graph and MCP tool were unavailable, so normal repository inspection was used. |
| Requirement and decision control | **PASS** — 49 Board A, Board B, system and interface acceptance rows are classified; all D1–D7 remain explicit and open. No product value was invented. |
| Findings and state | **PASS** — 13 schema-valid, evidenced future blockers have closure criteria and match `state.open_blockers` exactly; none is due by R2. |
| Interface artifact | **PASS** — both boards and 12 intended signal entries are present; MCLK/service remain optional; connector, pin assignment, voltage domains and counts remain unset. |
| R1 machine gate / R2 transition | **PASS** — documentation, findings and architecture checks pass for R1→R2. The runner leaves the human gate `NOT_EVALUATED` and makes no state change. |
| Phase-scoped blocker fixture | **PASS** — changing one blocker to be due at R2 in a temporary fixture returns `BLOCKED` for R1→R2. |
| Future KiCad hooks | **PASS** — the R6 gate is blocked and unimplemented ERC/interface/pin/BOM hooks report `NOT_AVAILABLE`; no false KiCad PASS. |
| KiCad scope | **PASS** — Product V1 board directories contain no KiCad artifacts; no legacy KiCad file was edited in R1. |

Reproducible results: [verification_results.json](r1/verification_results.json); script: [verify_product_requirements.py](r1/verify_product_requirements.py).

**Remaining limits:** Product-level requirements and staged blockers are controlled, but target-device feasibility, analog/electrical values, speaker/headroom measurements, crib mechanics and safety SPL criteria remain open. R1 PASS permits a separately authorized R2 verification phase; it is not a schematic or production release.

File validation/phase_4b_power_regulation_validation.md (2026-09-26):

# Phase 4B power regulation / sequencing validation

Date: 2026-09-13. **Implementation stopped before schematic changes.**

## Blocking finding: supervisor release margins

**CONFLICTING:** [Phase 3](../docs/phases/phase_3_schematic_readiness.md) sections 6.1-6.2 freeze TPS386000RGPR dividers and require deterministic startup. Section 6.1 checks falling thresholds against the realized rail minima, but omits positive-going hysteresis from the startup qualification. [TI TPS386000/TPS386040, SBVS105F Rev.F](../datasheets/power/tps386000_datasheet_rev_f.pdf), section 6.5 p.7, specifies `VITN = 396-404 mV` and `VHYSN = 3.5 mV typical, 10 mV maximum`. Figure 3 p.9 and section 8.3.4 p.23 establish release at the upper hysteresis boundary. The 14-24 ms delay begins after qualification; waiting longer cannot qualify a rail below that boundary. The electrical table and timing diagram were visually inspected.

For each frozen 0.1% divider, even with **zero sense current**:
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

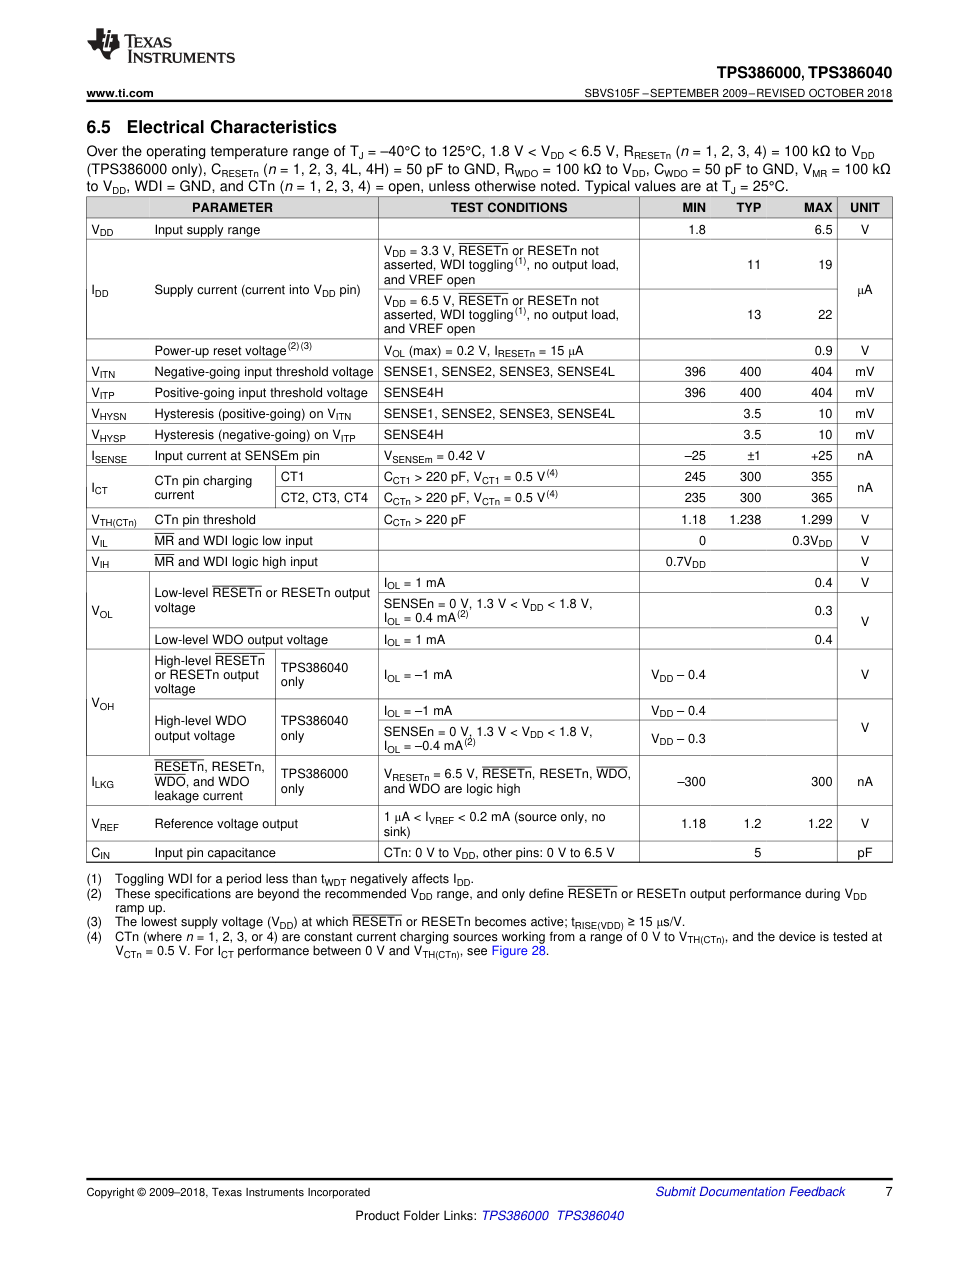
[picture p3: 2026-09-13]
validation/phase_4b/tps386000_p7.png

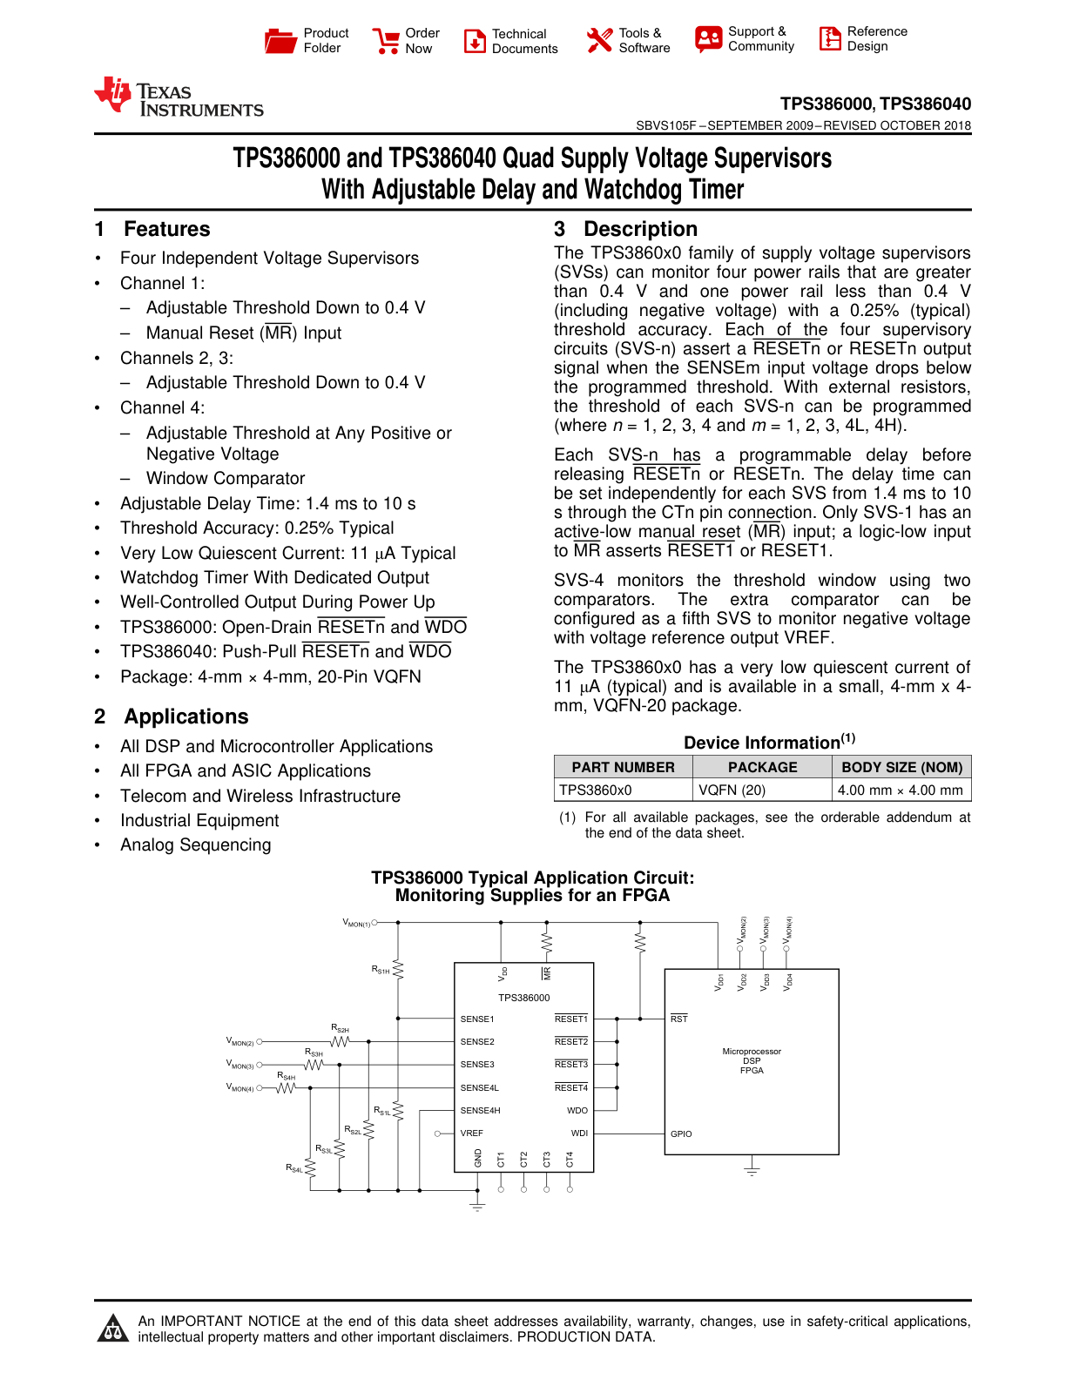
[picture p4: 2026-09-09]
validation/phase_3/rendered/tps386000_datasheet_rev_f_p1.png

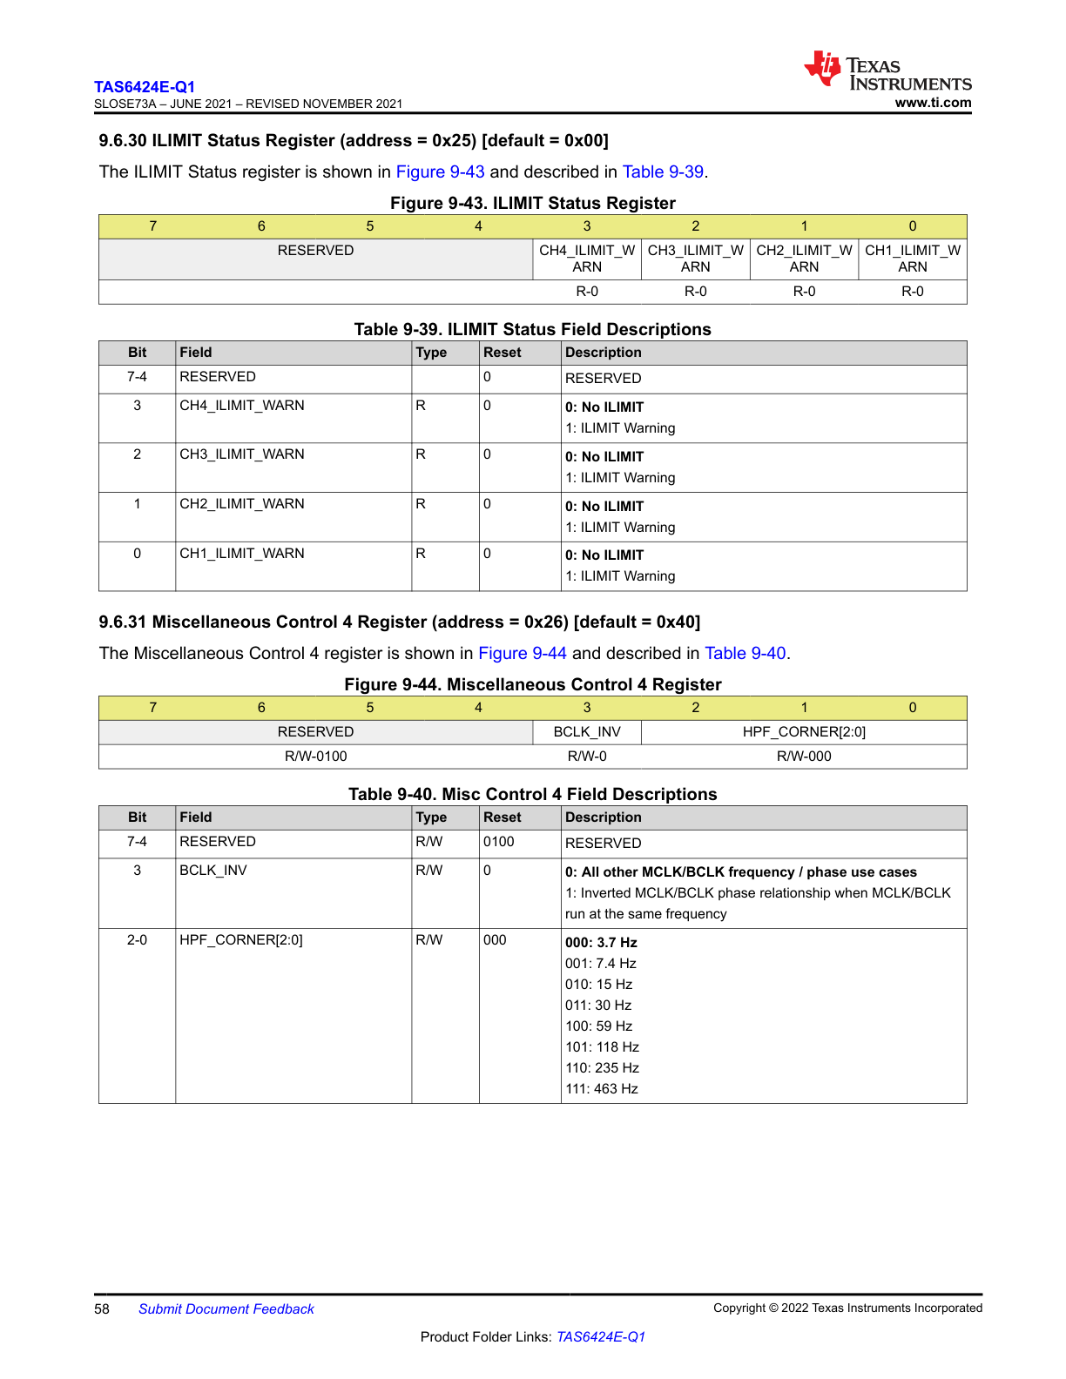
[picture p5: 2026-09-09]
validation/phase_3/rendered/tas6424e-q1_datasheet_rev_a_p58.png

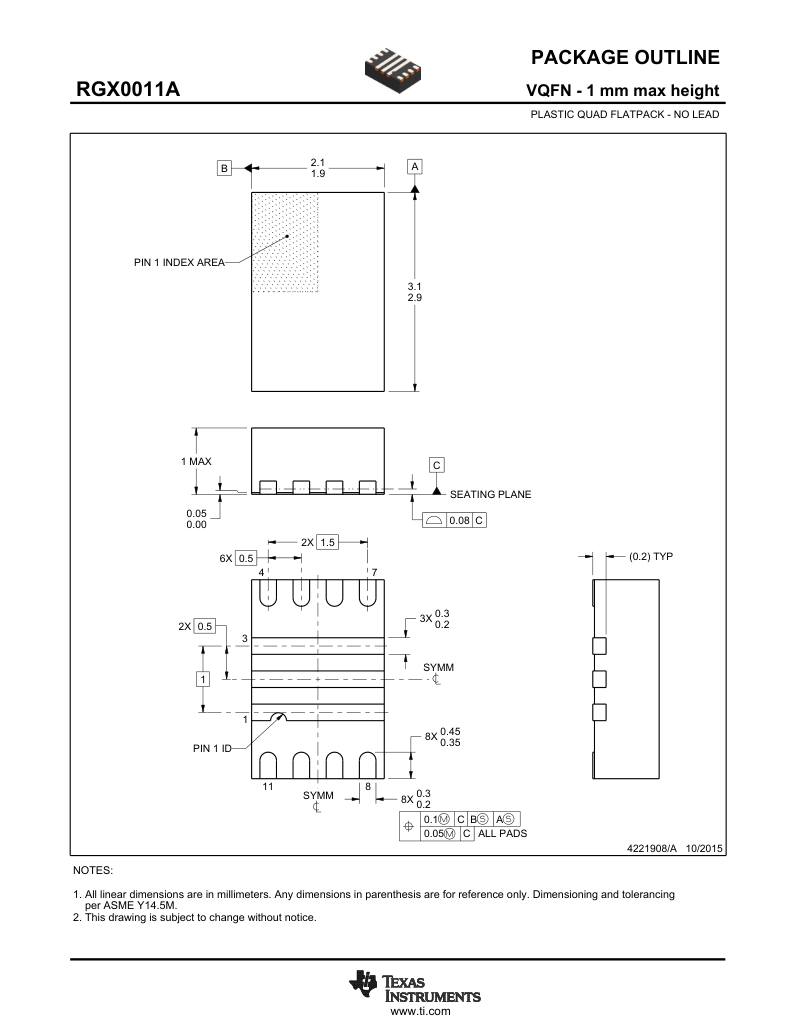
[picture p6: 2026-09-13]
validation/phase_4b/tps62135_impl_p44.png

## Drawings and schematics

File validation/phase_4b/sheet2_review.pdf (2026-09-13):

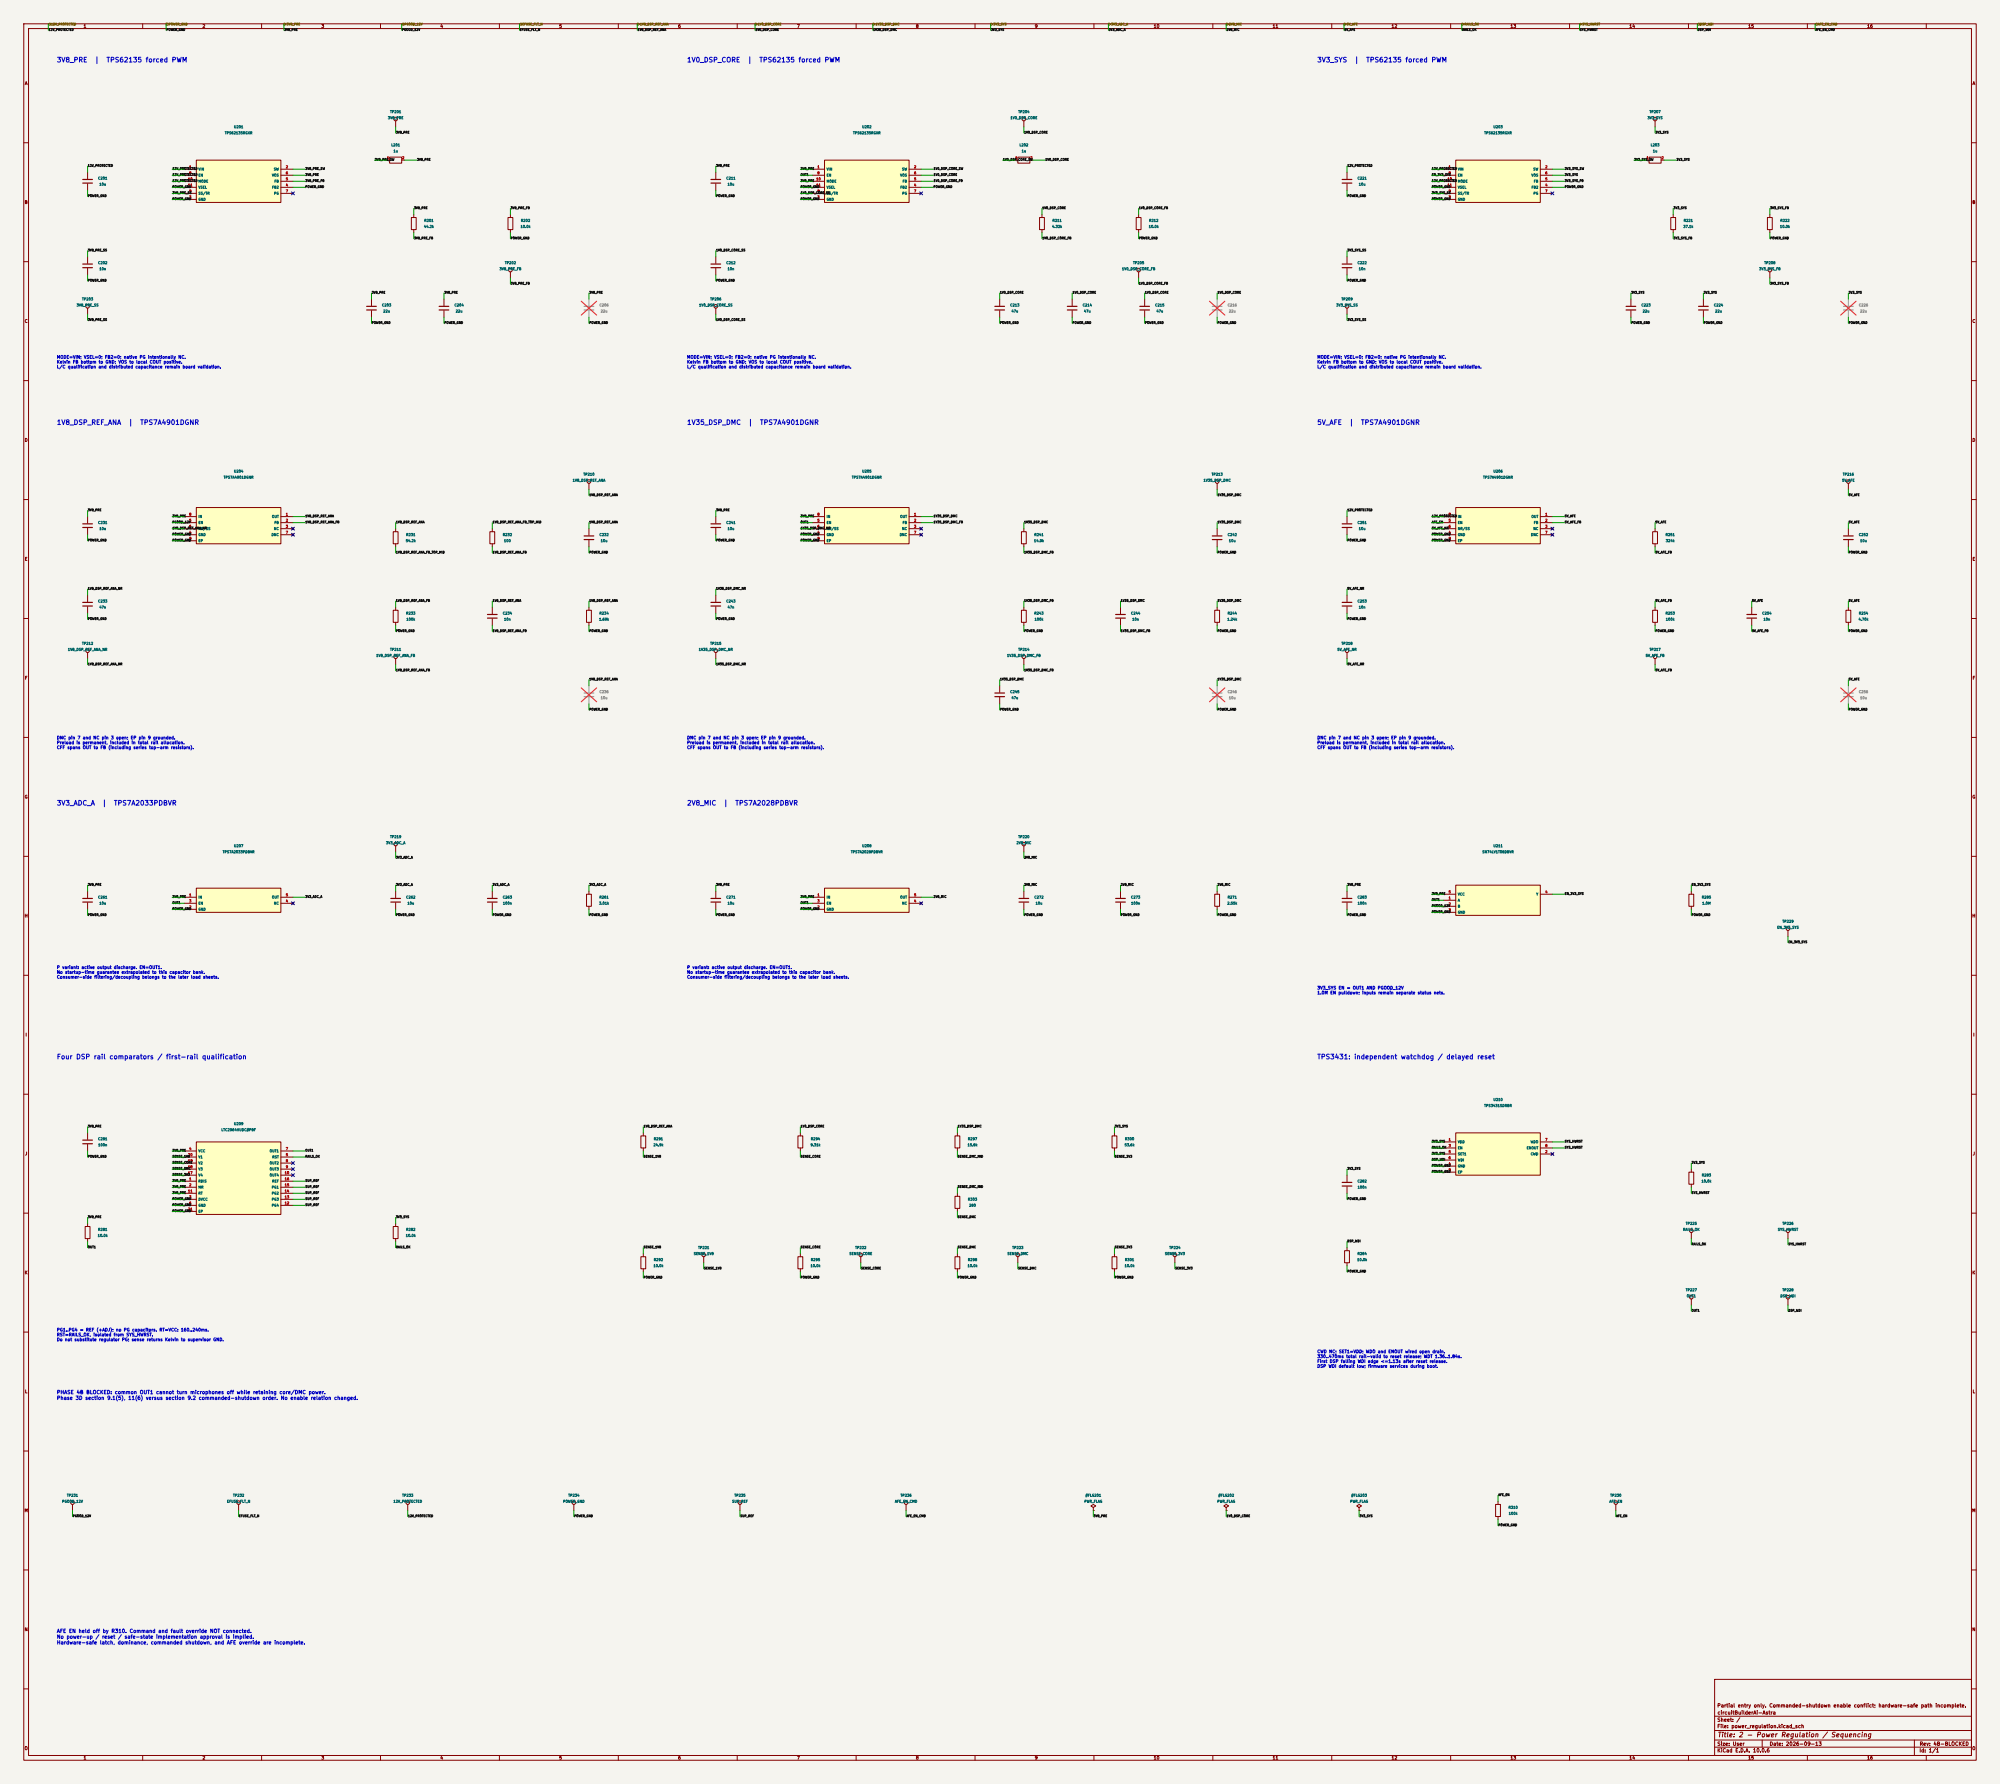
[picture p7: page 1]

MODE=VIN; VSEL=0; FB2=0; native PG intentionally NC. Kelvin FB bottom to GND; VOS to local COUT positive.

L/C qualification and distributed capacitance remain board validation.

DNC pin 7 and NC pin 3 open; EP pin 9 grounded. Preload is permanent, included in total rail allocation. CFF spans OUT to FB (including series top-arm resistors).

P variant: active output discharge. EN=OUT1. No startup-time guarantee extrapolated to this capacitor bank. Consumer-side filtering/decoupling belongs to the later load sheets.

Four DSP rail comparators / first-rail qualification

PG1..PG4 = REF (+ADJ); no PG capacitors. RT=VCC: 160..240ms. RST=RAILS_OK, isolated from SYS_HWRST. Do not substitute regulator PG; sense returns Kelvin to supervisor GND.

CWD NC; SET1=VDD; WDO and ENOUT wired open drain. 330..470ms total rail-valid to reset release; WDT 1.36..1.84s. First DSP falling WDI edge <=1.13s after reset release. DSP WDI default low; firmware services during boot.

PHASE 4B BLOCKED: common OUT1 cannot turn microphones off while retaining core/DMC power.
Phase 3D section 9.1(5), 11(6) versus section 9.2 commanded-shutdown order. No enable relation changed.

AFE EN held off by R310. Command and fault override NOT connected.
No power-up / reset / safe-state implementation approval is implied.
Hardware-safe latch, dominance, commanded shutdown, and AFE override are incomplete.

Partial entry only. Commanded-shutdown enable conflict; hardware-safe path incomplete.
circuitBuilderAi-Astra
Sheet: /
File: power_regulation.kicad_sch
Title: 2 - Power Regulation / Sequencing

Size: User | Rev: 4B-BLOCKED | O Date: 2026-09-13
KiCad E.D.A. 10.0.6 | Id: 1/1

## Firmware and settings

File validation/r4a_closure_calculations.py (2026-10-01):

"""Focused Board A R4-A corner calculations. Assumptions are named, not certified."""

from math import atan, degrees, pi


def calculate_load_power() -> dict:
    """Board A sizing envelope; design allocations are not device current maxima."""
    # NXP IMXRT1060CEC Rev 4 Table 12, p.28. The I/O banks are excluded.
    mcu_pins_ma = {"DCDC_IN": 110, "VDD_HIGH_IN": 50,
                   "VDDA_ADC_3P3": 40, "VDD_SNVS_IN": 0.25}
    # Infineon v1.20 Table 7 p.10: 230 uA only for input <=94 dBSPL.
    # TI SBOS513F p.9: OPA2320 1.7 mA/channel, no output load, -40..125 C.
    # LDO tolerance specifies IOUT >=1 mA. 2.2k/1.5k/2.7k, 1% bleeders
    # on MIC/FLASH/ADC guarantee the minimum load even with ICs asleep.
    mic_ma = 4 * 1.0 + 1.31 + 1.69
    opa_iq_ma = 8 * 1.7
    adc_afe_ma = 50 + opa_iq_ma + 4 + 2 + 5.4
    flash_ma = 30 + 15 + 15  # ISSI core max + SD1 I/O and transient allocations
    assert adc_afe_ma == 75 and flash_ma == 60
    # NVCC_GPIO/EMC switched load, ADC IOVDD, straps, supervisor, downstream
    # LDO input and buck output transient. No unstated USB bus-power load.
    ldo_gnd_ma = 2  # engineering bound per LDO; TI 2 mA is typical at 300 mA
    mcu_buck_ma = (sum(mcu_pins_ma.values()) + 20 + 5 + 5 + 1
                   + mic_ma + flash_ma + 2 * ldo_gnd_ma + 20)
    buck_ceiling_ma = 350  # below output capability and above itemized allocation
    assert mcu_buck_ma <= buck_ceiling_ma
    buck_vmax = 3.4259
    adc_vmin = 3.2505
    ldo_theta = 166.1
    buck_theta = 38.4
    ambient = 85
    eta_floor = .70  # imposed design acceptance floor, not TI guarantee
    buck_pout_w = buck_vmax * buck_ceiling_ma / 1000
    buck_loss_w = buck_pout_w * (1 / eta_floor - 1)
    input_ma = buck_pout_w / (eta_floor * 4.5) * 1000 + adc_afe_ma + ldo_gnd_ma + 25 + 10
    adc_loss_w = (5.5 - adc_vmin) * adc_afe_ma / 1000 + 5.5 * ldo_gnd_ma / 1000
    mic_loss_w = (3.4259 - 2.758) * mic_ma / 1000 + 3.4259 * ldo_gnd_ma / 1000
    flash_loss_w = (3.4259 - 1.770) * flash_ma / 1000 + 3.4259 * ldo_gnd_ma / 1000
    mcu_pkg_w = buck_vmax * (110 + 50 + 40 + .25 + 20) / 1000
    adc_pkg_w = 3.3495 * (50 + 5) / 1000
    opa_pkg_w = 3.3495 * (2 * 1.7 + 1) / 1000
    return {
        "mcu_pin_max_ma": mcu_pins_ma,
        "mcu_io_and_misc_design_ma": {"gpio_emc_switching": 20, "adc_iovdd": 5,
            "boot_pulls_and_debug": 5, "supervisor": 1,
            "mic_ldo_output": mic_ma, "flash_ldo_output": flash_ma,
            "two_ldo_ground_current": 2 * ldo_gnd_ma,
            "output_transient": 20},
        "mcu_buck_itemized_ma": mcu_buck_ma,
        "mcu_buck_design_ceiling_ma": buck_ceiling_ma,
        "mcu_buck_unallocated_ma": round(buck_ceiling_ma - mcu_buck_ma, 2),
        "mic_design_ceiling_ma": mic_ma,
        "opa_eight_channel_iq_max_ma": opa_iq_ma,
        "adc_afe_design_ceiling_ma": adc_afe_ma,
        "flash_design_ceiling_ma": flash_ma,
        "adc_afe_tj_c_at_85c": round(ambient + adc_loss_w * ldo_theta, 2),
        "adc_afe_tj_margin_to_125c": round(125 - ambient - adc_loss_w * ldo_theta, 2),
        "mic_ldo_tj_c_at_85c": round(ambient + mic_loss_w * ldo_theta, 2),
        "flash_ldo_tj_c_at_85c": round(ambient + flash_loss_w * ldo_theta, 2),
        "mcu_pkg_tj_c_at_85c_reference_39p1cw": round(ambient + mcu_pkg_w * 39.1, 2),
        "adc_pkg_tj_c_at_85c_reference_32p6cw": round(ambient + adc_pkg_w * 32.6, 2),
        "opa_pkg_tj_c_at_85c_reference_174p8cw": round(ambient + opa_pkg_w * 174.8, 2),
        "gpio_25pins_30pf_12p288mhz_ma": round(25 * 30e-12 * buck_vmax * .5 * 12.288e6 * 1000, 2),
        "sd1_6pins_30pf_30mhz_ma": round(6 * 30e-12 * 1.83 * .5 * 30e6 * 1000, 2),
        "buck_output_w": round(buck_pout_w, 4),
        "buck_loss_w_at_assumed_70pct_eta": round(buck_loss_w, 4),
        "buck_tj_c_at_85c_assumed_eta": round(ambient + buck_loss_w * buck_theta, 2),
        "buck_tj_margin_to_125c_assumed_eta": round(125 - ambient - buck_loss_w * buck_theta, 2),
        "input_design_ma_at_4p5v": round(input_ma, 2),
        "input_margin_to_750ma_ma": round(750 - input_ma, 2),
        "input_startup_and_step_extra_design_ma": 200,
        "input_design_with_startup_ma": round(input_ma + 200, 2),
        "input_margin_with_startup_to_750ma_ma": round(750 - input_ma - 200, 2),
        "mic_bleeder_min_ma": round(2.758 / (2200 * 1.01) * 1000, 3),
        "flash_bleeder_min_ma": round(1.770 / (1500 * 1.01) * 1000, 3),
        "adc_bleeder_min_ma": round(3.2505 / (2700 * 1.01) * 1000, 3),
        "adc_ldo_dissipation_w": round(adc_loss_w, 4),
        "mic_ldo_dissipation_w": round(mic_loss_w, 4),
        "flash_ldo_dissipation_w": round(flash_loss_w, 4),
        "efficiency_floor_is_manufacturer_guaranteed": False,
        "thermal_resistance_is_product_board_guaranteed": False,
    }


def calculate() -> dict[str, float]:
    # TPS62135 SLVSBH3B pp.5-6: PWM VFB +/-1% only if VIN >= VOUT+1 V.
    # 1% divider and 70-nA maximum FB leakage, taken with adverse polarity.
    top, bottom = 255_000.0, 68_100.0
    buck_min = 0.693 * (1 + top * .99 / (bottom * 1.01)) - 70e-9 * top * 1.01
    buck_max = 0.707 * (1 + top * 1.01 / (bottom * .99)) + 70e-9 * top * 1.01
    assert 3.0 < buck_min < buck_max < 3.6

    # NXP HW7 pp.4-6: RC nominal 5-15 ms. Values are component tolerances,
    # not proof of the required >=1 ms delay from DCDC_IN reaching 3.0 V.
    rc_min_ms = 30_000 * .99 * 0.22e-6 * .90 * 1000
    rc_max_ms = 30_000 * 1.01 * 0.22e-6 * 1.10 * 1000
    assert 5 <= rc_min_ms and rc_max_ms <= 15

    # TI TPS7A20 SBVS338H p.6: guaranteed accuracy within stated VIN/load/TJ.
    mic_min, mic_max = 2.8 * .985, 2.8 * 1.015
    flash_min, flash_max = 1.8 - .03, 1.8 + .03
    adc_min, adc_max = 3.3 * .985, 3.3 * 1.015
    assert 2.3 <= mic_min and mic_max <= 3.0
    assert 1.65 <= flash_min and flash_max <= 1.95
    assert 3.0 <= adc_min and adc_max <= 3.6
    assert buck_min >= 3.1  # 2.8-V LDO accuracy VIN condition
    assert buck_min >= 2.3  # 1.8-V LDO accuracy VIN condition

    # TI TPS389030 SLVSD65A pp.3,5: fixed 3.0-V-rail threshold, +/-1%
    # over specified supply and temperature. NXP HW7 p.11 requires reset
    # before its 2.6-V internal DCDC low-voltage detection on power-down.
    por_fall_min = 2.89 * .99
    por_rise_max = 2.907 * 1.01
    assert por_fall_min > 2.6 and buck_min > por_rise_max
    por_ct_delay_min_ms = 9e-9 * 1.17 / 1.35e-6 * 1000
    por_ct_delay_max_ms = 11e-9 * 1.29 / .90e-6 * 1000

    # 10-uF +/-5% film and 20-kohm ADC input: ADC resistance is TYPICAL,
    # so this is a nominal topology calculation, never a worst-case proof.
    coupling_fc_typ_hz = 1 / (2 * pi * 20_000 * 10e-6)
    coupling_fc_5pct_hz = 1 / (2 * pi * 20_000 * 9.5e-6)
    phase_20hz_5pct_deg = degrees(atan(coupling_fc_5pct_hz / 20))

    # Infineon v1.20 pp.6,8,10: sensitivity -37 dBV maximum at 94 dBSPL;
    # extrapolation to 135 dBSPL is a linear-only headroom SCREEN because
    # 135 dBSPL AOP and output DC are typical, not guaranteed bounds.
    mic_135vrms_screen = 10 ** (-37 / 20) * 10 ** ((135 - 94) / 20)
    adc_headroom_db_screen = 20 * __import__("math").log10(2 / mic_135vrms_screen)

    # TPS7A20 DQN thetaJA 166.1 C/W, 3.3-V ADC/AFE LDO design reserve
    # 100 mA, assumed Board A 5-V max 5.5 V, 85 C ambient. This is a
    # reserve check; TI's ADC data gives only typical current at 48 kHz.
    adc_ldo_tj_reserve_c = 85 + (5.5 - adc_min) * .100 * 166.1
    # TI SBAA379 Table 1: a contextual 96-kHz, 4-channel, PLL-on,
    # DRE-off, linear-phase point uses BCLK/FSYNC=96, whereas this board's
    # 12.288-MHz/96-kHz plan uses 128. Its 25.68 mA is typical AVDD only.
    adc_matrix_typical_ma = 25.68

    # NXP CEC Rev 4 Table 22 pp.37-38: GPIO VIH >=0.7 NVCC, VIL <=0.3
    # NVCC; opposing on-chip 100-k pull current <=48 uA plus 1 uA input
    # leakage. External 4.7-k/1-k 1% networks use the worst resistor
    # ratios and opposing 49-uA current. This covers static levels only.
    rail_min, rail_max = buck_min, buck_max
    strap_r_hi, strap_r_lo = 4700 * 1.01, 4700 * .99
    fixture_r_hi, fixture_r_lo = 1000 * 1.01, 1000 * .99
    oppose_a = 49e-6
    normal_high_ratio_min = 1 - oppose_a * strap_r_hi / rail_min
    normal_low_ratio_max = oppose_a * strap_r_hi / rail_min
    recovery_high_v = (rail_min / fixture_r_hi - oppose_a) / (1 / fixture_r_hi + 1 / strap_r_lo)
    recovery_low_v = (rail_max / strap_r_lo + oppose_a) / (1 / strap_r_lo + 1 / fixture_r_lo)
    recovery_high_ratio_min = recovery_high_v / rail_min
    recovery_low_ratio_max = recovery_low_v / rail_max
    assert normal_high_ratio_min > .7 and normal_low_ratio_max < .3
    assert recovery_high_ratio_min > .7 and recovery_low_ratio_max < .3
    fixture_current_max_ma = rail_max / (strap_r_lo + fixture_r_lo) * 1000

    # ISSI IS25WP064A Rev A11, section 9.3 p.94: 30-mA max at 125 C for
    # program, status-write and erase; NORD 50-MHz active read <=12 mA.
    # The output-switching current is explicitly excluded from ICC1, so
    # neither number closes the total 1.8-V rail load budget.
    flash_core_program_erase_max_ma = 30.0
    flash_core_nord_50mhz_max_ma = 12.0

    return {
        "load_power": calculate_load_power(),
        "mcu_3v3_min_v": round(buck_min, 4),
        "mcu_3v3_max_v": round(buck_max, 4),
        "board_a_input_min_for_buck_pwm_v": round(buck_max + 1, 4),
        "dcdc_rc_min_ms": round(rc_min_ms, 4),
        "dcdc_rc_max_ms": round(rc_max_ms, 4),
        "dcdc_in_3v_deadline_at_rc_min_ms": round(.3 * rc_min_ms, 4),
        "mic_2v8_min_v": round(mic_min, 4),
        "mic_2v8_max_v": round(mic_max, 4),
        "flash_1v8_min_v": round(flash_min, 4),
        "flash_1v8_max_v": round(flash_max, 4),
        "adc_3v3_min_v": round(adc_min, 4),
        "adc_3v3_max_v": round(adc_max, 4),
        "por_fall_min_v": round(por_fall_min, 4),
        "por_rise_max_v": round(por_rise_max, 4),
        "por_healthy_rise_margin_v": round(buck_min - por_rise_max, 4),
        "por_dcdc_low_detect_margin_v": round(por_fall_min - 2.6, 4),
        "por_ct_delay_component_min_ms": round(por_ct_delay_min_ms, 3),
        "por_ct_delay_component_max_ms": round(por_ct_delay_max_ms, 3),
        "coupling_fc_typical_adc_hz": round(coupling_fc_typ_hz, 4),
        "coupling_fc_5pct_cap_typical_adc_hz": round(coupling_fc_5pct_hz, 4),
        "coupling_phase_20hz_5pct_cap_typical_adc_deg": round(phase_20hz_5pct_deg, 4),
        "mic_135dbspl_linear_extrapolation_vrms": round(mic_135vrms_screen, 4),
        "adc_135dbspl_headroom_screen_db": round(adc_headroom_db_screen, 4),
        "adc_ldo_tj_at_100ma_reserve_c": round(adc_ldo_tj_reserve_c, 2),
        "adc_ldo_tj_margin_at_100ma_reserve_c": round(125 - adc_ldo_tj_reserve_c, 2),
        "adc_ldo_reserve_to_unlike_clock_typical_ratio": round(100 / adc_matrix_typical_ma, 2),
        "adc_power_matrix_bclk_ratio": 96,
        "selected_audio_bclk_ratio": 128,
        "flash_03h_rom_to_rated_fmax_ratio": round(30 / 50, 2),
        "boot_normal_high_nvcc_ratio_min": round(normal_high_ratio_min, 4),
        "boot_normal_low_nvcc_ratio_max": round(normal_low_ratio_max, 4),
        "boot_fixture_high_nvcc_ratio_min": round(recovery_high_ratio_min, 4),
        "boot_fixture_low_nvcc_ratio_max": round(recovery_low_ratio_max, 4),
        "boot_fixture_opposing_strap_current_max_ma": round(fixture_current_max_ma, 4),
        "flash_core_program_erase_max_ma_at_125c": flash_core_program_erase_max_ma,
        "flash_core_nord_50mhz_max_ma_excluding_io": flash_core_nord_50mhz_max_ma,
    }


if __name__ == "__main__":
    import json
    print(json.dumps(calculate(), indent=2))

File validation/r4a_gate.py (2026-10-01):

"""Focused, read-only R4-A Board A closure gate; writes its validation result."""

import json
import sys
from pathlib import Path

sys.dont_write_bytecode = True
from r4a_closure_calculations import calculate


ROOT = Path(__file__).resolve().parents[1]


def read(path: str) -> dict:
    return json.loads((ROOT / path).read_text(encoding="utf-8"))


def run() -> dict:
    state = read("state/project_state.json")
    active = read("state/active_task.json")
    board = read("state/board_a_schematic_contract.json")
    pins = read("state/rt1062_pin_resource_map.json")
    findings = {n: read(f"validation/findings/PV1-R1-{n}.json") for n in ("001", "002", "012")}
    calc = calculate()
    checks = {
        "scope_is_board_a_001_002_012": (
            active.get("phase") in {"R4-A", "R4-A2"}
            and active.get("scope") == "board_a"
            and (
                active.get("findings") == ["001", "002", "012"]
                or set(active.get("blockers", [])) == {
                    "AFE electrical bounds", "boot hardware",
                    "hardware-relevant recovery policy", "Board A load and thermal proof",
                    "startup and POR proof",
                }
            )
        ),
        "no_kicad_authority": not active.get("constraints", {}).get("modify_kicad") and not state.get("current_kicad_projects"),
        "r5_unauthorized": state.get("current_gate", {}).get("r5_authorized") is False,
        "four_dual_buffers_selected": board.get("microphone_afe", {}).get("r4a_selected_circuit", {}).get("buffer_mpn") == "OPA2320AIDGKR" and board["microphone_afe"]["r4a_selected_circuit"].get("buffer_quantity") == 4,
        "flash_matches_pin_map": board.get("components", {}).get("flash", {}).get("mpn") == pins.get("r4a_board_a_selection", {}).get("flash", {}).get("mpn") == "IS25WP064AJBLE",
        "power_parts_selected": all(x.get("regulator_mpn") for x in board.get("power_tree", {}).get("rails", []) if x.get("name") != "RT1062_CORE_INTERNAL_DCDC"),
        "rail_voltage_corners_in_device_ranges": 3 <= calc["mcu_3v3_min_v"] < calc["mcu_3v3_max_v"] <= 3.6 and 2.3 <= calc["mic_2v8_min_v"] < calc["mic_2v8_max_v"] <= 3 and 1.65 <= calc["flash_1v8_min_v"] < calc["flash_1v8_max_v"] <= 1.95,
        "finding_identity": all(findings[n].get("id") == f"PV1-R1-{n}" and findings[n].get("blocks_from_phase") == "R4" for n in findings),
        "pin_allocations_collision_free": pins.get("collision_check", {}).get("duplicate_pads") is False and pins.get("collision_check", {}).get("duplicate_balls") is False and pins.get("collision_check", {}).get("reserved_overlap") is False,
    }
    requirements = state.get("r4a_closure", {}).get("requirements", [])
    expected = {
        "001_afe_electrical": "SCHEMATIC_ENTRY_BLOCKER",
        "001_afe_bench": "PHYSICAL_BENCH_VALIDATION",
        "002_boot_hardware": "SCHEMATIC_ENTRY_BLOCKER",
        "002_recovery_policy": "SCHEMATIC_ENTRY_BLOCKER",
        "002_tested_boot_image": "FIRMWARE_BRINGUP_VALIDATION",
        "002_recovery_test": "FIRMWARE_BRINGUP_VALIDATION",
        "002_clock_usb_bench": "PHYSICAL_BENCH_VALIDATION",
        "012_a_load_power": "SCHEMATIC_ENTRY_BLOCKER",
        "012_a_startup": "SCHEMATIC_ENTRY_BLOCKER",
        "012_a_bench": "PHYSICAL_BENCH_VALIDATION",
        "012_board_b_interface": "LATER_BOARD_B_OR_INTERFACE_WORK",
    }
    classes = {
        "SCHEMATIC_ENTRY_BLOCKER", "FIRMWARE_BRINGUP_VALIDATION",
        "PHYSICAL_BENCH_VALIDATION", "LATER_BOARD_B_OR_INTERFACE_WORK",
    }
    checks["requirements_classified_once"] = (
        len(requirements) == len(expected)
        and {item.get("id") for item in requirements} == set(expected)
        and all(
            item.get("classification") in classes
            and item.get("classification") == expected.get(item.get("id"))
            and item.get("finding") in findings
            and item.get("id", "").startswith(item.get("finding", "") + "_")
            for item in requirements
        )
    )
    checks["phase_boundary"] = all(
        (item.get("classification") == "SCHEMATIC_ENTRY_BLOCKER")
        == (item.get("blocks_r4a") is True)
        and item.get("required_by_phase") == (
            "R4" if item.get("classification") in {
                "SCHEMATIC_ENTRY_BLOCKER", "LATER_BOARD_B_OR_INTERFACE_WORK"
            } else "R14"
        )
        for item in requirements
    )
    open_schematic = {
        item.get("finding")
        for item in requirements
        if item.get("classification") == "SCHEMATIC_ENTRY_BLOCKER"
        and item.get("status") != "closed"
    }
    power = board.get("power_tree", {})
    load = power.get("load_budget_a") or {}
    lp = calc["load_power"]
    load_rails = {item.get("name"): item for item in load.get("rails", [])}
    checks["012_load_all_rails_itemized"] = (
        set(load_rails) == {"MCU_3V3", "ADC_AVDD_3V3", "MIC_2V8", "FLASH_SD1_1V8"}
        and load_rails["MCU_3V3"].get("itemized_ma") == lp["mcu_buck_itemized_ma"]
        and load_rails["MCU_3V3"].get("design_ceiling_ma") == lp["mcu_buck_design_ceiling_ma"]
        and load_rails["ADC_AVDD_3V3"].get("design_ceiling_ma") == lp["adc_afe_design_ceiling_ma"]
        and load_rails["MIC_2V8"].get("design_ceiling_ma") == lp["mic_design_ceiling_ma"]
        and load_rails["FLASH_SD1_1V8"].get("design_ceiling_ma") == lp["flash_design_ceiling_ma"]
    )
    five = load.get("five_volt_input", {})
    checks["012_input_and_thermal_screen_consistent"] = (
        five.get("calculated_ma_at_4p5v_and_70pct_buck_efficiency") == lp["input_design_ma_at_4p5v"]
        and five.get("calculated_with_startup_ma") == lp["input_design_with_startup_ma"]
        and five.get("margin_to_design_ceiling_ma") == lp["input_margin_with_startup_to_750ma_ma"]
        and lp["adc_afe_tj_c_at_85c"] < 125
        and lp["buck_tj_c_at_85c_assumed_eta"] < 125
        and lp["efficiency_floor_is_manufacturer_guaranteed"] is False
        and lp["thermal_resistance_is_product_board_guaranteed"] is False
        and load.get("status") == "CALCULATED_ENGINEERING_ENVELOPE_PENDING_COMPONENT_AND_THERMAL_PROOF"
    )
    checks["contract_readiness_consistent"] = (
        ("001" in open_schematic or board.get("microphone_afe", {}).get("status") == "READY")
        and ("002" in open_schematic or pins.get("status") == "READY")
        and (
            "012" in open_schematic
            or (
                power.get("load_budget_a") is not None
                and all(rail.get("status") == "READY" for rail in power.get("rails", []))
                and power.get("sequence_verified") is True
            )
        )
    )
    checks["finding_readiness_consistent"] = all(
        n in open_schematic or findings[n].get("blocking") is False
        for n in ("001", "002")
    )
    policy = pins.get("r4a_board_a_selection", {}).get("boot_straps", {}).get("v1_policy", {})
    recovery_closed = any(
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

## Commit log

2026-09-06 Initialize project structure and Phase 0 spec
    Create the initial repository skeleton and core project documentation, including the requirements freeze for Phase 0 and the workspace directories for datasheets, hardware, references, and validation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
2026-09-08 Add Phase 2 system architecture freeze
    Add the Phase 2 architecture freeze document for the 4-input/4-output ANC controller. It records the provisional candidate signal chain, 96 kHz TDM4 timing, clock and reset strategy, power-domain assumptions, control-bus allocation, and the remaining schematic-entry blockers and product-level unknowns that must be resolved before detailed design.
2026-09-09 phase 4
    [adau1978_adc.kicad_sch, adsp21569_dsp.kicad_sch, circuitBuilderAi-Astra.kicad_sch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]
2026-09-13 Fix power supervisor and 3.3V regulator contracts
    Correct power supervision and 3.3 V regulator contracts and add validation artifacts. Adds three TI/Analog supervisor/watchdog datasheets to datasheets/power, updates docs/evidence/component_evidence_index.md and docs/phases/phase_3_schematic_readiness.md, and introduces Phase 3B and 3C correction records. Adds Phase 4B validation scripts, JSON results, images, and a validation summary (validation/phase_4b/*). Changes document the switch to LTC2964 + TPS3431 watchdog, reroute TPS62135 VIN to 12V_PROTECTED with an AND enable gate, and record the blocking/resolution state.
2026-09-13 phase 4c
    [circuitBuilderAi-Astra.kicad_sch, power_regulation.kicad_sch]
2026-09-26 before-rebuilding
    Last changes before rebuilding PCB design
    [circuitBuilderAi-Astra.kicad_sch, power_regulation.kicad_sch]
2026-09-30 Add Product V1 phase R2-R4 architecture docs
    This change adds the Product V1 evidence index, phase R2/R3/R4 reports, structured state contracts, and validation artifacts for the two-board architecture. It records the provisional component appro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
2026-10-01 Add Board A R4-A closure gate
    This change adds the focused Board A R4-A closure package: selected AFE, boot, and power circuit baselines; updated project-state and finding evidence; and the validation gate/calculations that docum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
